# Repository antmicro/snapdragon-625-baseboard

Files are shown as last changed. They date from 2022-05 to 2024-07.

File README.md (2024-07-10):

# Antmicro's open source SC606T (Snapdragon 625) Baseboard

Copyright (c) 2022-2024 [Antmicro](https://www.antmicro.com)



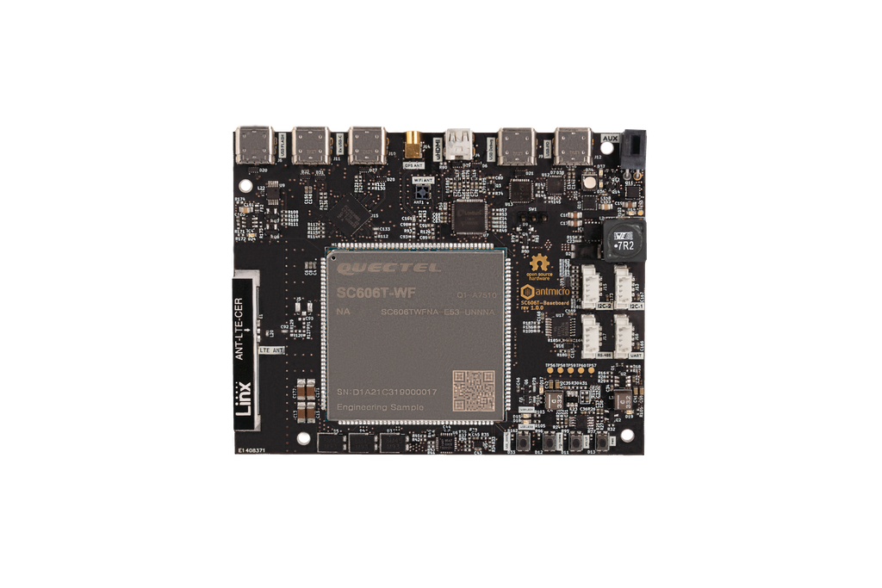
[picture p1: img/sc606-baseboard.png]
Baseboard visualization


## Overview

This repository contains open hardware design files for an experimental development board for Quectel [SC606T Smart Module](https://www.quectel.com/product/lte-sc606t-smart-module-series) featuring Qualcomm [Snapdragon 625 Mobile Platform](https://www.qualcomm.com/products/application/smartphones/snapdragon-6-series-mobile-platforms/snapdragon-625-mobile-platform).
This development board break-routes the relevant I/O interfaces from the smart module keeping a small mechanical outline. 
The design files were prepared in KiCad 7.

## Repository structure

The main repository directory contains KiCad PCB project files, a LICENSE and README.
The remaining files are stored in the following directories:

* `img` - contains graphics for this README
* `doc` - contains schematics in PDF format
* `assets` - contains visual assets for showcasing this design on [Open Hardware Portal](https://openhardware.antmicro.com).

## Key Features

* Quectel SC606T Smart Module with Qualcomm Snapdragon 625
* Built-in Dual-Band WiFi and Bluetooth
* Built-in Cat 6 LTE modem with multi-constellation GNSS receiver
* HDMI output implemented with on-board DSI-HDMI bridge
* DSI interface exposed on Flexible Flat Cable (FFC) connector
* USB 3.0 (Type-C) connector supporting host/otg mode
* 2x 4-lane MIPI CSI-2 camera interface

The board supports multiple power supply scenarios including:

* USB-C PD (Power Delivery)
* External PSU or battery

The on-board camera connector is electrically compatible with several video accessories created by Antmicro such as:
 
* [OV9281 Dual Camera Board](https://github.com/antmicro/ov9281-camera-board)
* [SDI-MIPI bridge](https://github.com/antmicro/sdi-mipi-bridge)
* [HDMI-MIPI bridge](https://github.com/antmicro/hdmi-mipi-bridge)

## License

[Apache-2.0](LICENSE)

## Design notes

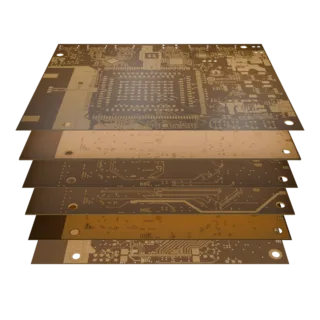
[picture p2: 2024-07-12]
assets/previews/layer1_thumbnail.webp

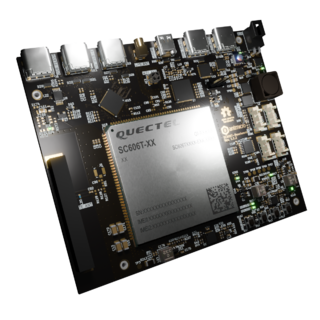
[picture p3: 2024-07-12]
assets/previews/leftT_thumbnail.png

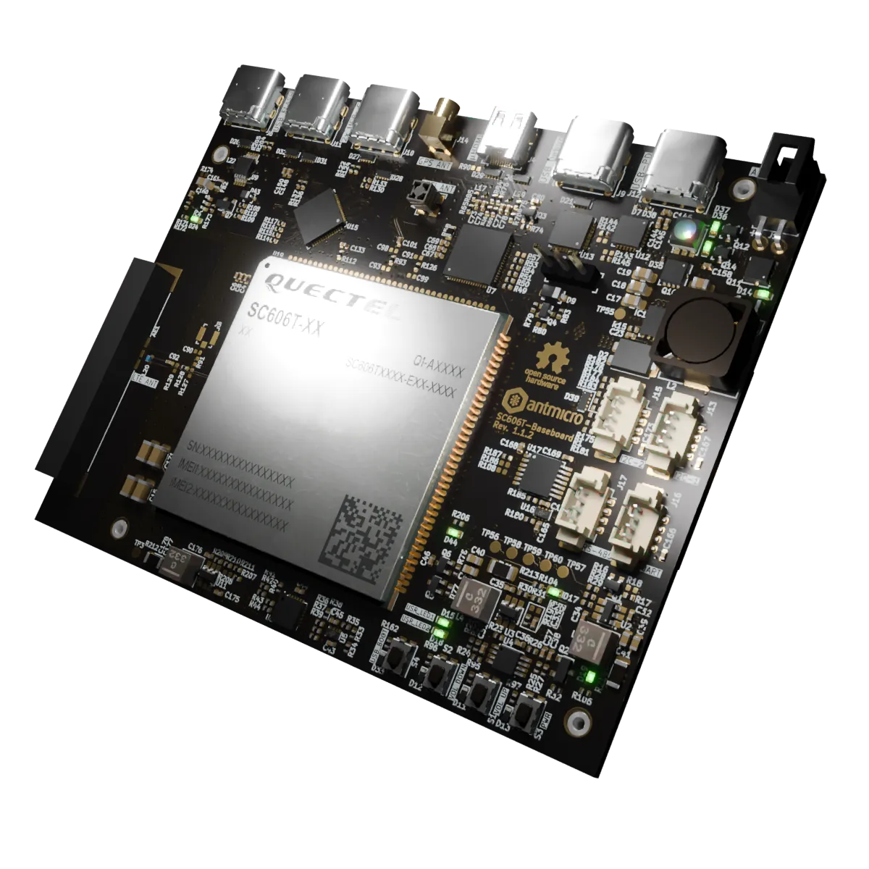
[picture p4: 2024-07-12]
assets/previews/rightT.webp

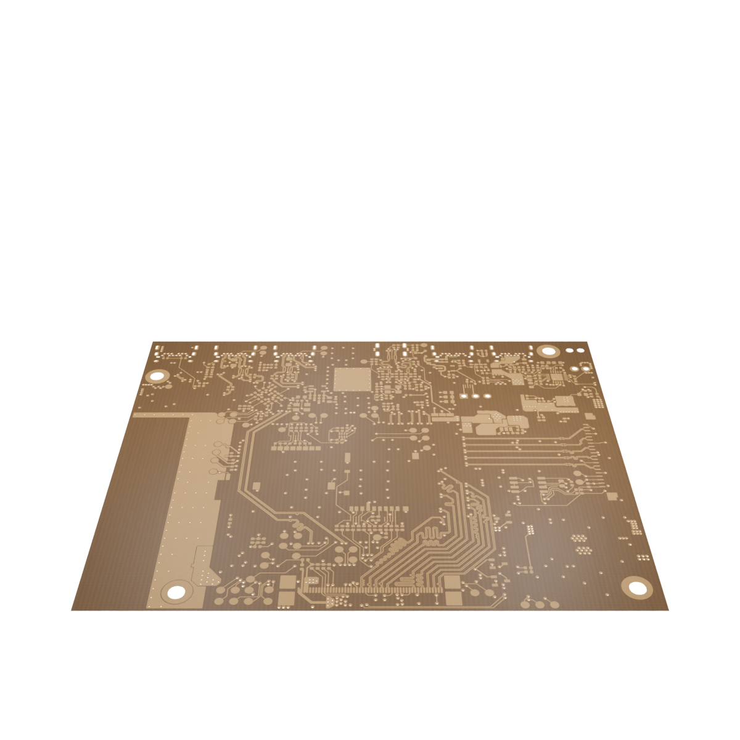
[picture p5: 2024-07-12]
assets/previews/layer6.png

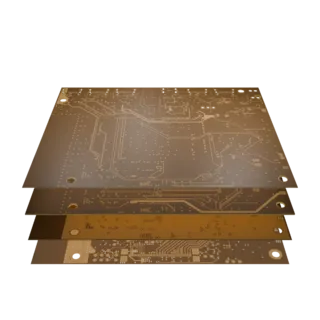
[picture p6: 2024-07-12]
assets/previews/layer3_thumbnail.webp

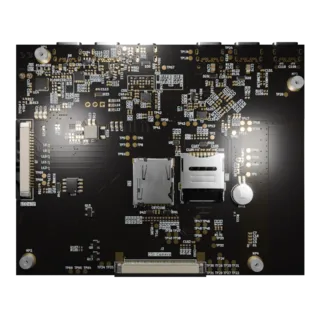
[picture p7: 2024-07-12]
assets/previews/orthoB_thumbnail.webp

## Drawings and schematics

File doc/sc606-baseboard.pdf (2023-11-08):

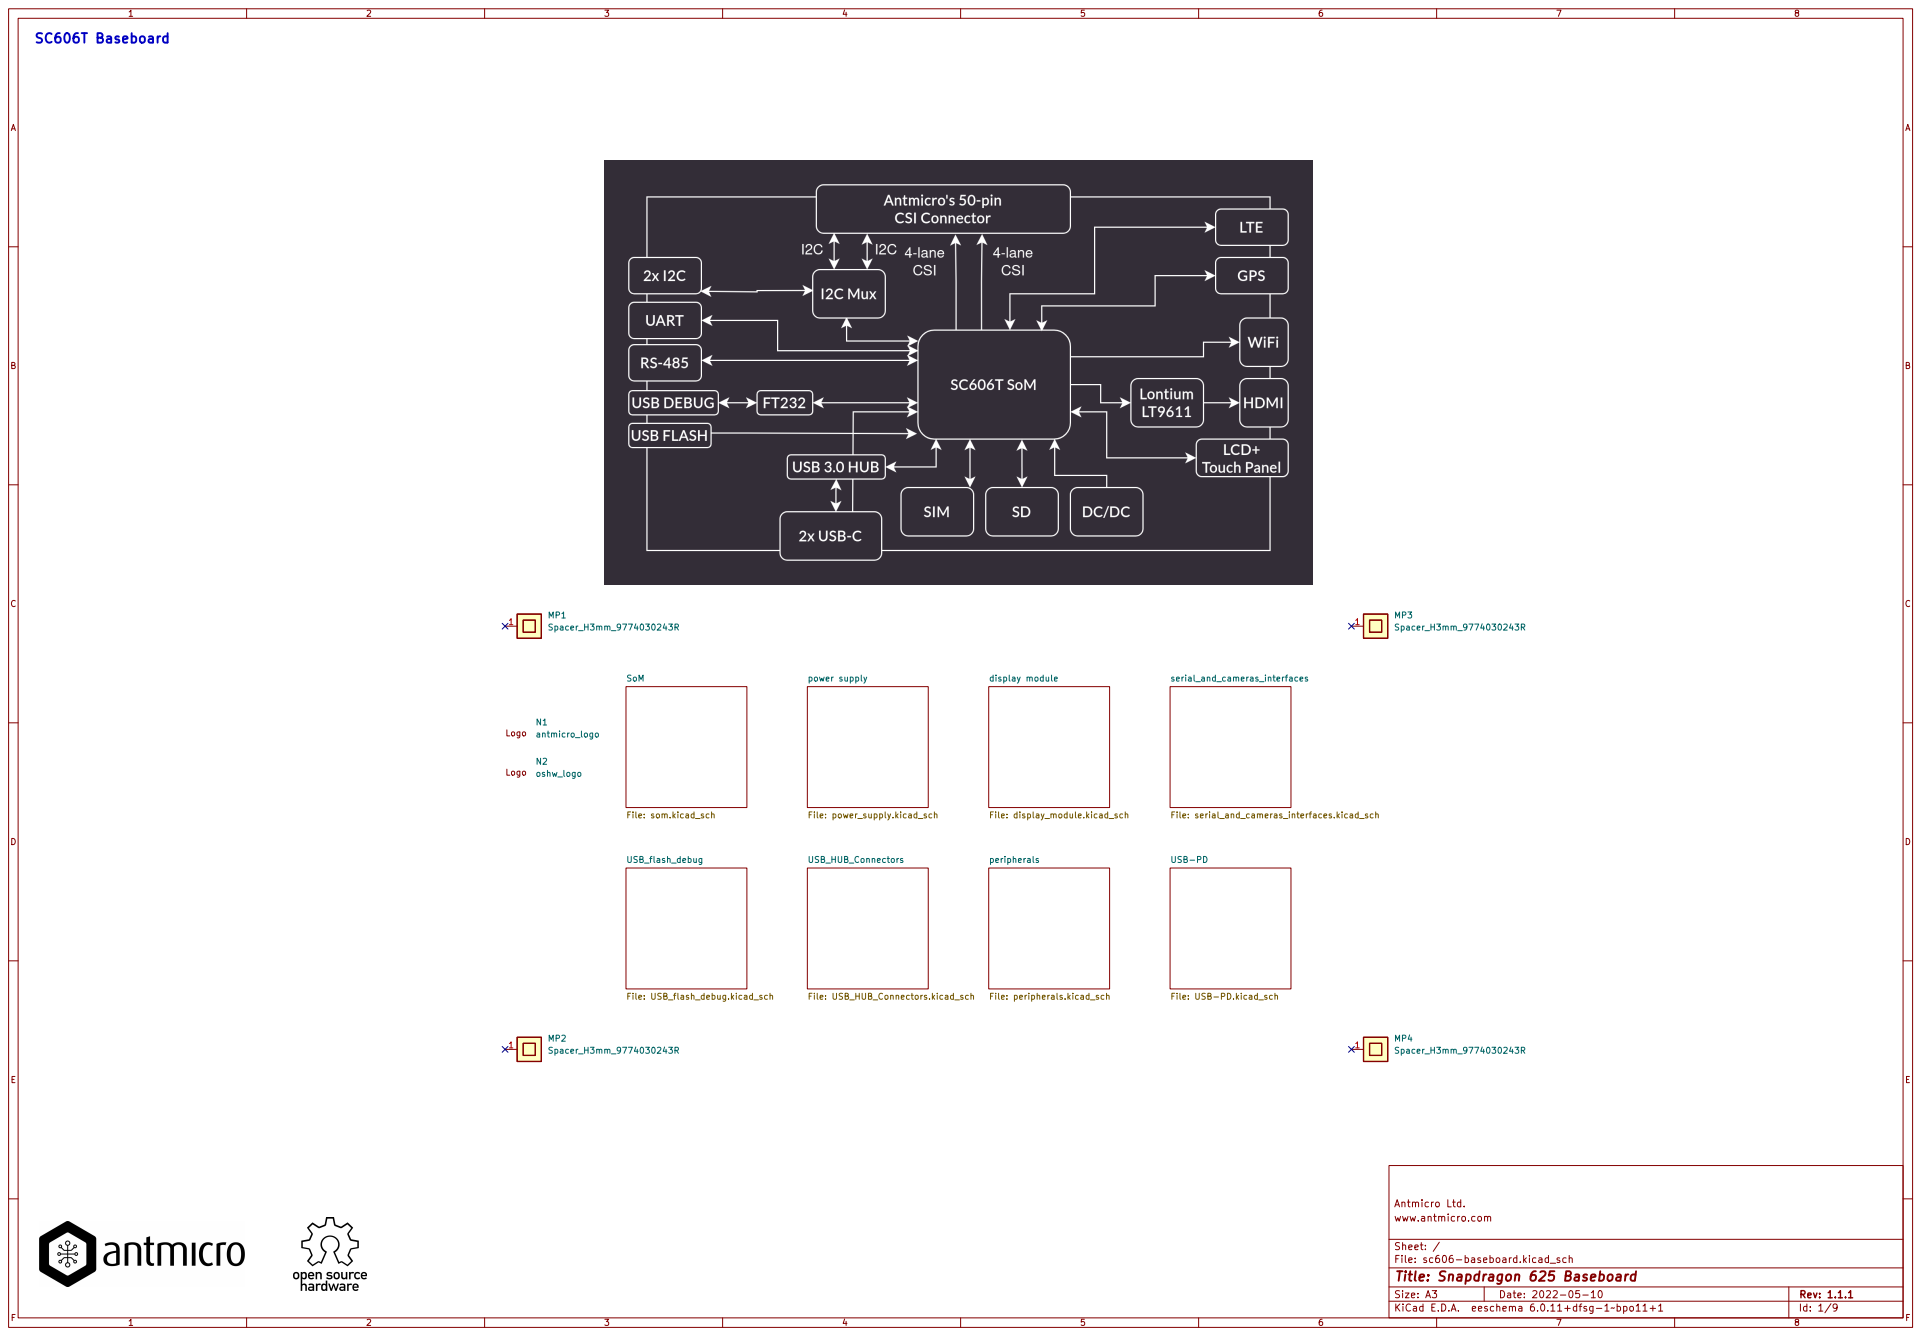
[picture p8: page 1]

display module File: display_module.kicad_sch SoM

File: USB-PD.kicad_sch USB_HUB_Connectors File: USB_HUB_Connectors.kicad_sch

File: sc606-baseboard.kicad_sch Sheet: / www.antmicro.com

Id: 1/9 Title: Snapdragon 625 Baseboard

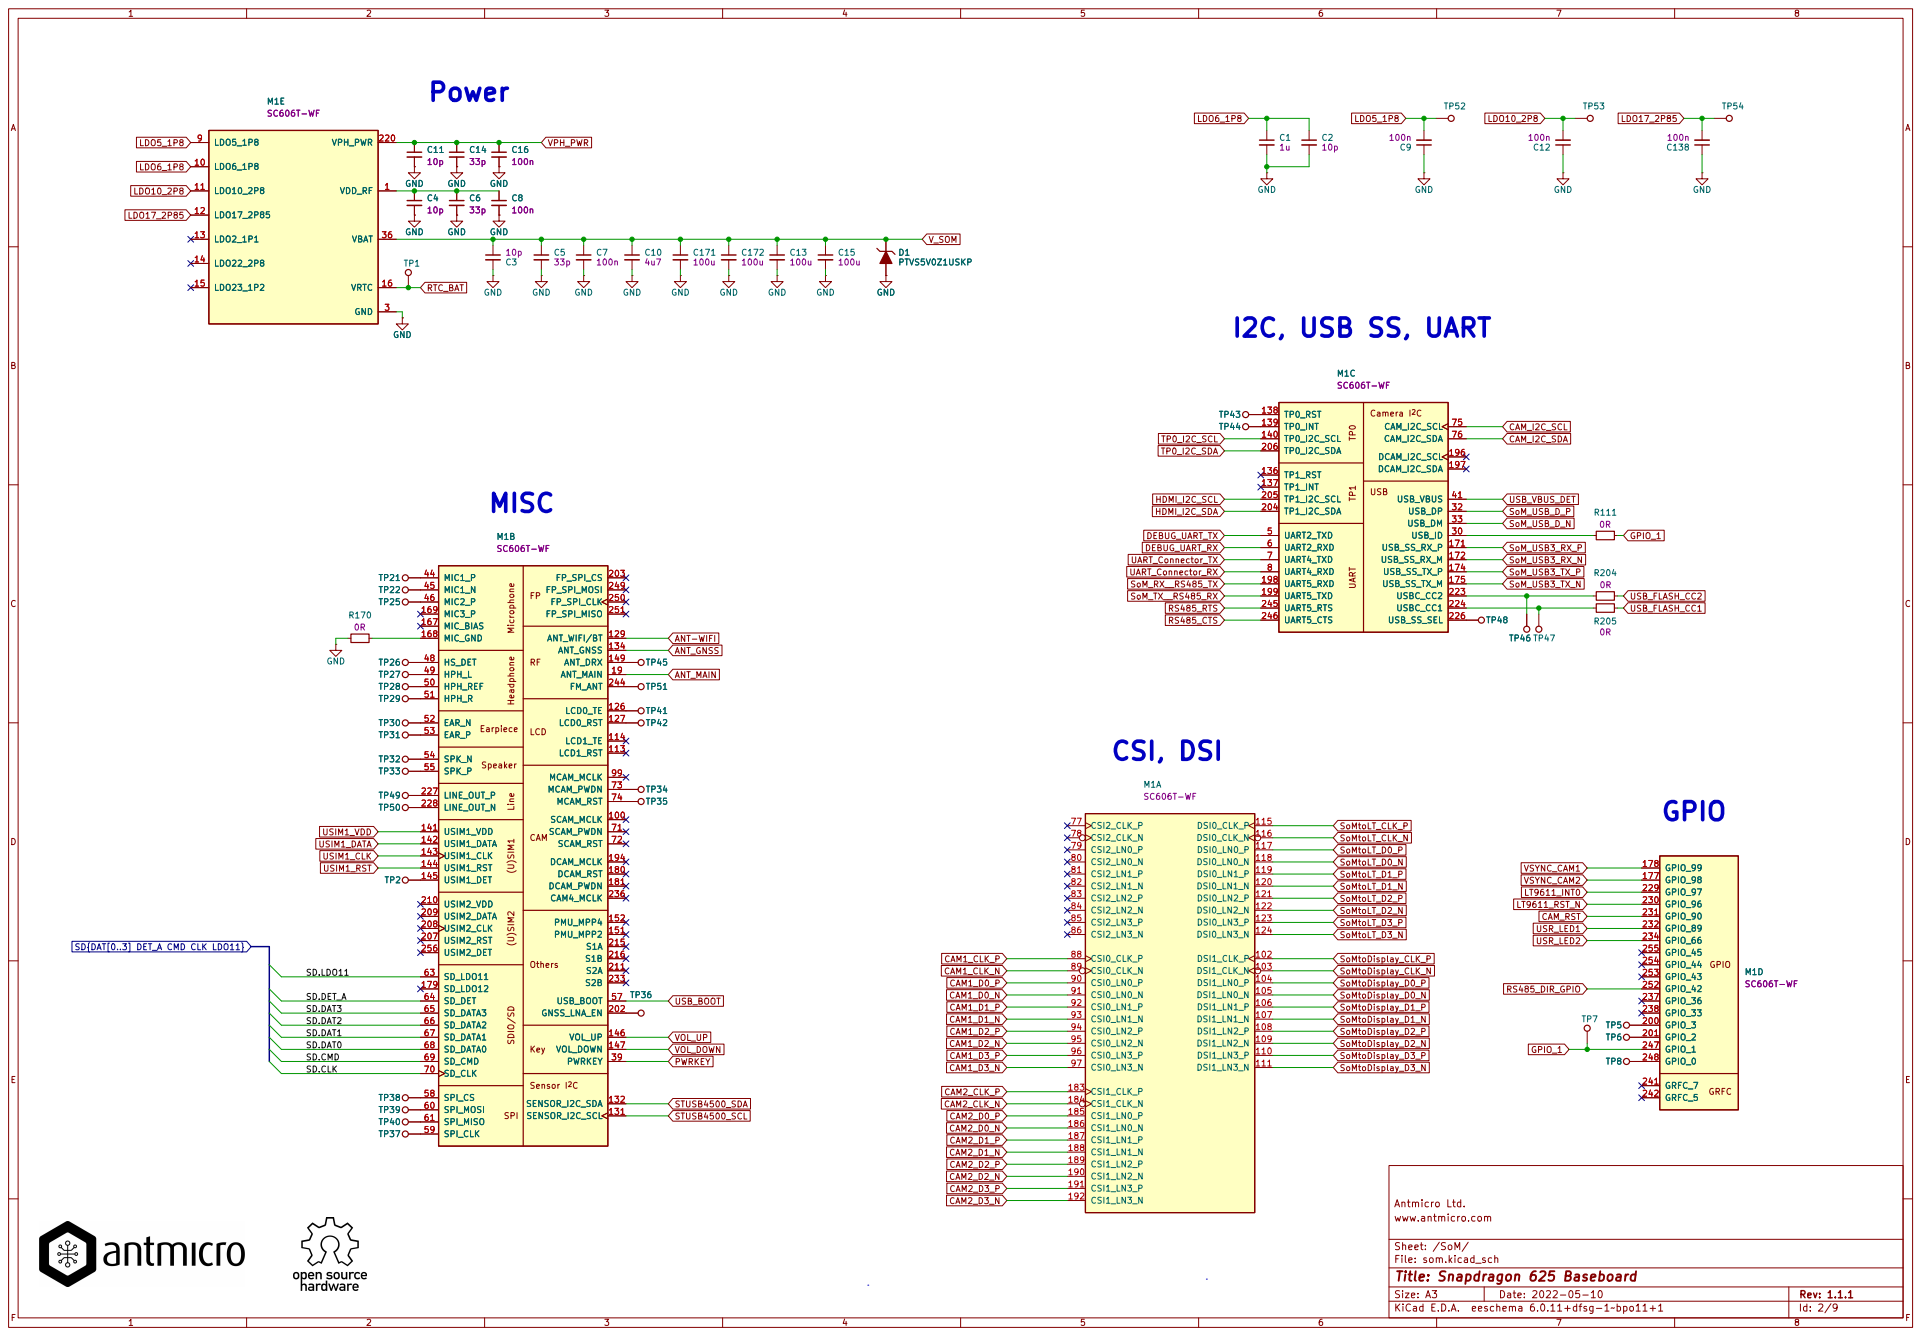
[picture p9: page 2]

SD.DAT2 SD.DAT1 SD.DAT0 SD.CMD

File: som.kicad_sch Sheet: /SoM/ www.antmicro.com

Id: 2/9 Title: Snapdragon 625 Baseboard

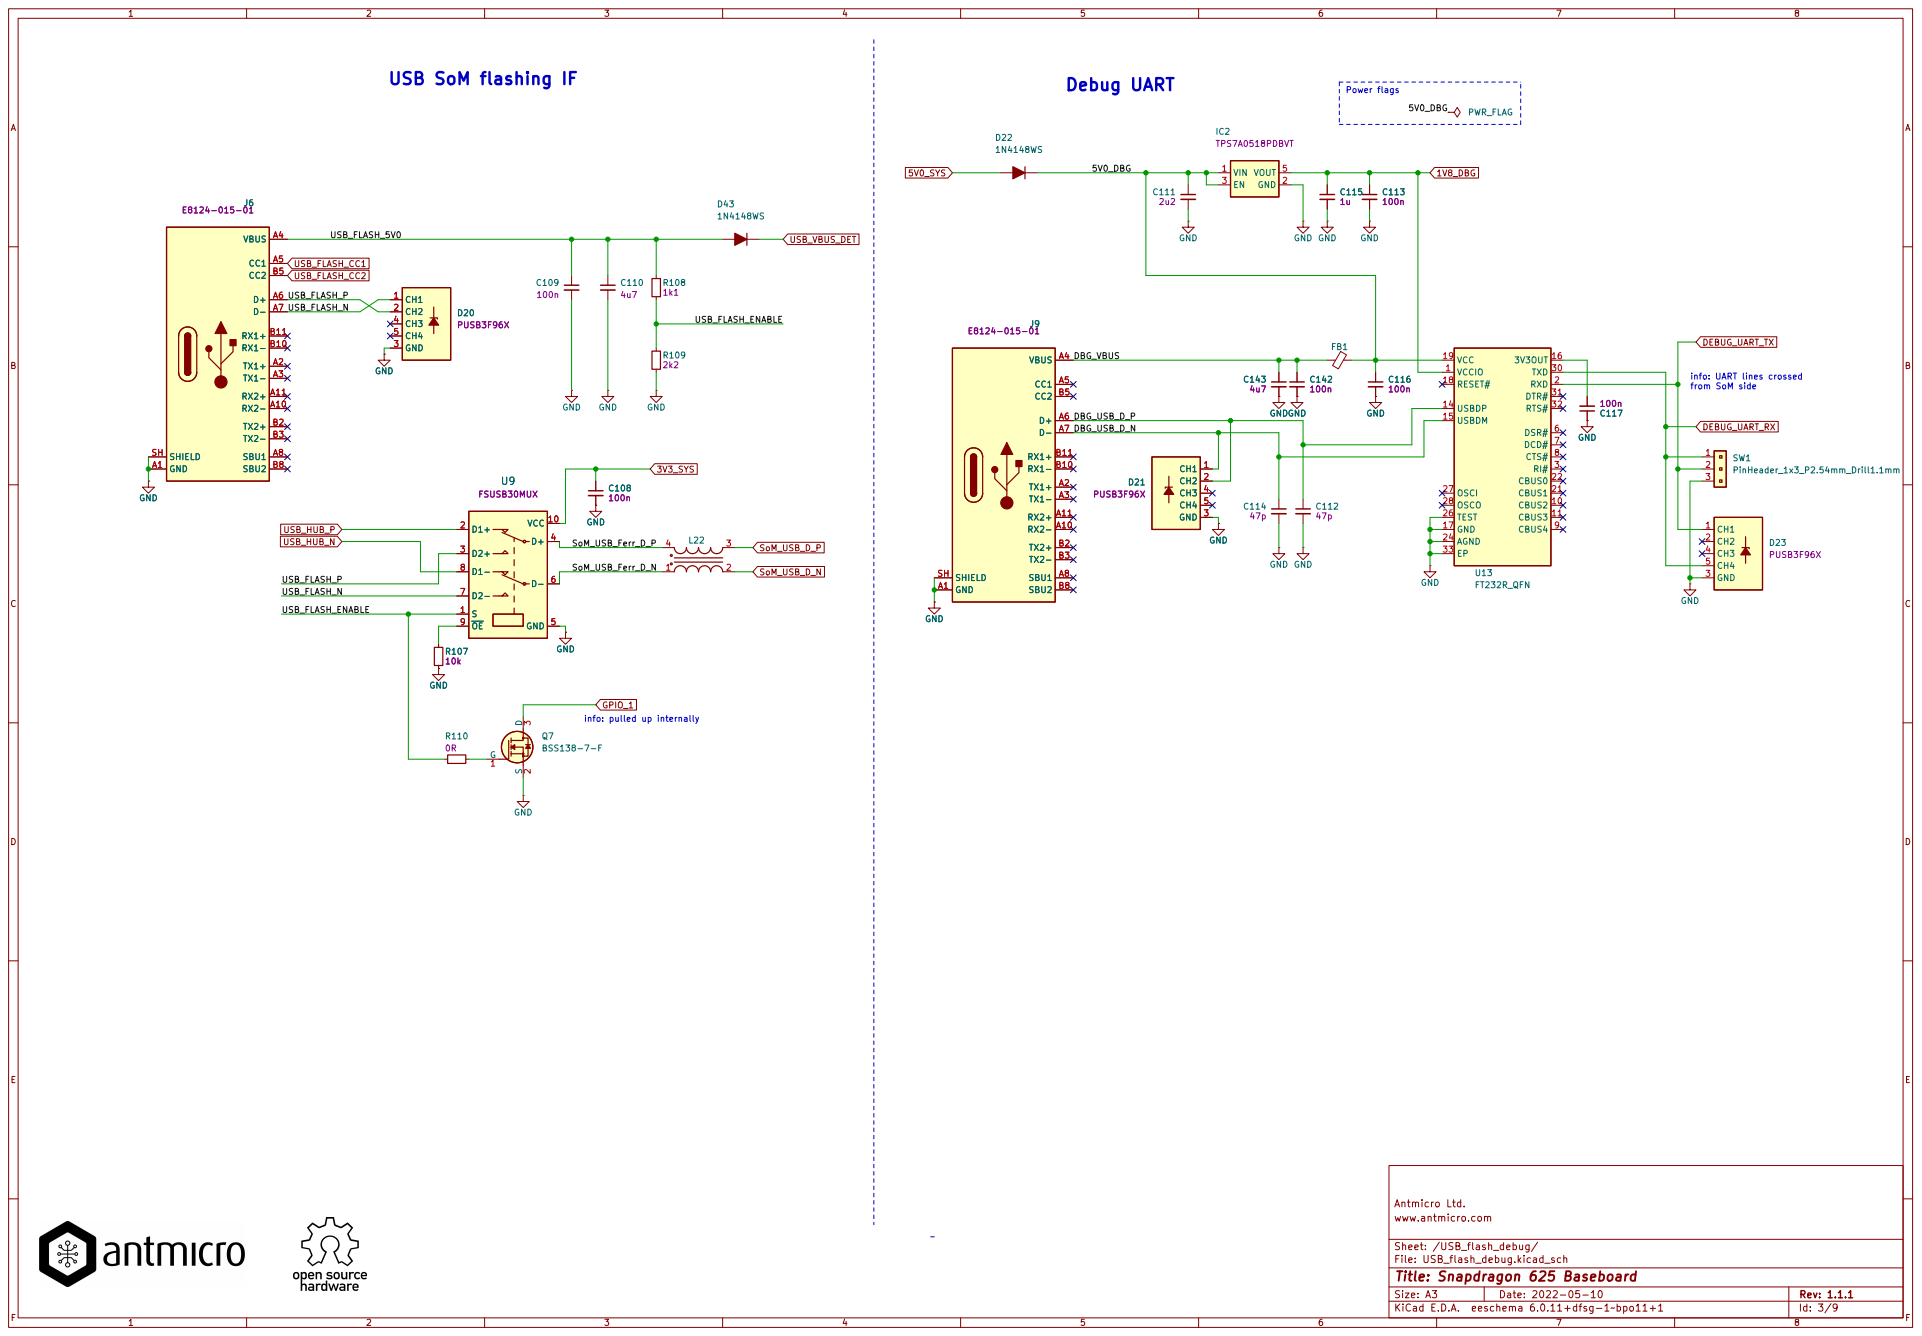
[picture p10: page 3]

3 Q7 BSS138-7-F GND GND GND GND A1 RX2- A10 RX2+ A11 TX1+ A2 TX1- A3 VBUS A4 CC1 A5 D+ A6 D- A7 SBU1 A8 RX1- B10 RX1+ B11 TX2+ B2 TX2- B3 CC2 B5 SBU2 B8 SHIELD SH

from SoM side GND U9

info: UART lines crossed

info: pulled up internally

File: USB_flash_debug.kicad_sch Sheet: /USB_flash_debug/ www.antmicro.com

Id: 3/9 Title: Snapdragon 625 Baseboard

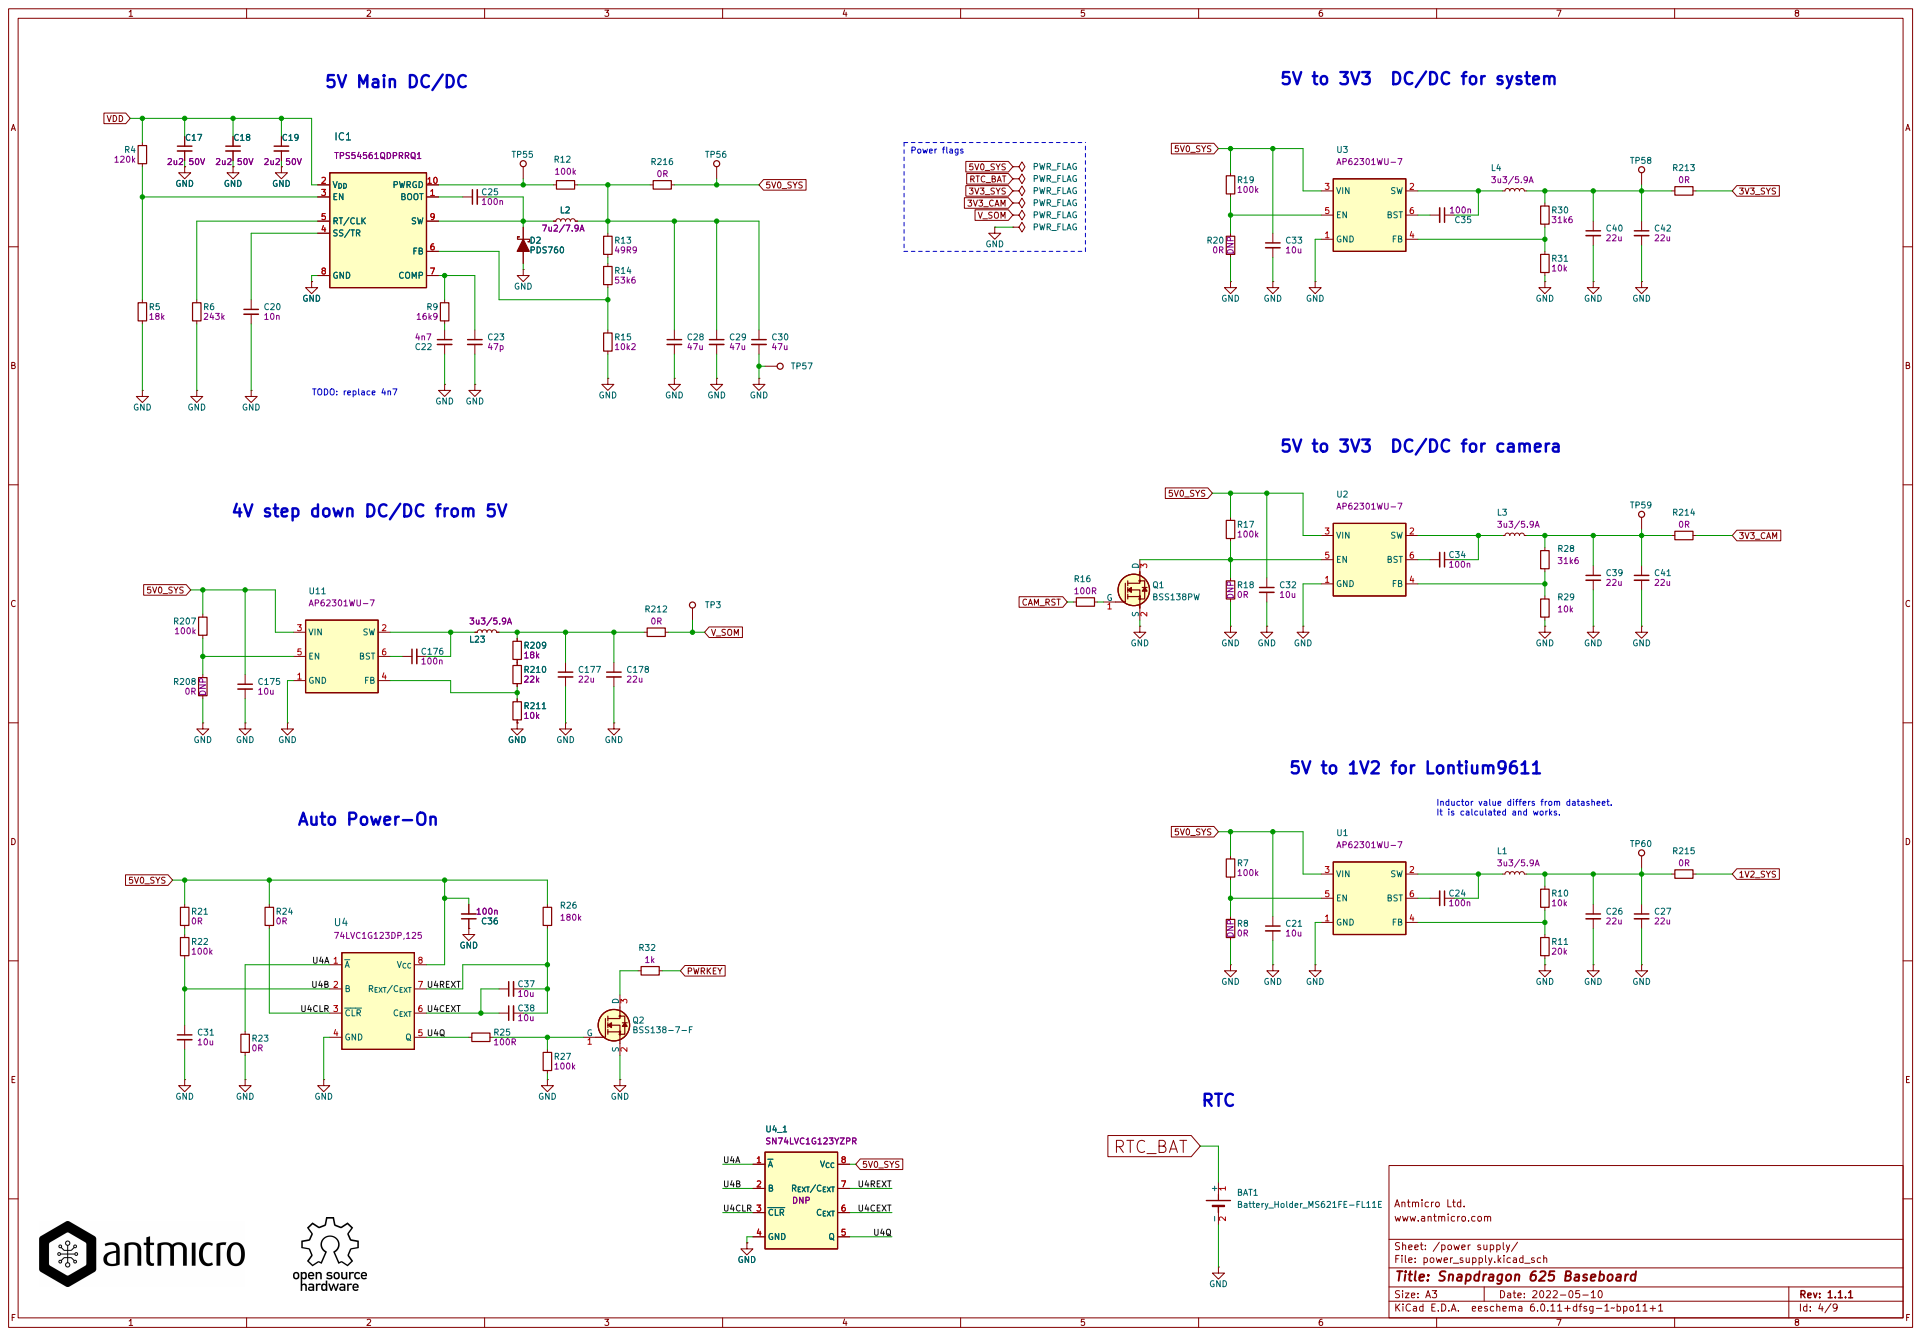
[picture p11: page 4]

4V step down DC/DC from 5V

5 C_{EXT} 6 R_{EXT}/C_{EXT} 7 V_{CC} 8 U4
74LVC1G123DP,125

5 C_{EXT} 6 R_{EXT}/C_{EXT} 7 V_{CC} 8 U4_1 SN74LVC1G123YZPR

5 C_{EXT} 6 R_{EXT}/C_{EXT} 7 V_{CC} 8 GND

Id: 4/9 Title: Snapdragon 625 Baseboard

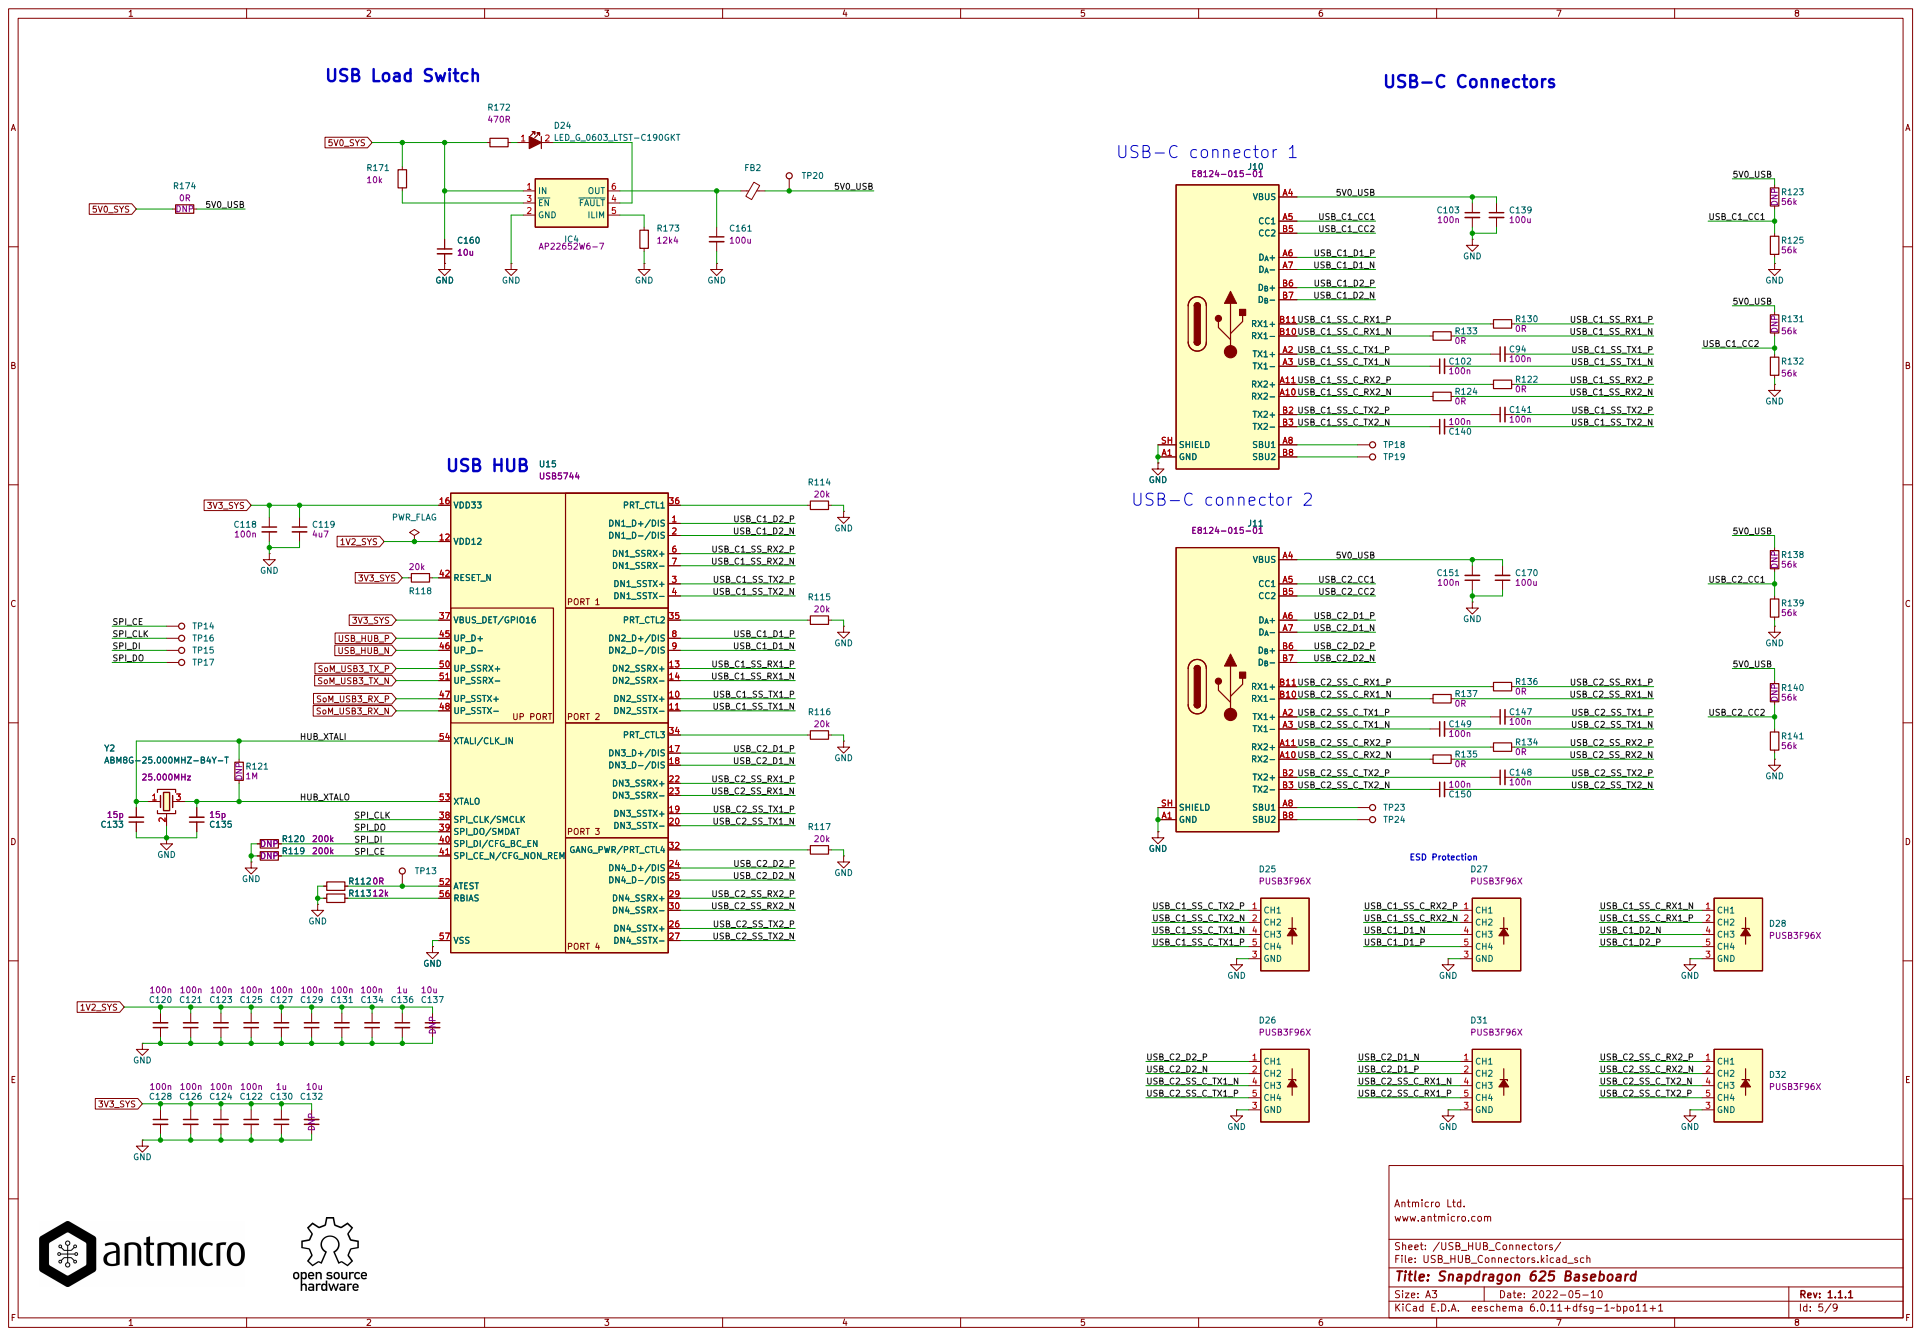
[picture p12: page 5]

File: USB_HUB_Connectors.kicad_sch Sheet: /USB_HUB_Connectors/ www.antmicro.com

Id: 5/9 Title: Snapdragon 625 Baseboard

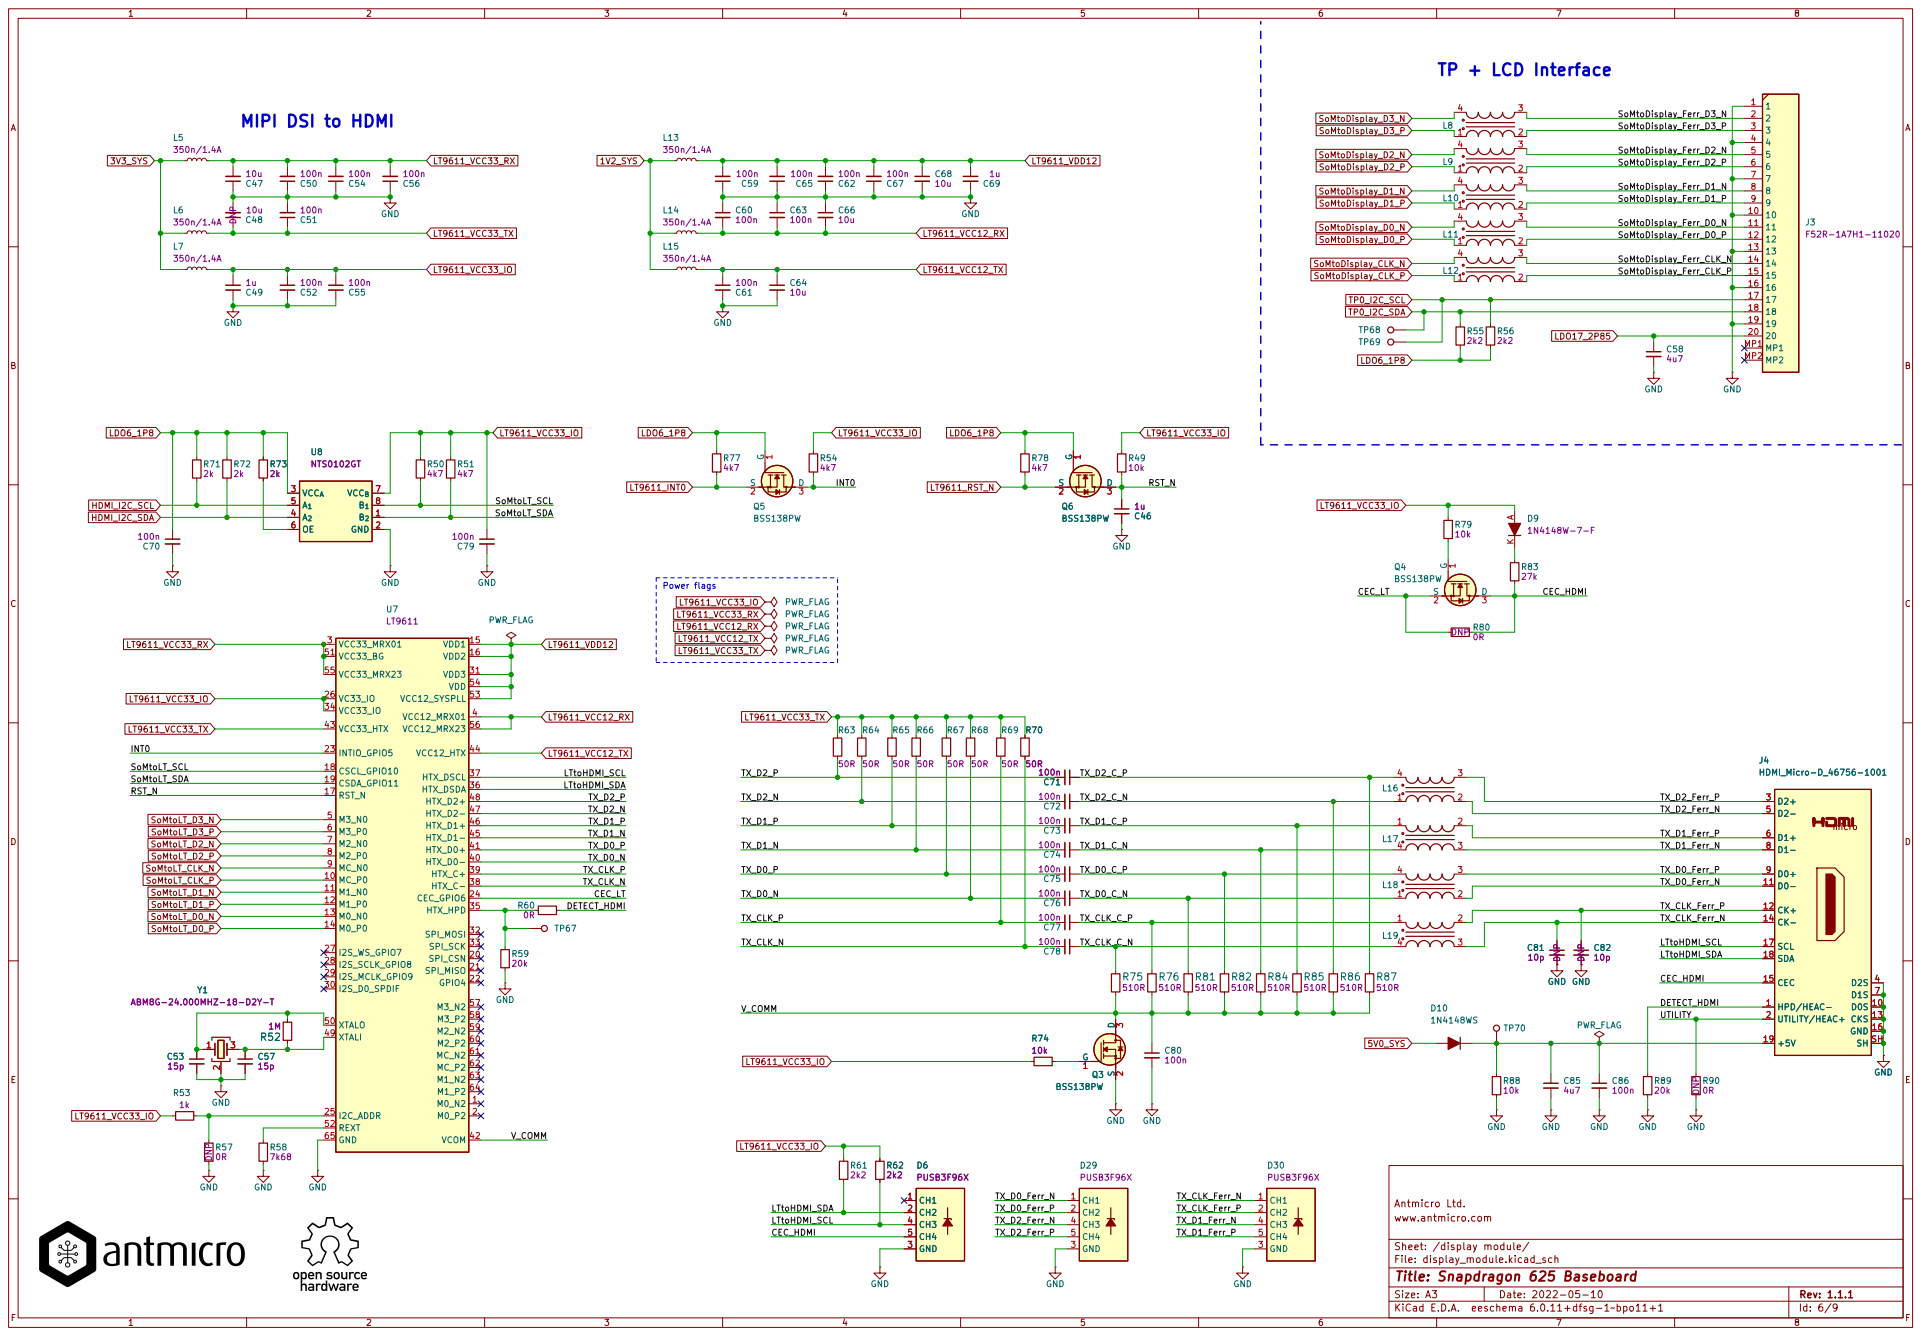
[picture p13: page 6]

MIPI DSI to HDMI

Id: 6/9 Title: Snapdragon 625 Baseboard

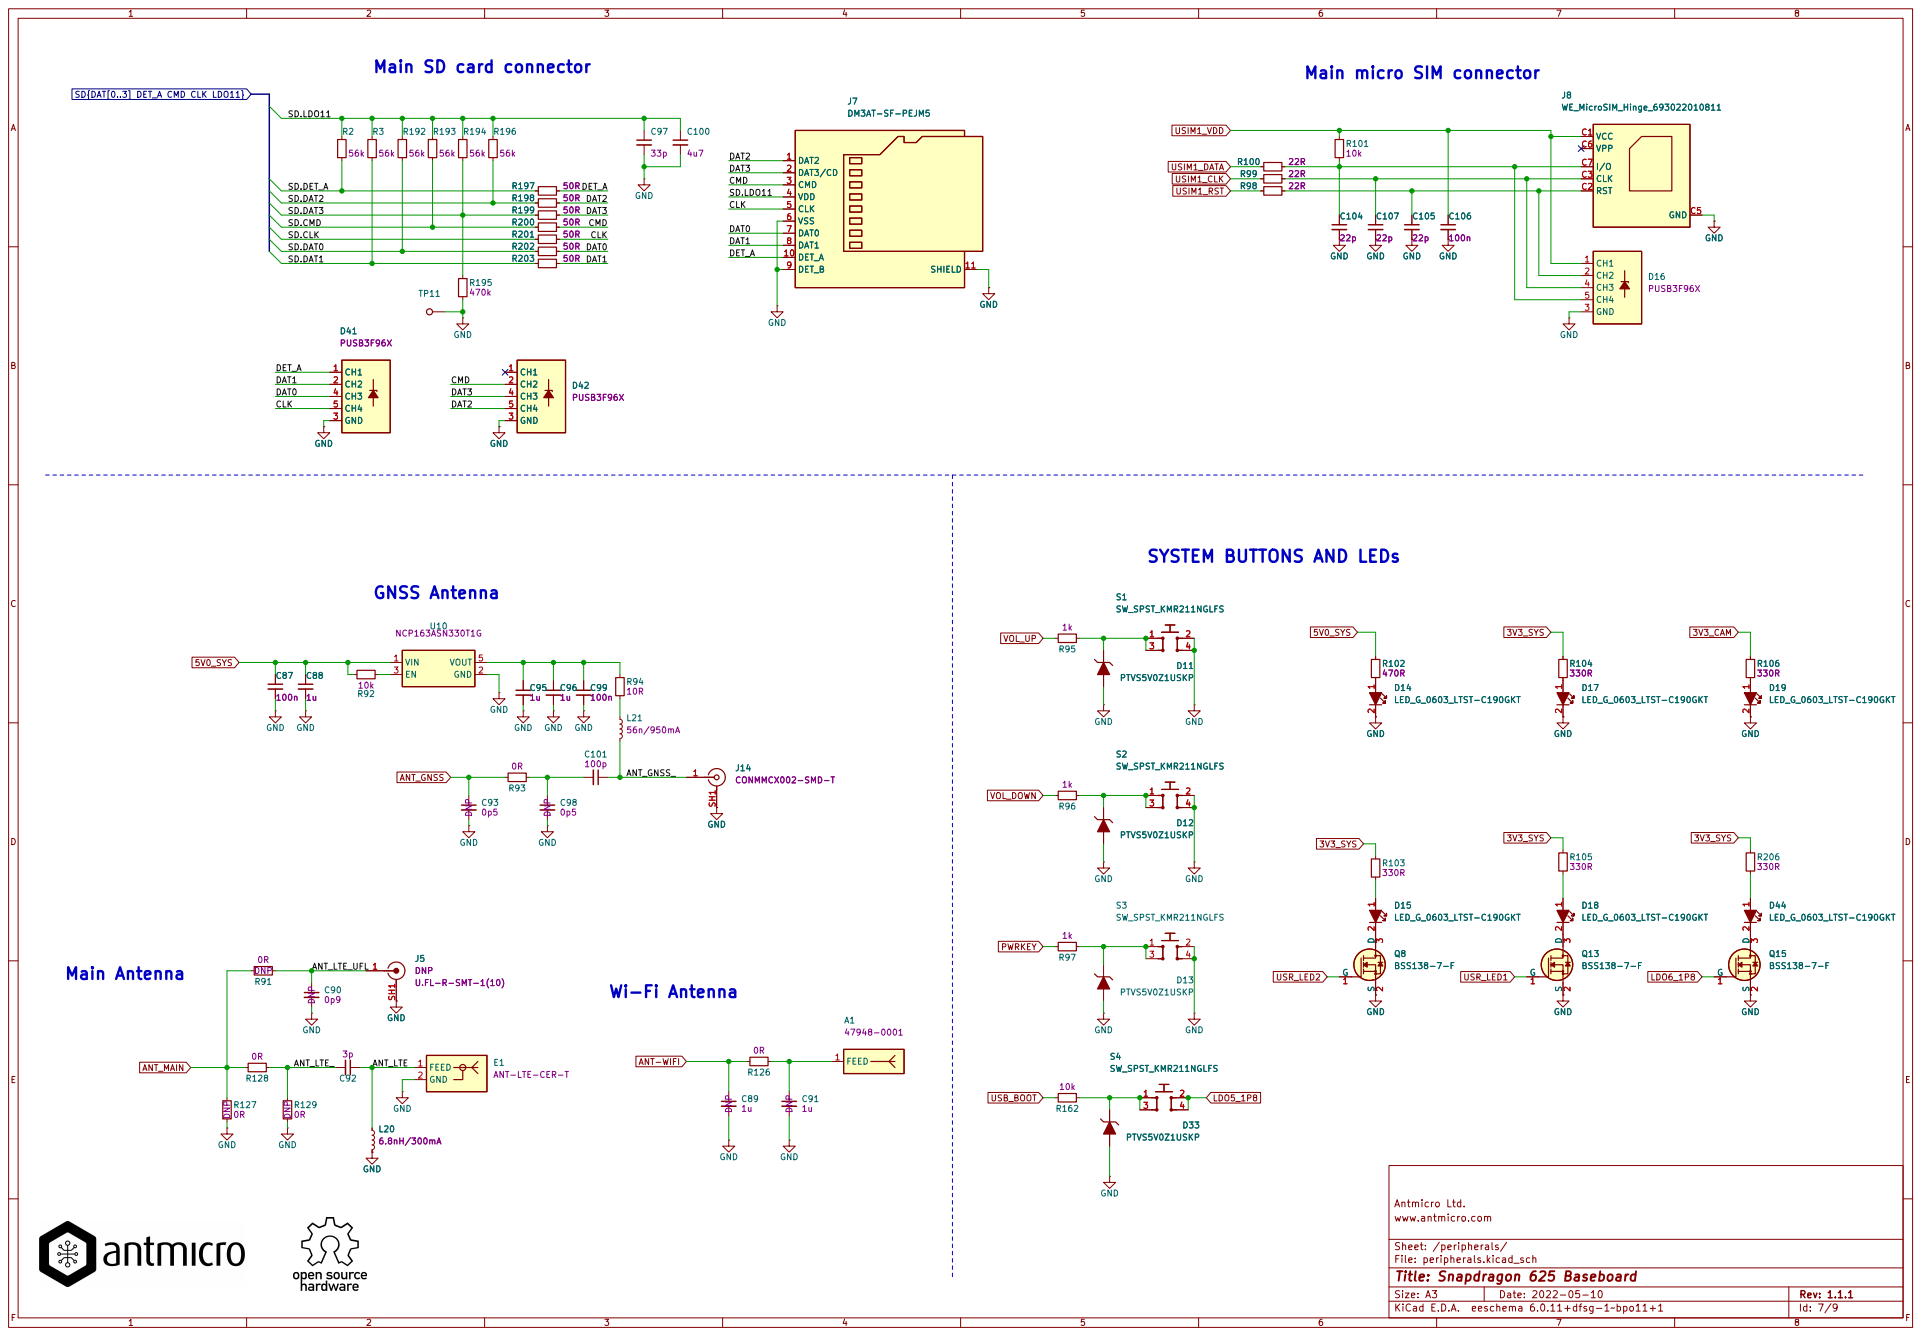
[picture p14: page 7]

J5U.FL-R-SMT-1(10) DNP GND

Id: 7/9 Title: Snapdragon 625 Baseboard

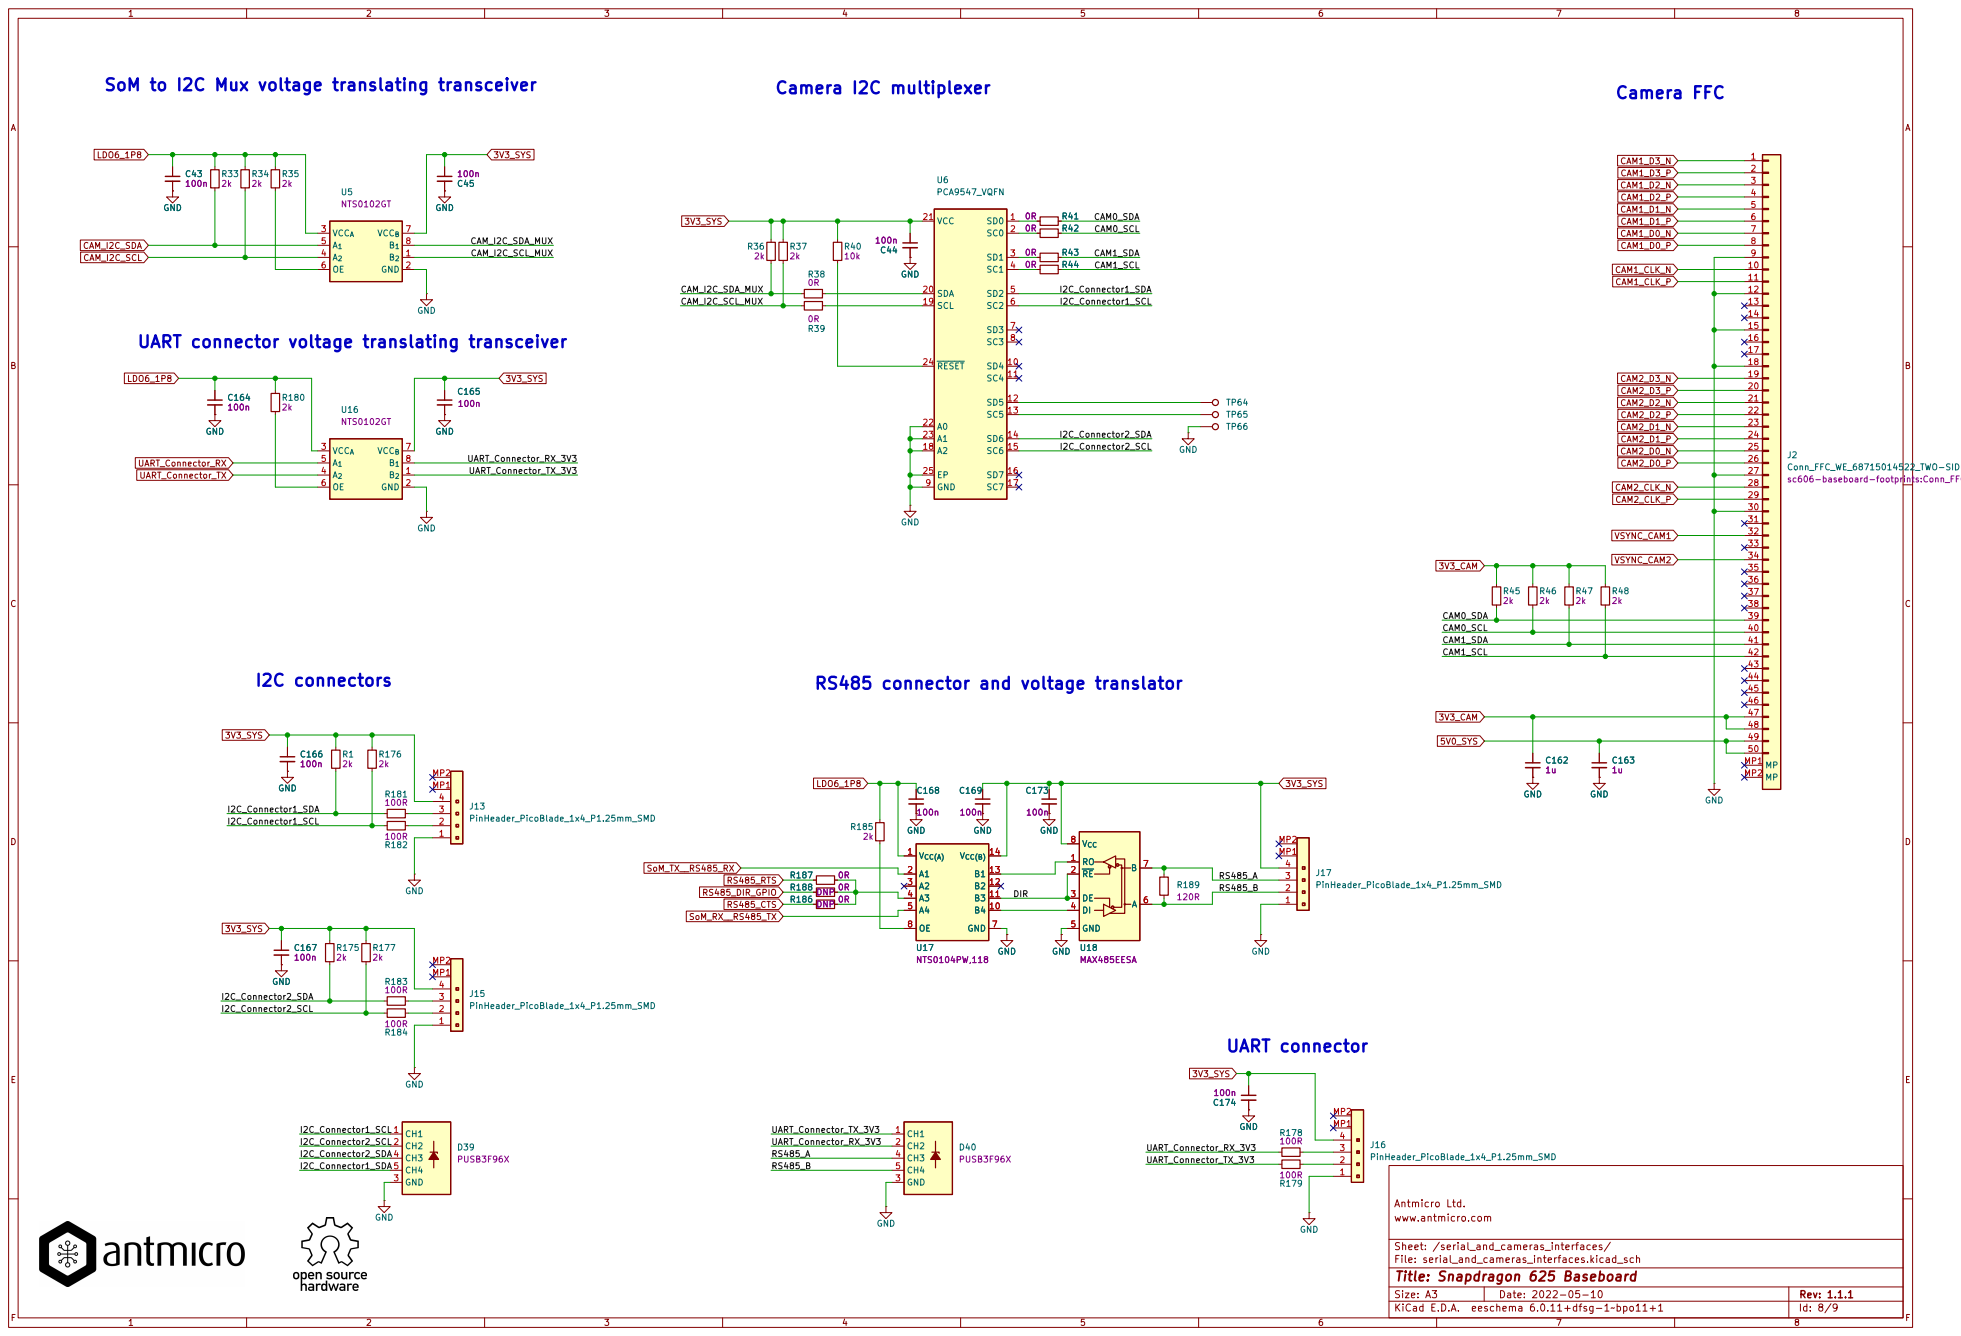
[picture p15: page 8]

40
41
42

File: serial_and_cameras_interfaces.kicad_sch Sheet: /serial_and_cameras_interfaces/ www.antmicro.com

Id: 8/9 Title: Snapdragon 625 Baseboard

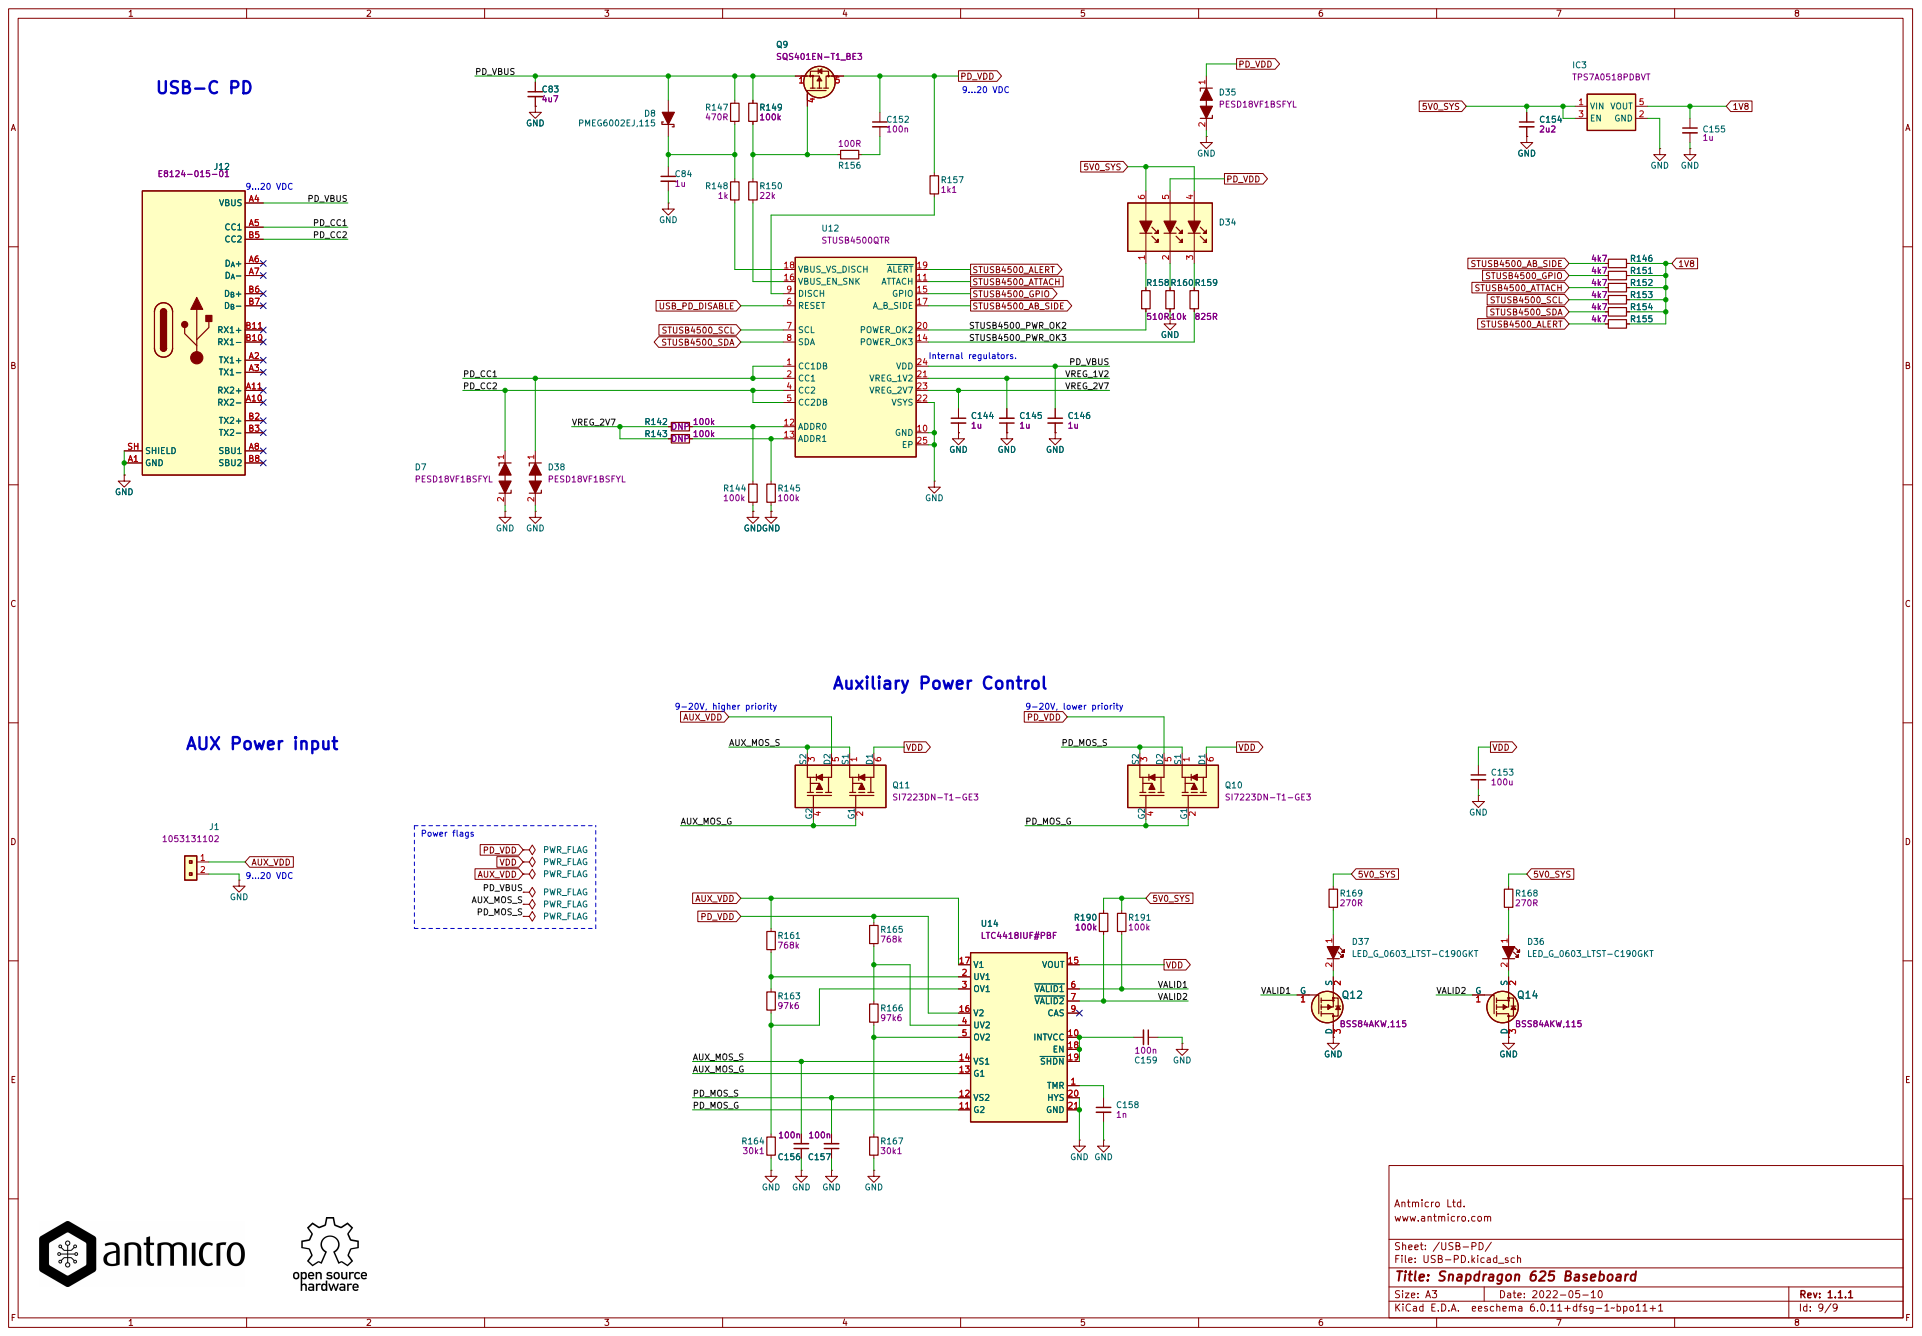
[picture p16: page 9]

5 Q9 SQS401EN-T1_BE3
9...20 VDC Auxiliary Power Control

File: USB-PD.kicad_sch Sheet: /USB-PD/ www.antmicro.com

Id: 9/9 Title: Snapdragon 625 Baseboard

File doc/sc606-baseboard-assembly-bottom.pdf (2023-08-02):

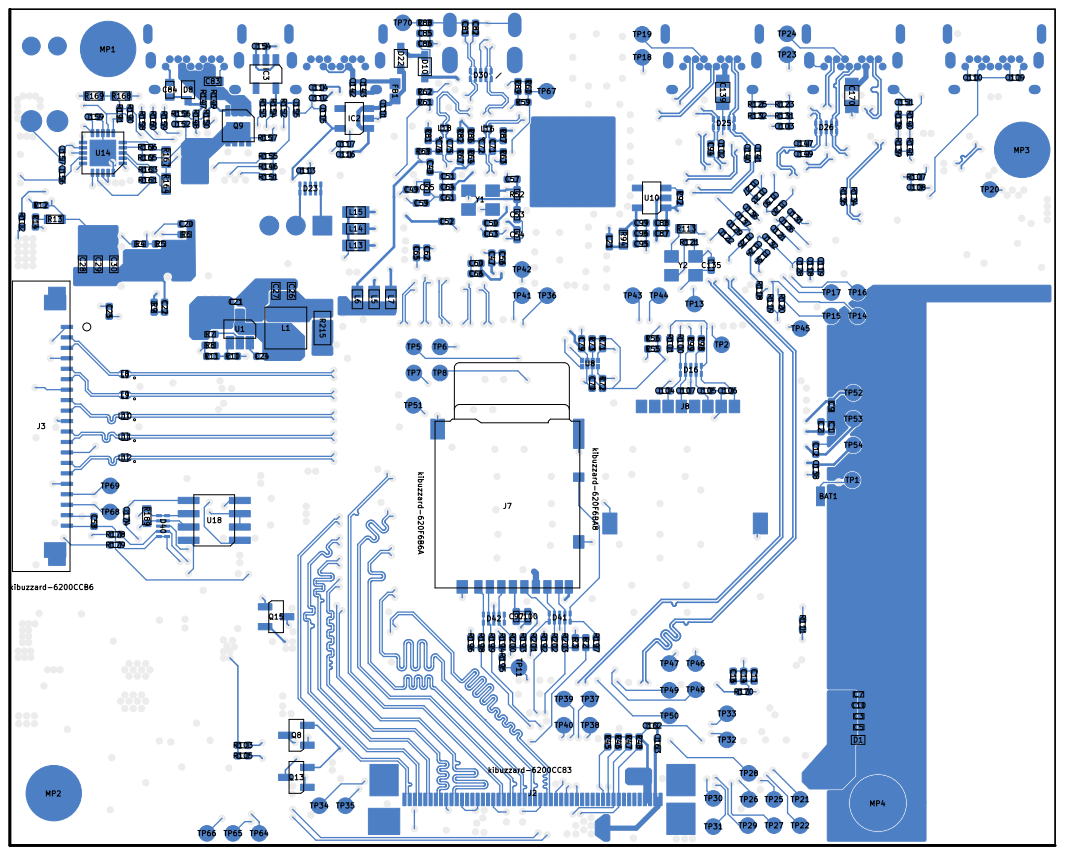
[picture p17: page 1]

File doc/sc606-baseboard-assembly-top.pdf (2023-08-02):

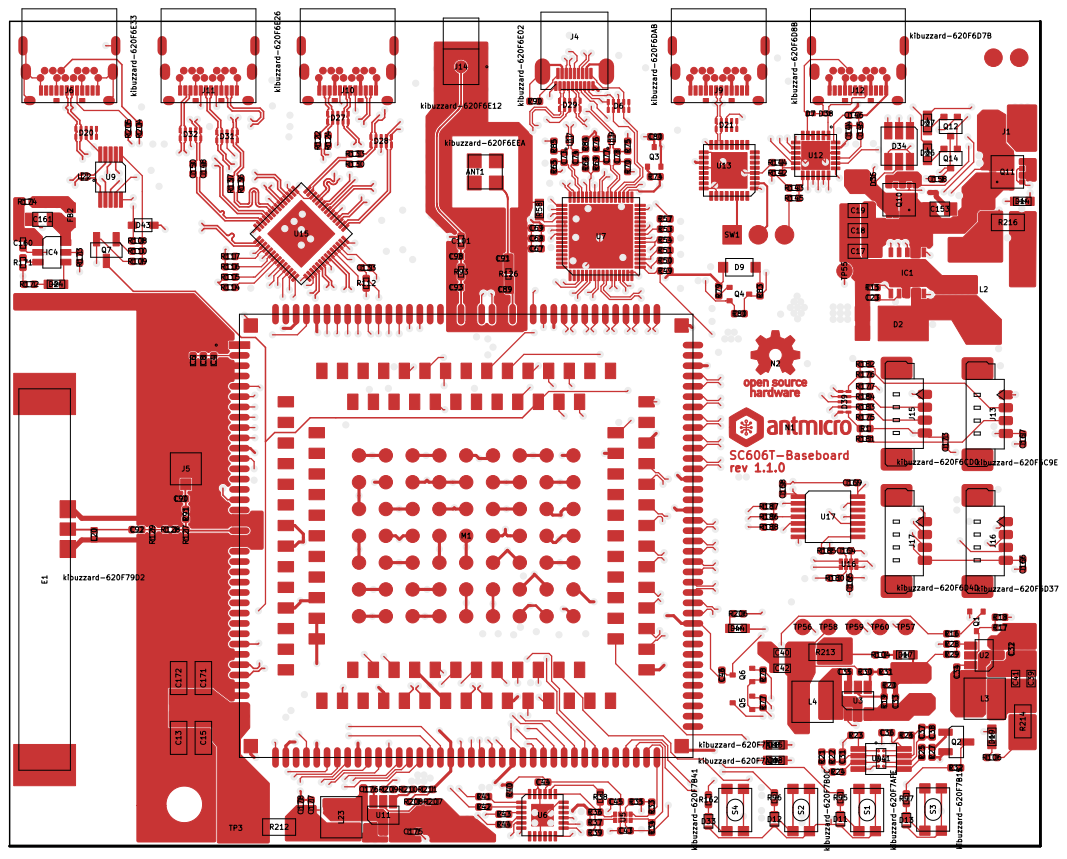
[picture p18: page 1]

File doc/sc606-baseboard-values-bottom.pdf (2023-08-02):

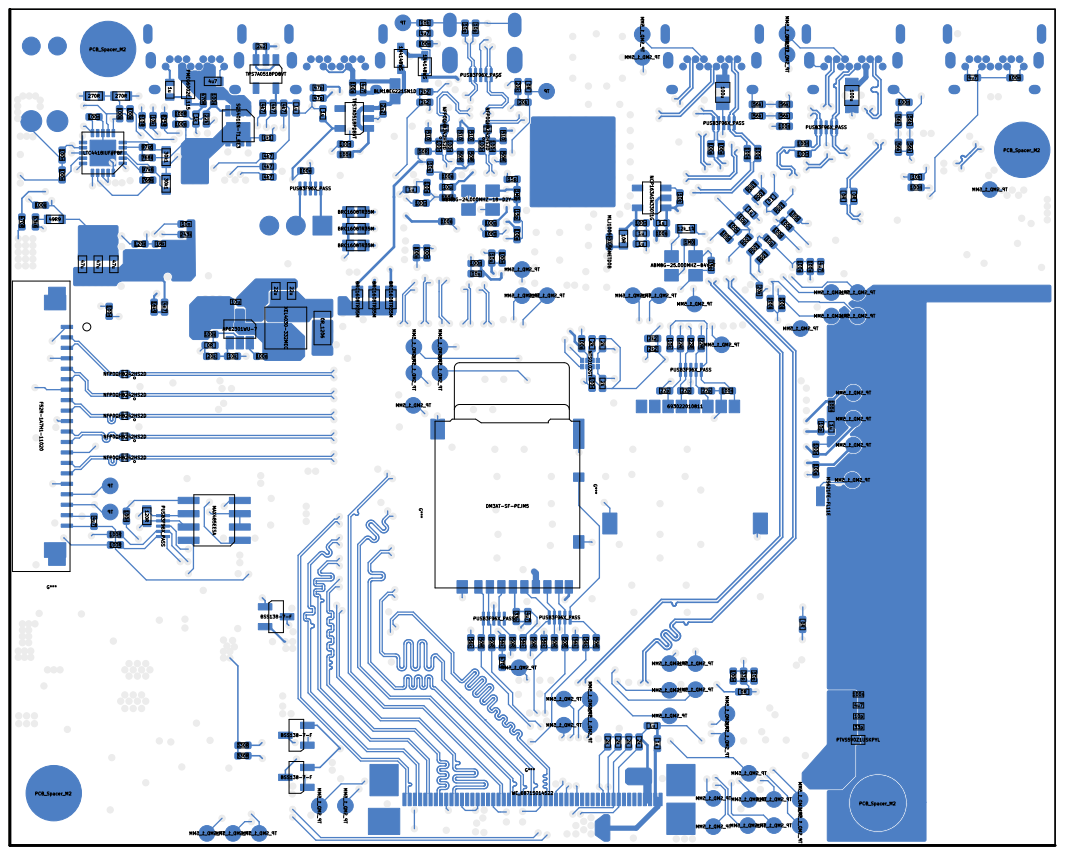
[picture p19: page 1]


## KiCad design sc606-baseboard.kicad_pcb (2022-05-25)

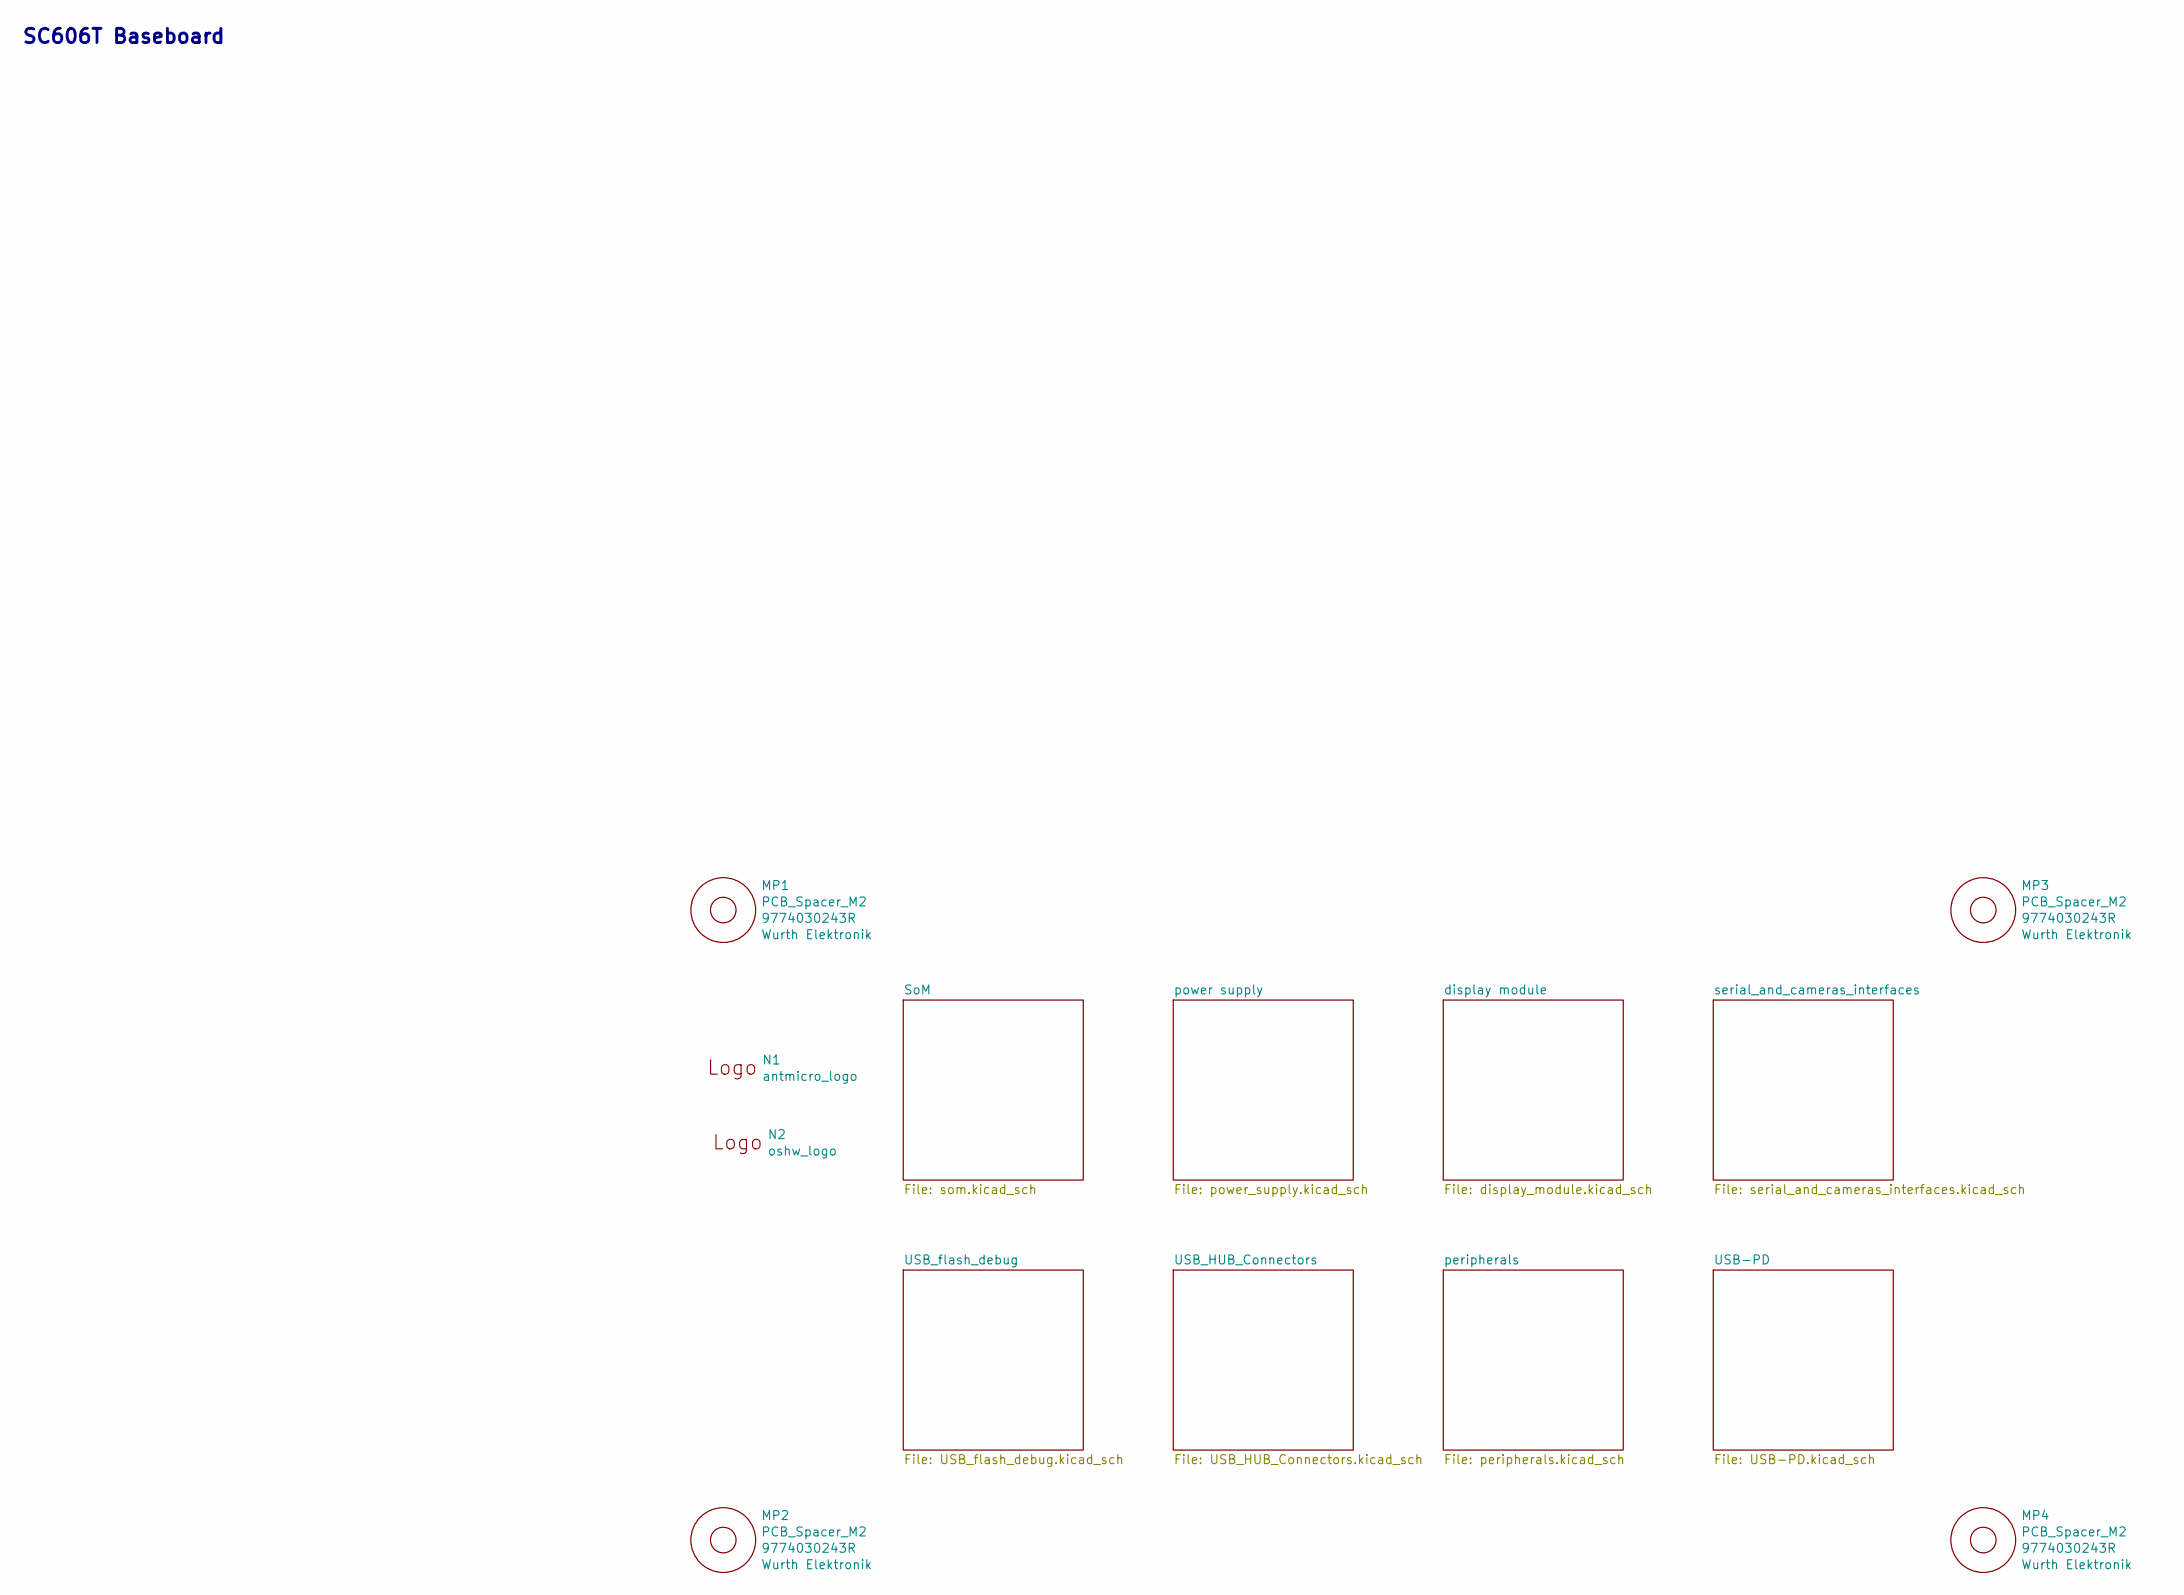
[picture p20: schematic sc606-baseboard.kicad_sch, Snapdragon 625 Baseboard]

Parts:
MP1, MP2, MP3, MP4: PCB_Spacer_M2; 9774030243R; MPN 9774030243R
N1: antmicro_logo; antmicro-logo_scaled_12mm
N2: oshw_logo; oshw-logo

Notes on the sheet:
SC606T Baseboard

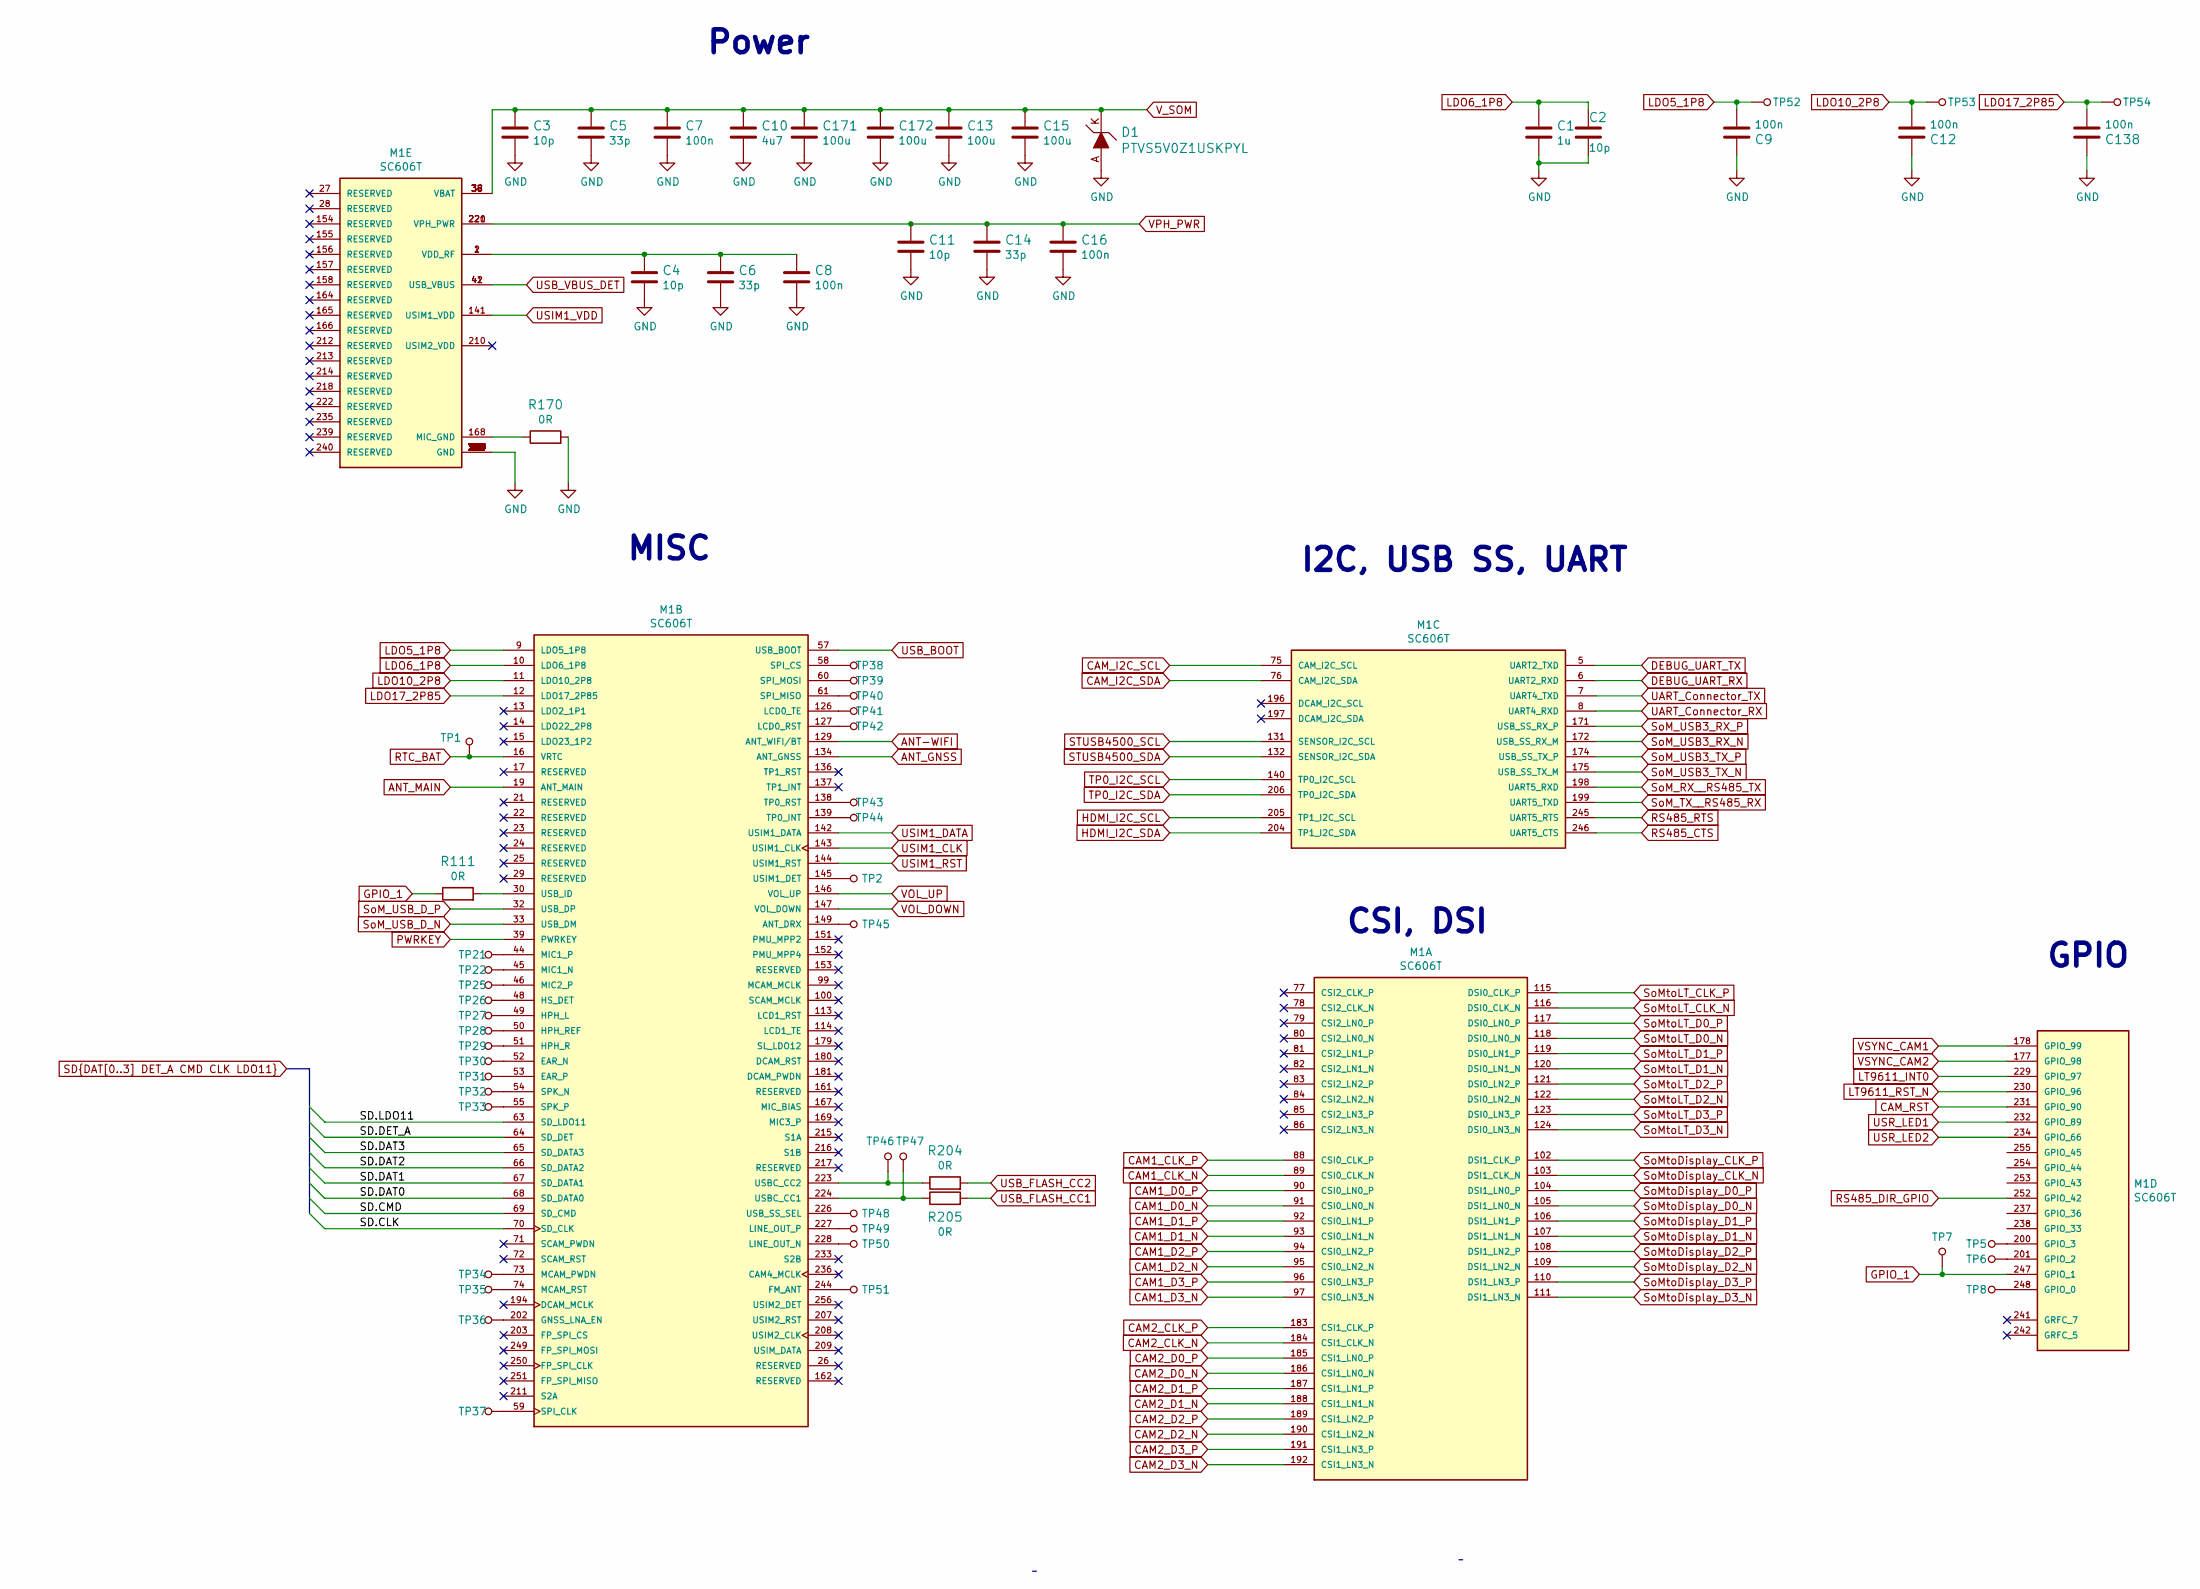
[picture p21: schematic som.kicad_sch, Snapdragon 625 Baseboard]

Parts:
C1: C_1u_0402; 0402-cap; MPN C1005X6S1A105K050BC
C2, C3, C4, C11: C_10p_0402; 0402-cap; MPN MC0402N100D500CT
C5, C6, C14: C_33p_0402; 0402-cap; MPN MC0402N330J500CT
C7, C8, C9, C12, C16, C138: C_100n_0402; 0402-cap; MPN 0402X104K6R3CT
C10: C_4u7_0402; 0402-cap; MPN GRM155R61A475MEAAD
C13, C15, C171, C172: C_100u_1206; 1206-cap; MPN TMCMA0J107MTRF
D1: PTVS5V0Z1USKPYL; SOD-964; MPN PTVS5V0Z1USKPYL
M1: SC606T; QUECTEL_SC606T; MPN SC606T-xx
R111, R170, R204, R205: R_0R_0402; 0402-res; MPN ERJ2GE0R00X
TP1, TP2, TP5, TP6, TP7, TP8, TP21, TP22, TP25, TP26, TP27, TP28, TP29, TP30, TP31, TP32, TP33, TP34, TP35, TP36, TP37, TP38, TP39, TP40, TP41, TP42, TP43, TP44, TP45, TP46, TP47, TP48, TP49, TP50, TP51, TP52, TP53, TP54: TP_SMD_1_5MM; TP-R-1.5

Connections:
ANT-WIFI: M1.129 (ANT_WIFI/BT); also elsewhere on the board
ANT_GNSS: M1.134 (ANT_GNSS); also elsewhere on the board
ANT_MAIN: M1.19 (ANT_MAIN); also elsewhere on the board
CAM1_CLK_N: M1.89 (CSI0_CLK_N); also elsewhere on the board
CAM1_CLK_P: M1.88 (CSI0_CLK_P); also elsewhere on the board
CAM1_D0_N: M1.91 (CSI0_LN0_N); also elsewhere on the board
CAM1_D0_P: M1.90 (CSI0_LN0_P); also elsewhere on the board
CAM1_D1_N: M1.93 (CSI0_LN1_N); also elsewhere on the board
CAM1_D1_P: M1.92 (CSI0_LN1_P); also elsewhere on the board
CAM1_D2_N: M1.95 (CSI0_LN2_N); also elsewhere on the board
CAM1_D2_P: M1.94 (CSI0_LN2_P); also elsewhere on the board
CAM1_D3_N: M1.97 (CSI0_LN3_N); also elsewhere on the board
CAM1_D3_P: M1.96 (CSI0_LN3_P); also elsewhere on the board
CAM2_CLK_N: M1.184 (CSI1_CLK_N); also elsewhere on the board
CAM2_CLK_P: M1.183 (CSI1_CLK_P); also elsewhere on the board
CAM2_D0_N: M1.186 (CSI1_LN0_N); also elsewhere on the board
CAM2_D0_P: M1.185 (CSI1_LN0_P); also elsewhere on the board
CAM2_D1_N: M1.188 (CSI1_LN1_N); also elsewhere on the board
CAM2_D1_P: M1.187 (CSI1_LN1_P); also elsewhere on the board
CAM2_D2_N: M1.190 (CSI1_LN2_N); also elsewhere on the board
CAM2_D2_P: M1.189 (CSI1_LN2_P); also elsewhere on the board
CAM2_D3_N: M1.192 (CSI1_LN3_N); also elsewhere on the board
CAM2_D3_P: M1.191 (CSI1_LN3_P); also elsewhere on the board
CAM_I2C_SCL: M1.75 (CAM_I2C_SCL); also elsewhere on the board
CAM_I2C_SDA: M1.76 (CAM_I2C_SDA); also elsewhere on the board
CAM_RST: M1.231 (GPIO_90); also elsewhere on the board
DEBUG_UART_RX: M1.6 (UART2_RXD); also elsewhere on the board
DEBUG_UART_TX: M1.5 (UART2_TXD); also elsewhere on the board
GND: C1.2, C2.2, C3.2, C4.2, C5.2, C6.2, C7.2, C8.2, C9.1, C10.2, C11.2, C12.1, C13.2, C14.2, C15.2, C16.2, C138.1, C171.2, C172.2, D1.A, M1.3 (GND), M1.4 (GND), M1.18 (GND), M1.20 (GND), M1.31 (GND), M1.34 (GND), M1.35 (GND), M1.40 (GND), M1.43 (GND), M1.47 (GND), M1.56 (GND), M1.62 (GND), M1.87 (GND), M1.98 (GND), M1.101 (GND), M1.112 (GND), M1.125 (GND), M1.128 (GND), M1.130 (GND), M1.133 (GND), M1.135 (GND), M1.148 (GND), M1.150 (GND), M1.159 (GND), M1.160 (GND), M1.163 (GND), M1.170 (GND), M1.173 (GND), M1.176 (GND), M1.182 (GND), M1.193 (GND), M1.195 (GND), M1.219 (GND), M1.225 (GND), M1.243 (GND), M1.257 (GND), M1.258 (GND), M1.259 (GND), M1.260 (GND), M1.261 (GND), M1.262 (GND), M1.263 (GND), M1.264 (GND), M1.265 (GND), M1.266 (GND), M1.267 (GND), M1.268 (GND), M1.269 (GND), M1.270 (GND), M1.271 (GND), M1.272 (GND), M1.273 (GND), M1.274 (GND), M1.275 (GND), M1.276 (GND), M1.277 (GND), M1.278 (GND), M1.279 (GND), M1.280 (GND), M1.281 (GND), M1.282 (GND), M1.283 (GND), M1.284 (GND), M1.285 (GND), M1.286 (GND), M1.287 (GND), M1.288 (GND), M1.289 (GND), M1.290 (GND), M1.291 (GND), M1.292 (GND), M1.293 (GND), M1.294 (GND), M1.295 (GND), M1.296 (GND), M1.297 (GND), M1.298 (GND), M1.299 (GND), M1.300 (GND), M1.301 (GND), M1.302 (GND), M1.303 (GND), M1.304 (GND), M1.305 (GND), M1.306 (GND), M1.307 (GND), M1.308 (GND), M1.309 (GND), M1.310 (GND), M1.311 (GND), M1.312 (GND), M1.313 (GND), M1.314 (GND), M1.315 (GND), M1.316 (GND), M1.317 (GND), M1.318 (GND), M1.319 (GND), M1.320 (GND), M1.321 (GND), M1.322 (GND), M1.323 (GND), R170.2; also elsewhere on the board
GPIO_1: M1.247 (GPIO_1), R111.1, TP7.1; also elsewhere on the board
HDMI_I2C_SCL: M1.205 (TP1_I2C_SCL); also elsewhere on the board
HDMI_I2C_SDA: M1.204 (TP1_I2C_SDA); also elsewhere on the board
LDO5_1P8: C9.2, M1.9 (LDO5_1P8), TP52.1; also elsewhere on the board
LDO6_1P8: C1.1, C2.1, M1.10 (LDO6_1P8); also elsewhere on the board
LDO10_2P8: C12.2, M1.11 (LDO10_2P8), TP53.1
LDO17_2P85: C138.2, M1.12 (LDO17_2P85), TP54.1; also elsewhere on the board
LT9611_INT0: M1.229 (GPIO_97); also elsewhere on the board
LT9611_RST_N: M1.230 (GPIO_96); also elsewhere on the board
unnamed: C4.1, C6.1, C8.1, M1.1 (VDD_RF), M1.2 (VDD_RF)
unnamed: M1.30 (USB_ID), R111.2
unnamed: M1.44 (MIC1_P), TP21.1
unnamed: M1.45 (MIC1_N), TP22.1
unnamed: M1.46 (MIC2_P), TP25.1
unnamed: M1.48 (HS_DET), TP26.1
unnamed: M1.49 (HPH_L), TP27.1
unnamed: M1.50 (HPH_REF), TP28.1
unnamed: M1.51 (HPH_R), TP29.1
unnamed: M1.52 (EAR_N), TP30.1
unnamed: M1.53 (EAR_P), TP31.1
unnamed: M1.54 (SPK_N), TP32.1
unnamed: M1.55 (SPK_P), TP33.1
unnamed: M1.58 (SPI_CS), TP38.1
unnamed: M1.59 (SPI_CLK), TP37.1
unnamed: M1.60 (SPI_MOSI), TP39.1
unnamed: M1.61 (SPI_MISO), TP40.1
unnamed: M1.73 (MCAM_PWDN), TP34.1
unnamed: M1.74 (MCAM_RST), TP35.1
unnamed: M1.126 (LCD0_TE), TP41.1
unnamed: M1.127 (LCD0_RST), TP42.1
unnamed: M1.138 (TP0_RST), TP43.1
unnamed: M1.139 (TP0_INT), TP44.1
unnamed: M1.145 (USIM1_DET), TP2.1
unnamed: M1.149 (ANT_DRX), TP45.1
unnamed: M1.168 (MIC_GND), R170.1
unnamed: M1.200 (GPIO_3), TP5.1
unnamed: M1.201 (GPIO_2), TP6.1
unnamed: M1.202 (GNSS_LNA_EN), TP36.1
unnamed: M1.223 (USBC_CC2), R204.1, TP46.1
unnamed: M1.224 (USBC_CC1), R205.1, TP47.1
unnamed: M1.226 (USB_SS_SEL), TP48.1
unnamed: M1.227 (LINE_OUT_P), TP49.1
unnamed: M1.228 (LINE_OUT_N), TP50.1
unnamed: M1.244 (FM_ANT), TP51.1
unnamed: M1.248 (GPIO_0), TP8.1
PWRKEY: M1.39 (PWRKEY); also elsewhere on the board
RS485_CTS: M1.246 (UART5_CTS); also elsewhere on the board
RS485_DIR_GPIO: M1.252 (GPIO_42); also elsewhere on the board
RS485_RTS: M1.245 (UART5_RTS); also elsewhere on the board
RTC_BAT: M1.16 (VRTC), TP1.1; also elsewhere on the board
SD_DATA_0: M1.68 (SD_DATA0); also elsewhere on the board
SD_DATA_1: M1.67 (SD_DATA1); also elsewhere on the board
SD_DATA_2: M1.66 (SD_DATA2); also elsewhere on the board
SD_DATA_3: M1.65 (SD_DATA3); also elsewhere on the board
SD_DATA_4: M1.70 (SD_CLK); also elsewhere on the board
SD_DATA_5: M1.69 (SD_CMD); also elsewhere on the board
SD_DATA_6: M1.64 (SD_DET); also elsewhere on the board
STUSB4500_SCL: M1.131 (SENSOR_I2C_SCL); also elsewhere on the board
STUSB4500_SDA: M1.132 (SENSOR_I2C_SDA); also elsewhere on the board
SoM_RX__RS485_TX: M1.198 (UART5_RXD); also elsewhere on the board
SoM_TX__RS485_RX: M1.199 (UART5_TXD); also elsewhere on the board
SoM_USB3_RX_N: M1.172 (USB_SS_RX_M); also elsewhere on the board
SoM_USB3_RX_P: M1.171 (USB_SS_RX_P); also elsewhere on the board
SoM_USB3_TX_N: M1.175 (USB_SS_TX_M); also elsewhere on the board
SoM_USB3_TX_P: M1.174 (USB_SS_TX_P); also elsewhere on the board
SoM_USB_D_N: M1.33 (USB_DM); also elsewhere on the board
SoM_USB_D_P: M1.32 (USB_DP); also elsewhere on the board
SoMtoDisplay_CLK_N: M1.103 (DSI1_CLK_N); also elsewhere on the board
SoMtoDisplay_CLK_P: M1.102 (DSI1_CLK_P); also elsewhere on the board
SoMtoDisplay_D0_N: M1.105 (DSI1_LN0_N); also elsewhere on the board
SoMtoDisplay_D0_P: M1.104 (DSI1_LN0_P); also elsewhere on the board
SoMtoDisplay_D1_N: M1.107 (DSI1_LN1_N); also elsewhere on the board
SoMtoDisplay_D1_P: M1.106 (DSI1_LN1_P); also elsewhere on the board
SoMtoDisplay_D2_N: M1.109 (DSI1_LN2_N); also elsewhere on the board
SoMtoDisplay_D2_P: M1.108 (DSI1_LN2_P); also elsewhere on the board
SoMtoDisplay_D3_N: M1.111 (DSI1_LN3_N); also elsewhere on the board
SoMtoDisplay_D3_P: M1.110 (DSI1_LN3_P); also elsewhere on the board
SoMtoLT_CLK_N: M1.116 (DSI0_CLK_N); also elsewhere on the board
SoMtoLT_CLK_P: M1.115 (DSI0_CLK_P); also elsewhere on the board
SoMtoLT_D0_N: M1.118 (DSI0_LN0_N); also elsewhere on the board
SoMtoLT_D0_P: M1.117 (DSI0_LN0_P); also elsewhere on the board
SoMtoLT_D1_N: M1.120 (DSI0_LN1_N); also elsewhere on the board
SoMtoLT_D1_P: M1.119 (DSI0_LN1_P); also elsewhere on the board
SoMtoLT_D2_N: M1.122 (DSI0_LN2_N); also elsewhere on the board
SoMtoLT_D2_P: M1.121 (DSI0_LN2_P); also elsewhere on the board
SoMtoLT_D3_N: M1.124 (DSI0_LN3_N); also elsewhere on the board
SoMtoLT_D3_P: M1.123 (DSI0_LN3_P); also elsewhere on the board
TP0_I2C_SCL: M1.140 (TP0_I2C_SCL); also elsewhere on the board
TP0_I2C_SDA: M1.206 (TP0_I2C_SDA); also elsewhere on the board
UART_Connector_RX: M1.8 (UART4_RXD); also elsewhere on the board
UART_Connector_TX: M1.7 (UART4_TXD); also elsewhere on the board
USB_BOOT: M1.57 (USB_BOOT); also elsewhere on the board
USB_FLASH_CC1: R205.2; also elsewhere on the board
USB_FLASH_CC2: R204.2; also elsewhere on the board
USB_VBUS_DET: M1.41 (USB_VBUS), M1.42 (USB_VBUS); also elsewhere on the board
USIM1_CLK: M1.143 (USIM1_CLK); also elsewhere on the board
USIM1_DATA: M1.142 (USIM1_DATA); also elsewhere on the board
USIM1_RST: M1.144 (USIM1_RST); also elsewhere on the board
USIM1_VDD: M1.141 (USIM1_VDD); also elsewhere on the board
USR_LED1: M1.232 (GPIO_89); also elsewhere on the board
USR_LED2: M1.234 (GPIO_66); also elsewhere on the board
VOL_DOWN: M1.147 (VOL_DOWN); also elsewhere on the board
VOL_UP: M1.146 (VOL_UP); also elsewhere on the board
VPH_PWR: C11.1, C14.1, C16.1, M1.220 (VPH_PWR), M1.221 (VPH_PWR)
VSYNC_CAM1: M1.178 (GPIO_99); also elsewhere on the board
VSYNC_CAM2: M1.177 (GPIO_98); also elsewhere on the board
V_SOM: C3.1, C5.1, C7.1, C10.1, C13.1, C15.1, C171.1, C172.1, D1.K, M1.36 (VBAT), M1.37 (VBAT), M1.38 (VBAT); also elsewhere on the board

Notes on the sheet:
Power
CSI, DSI
MISC
I2C, USB SS, UART
GPIO

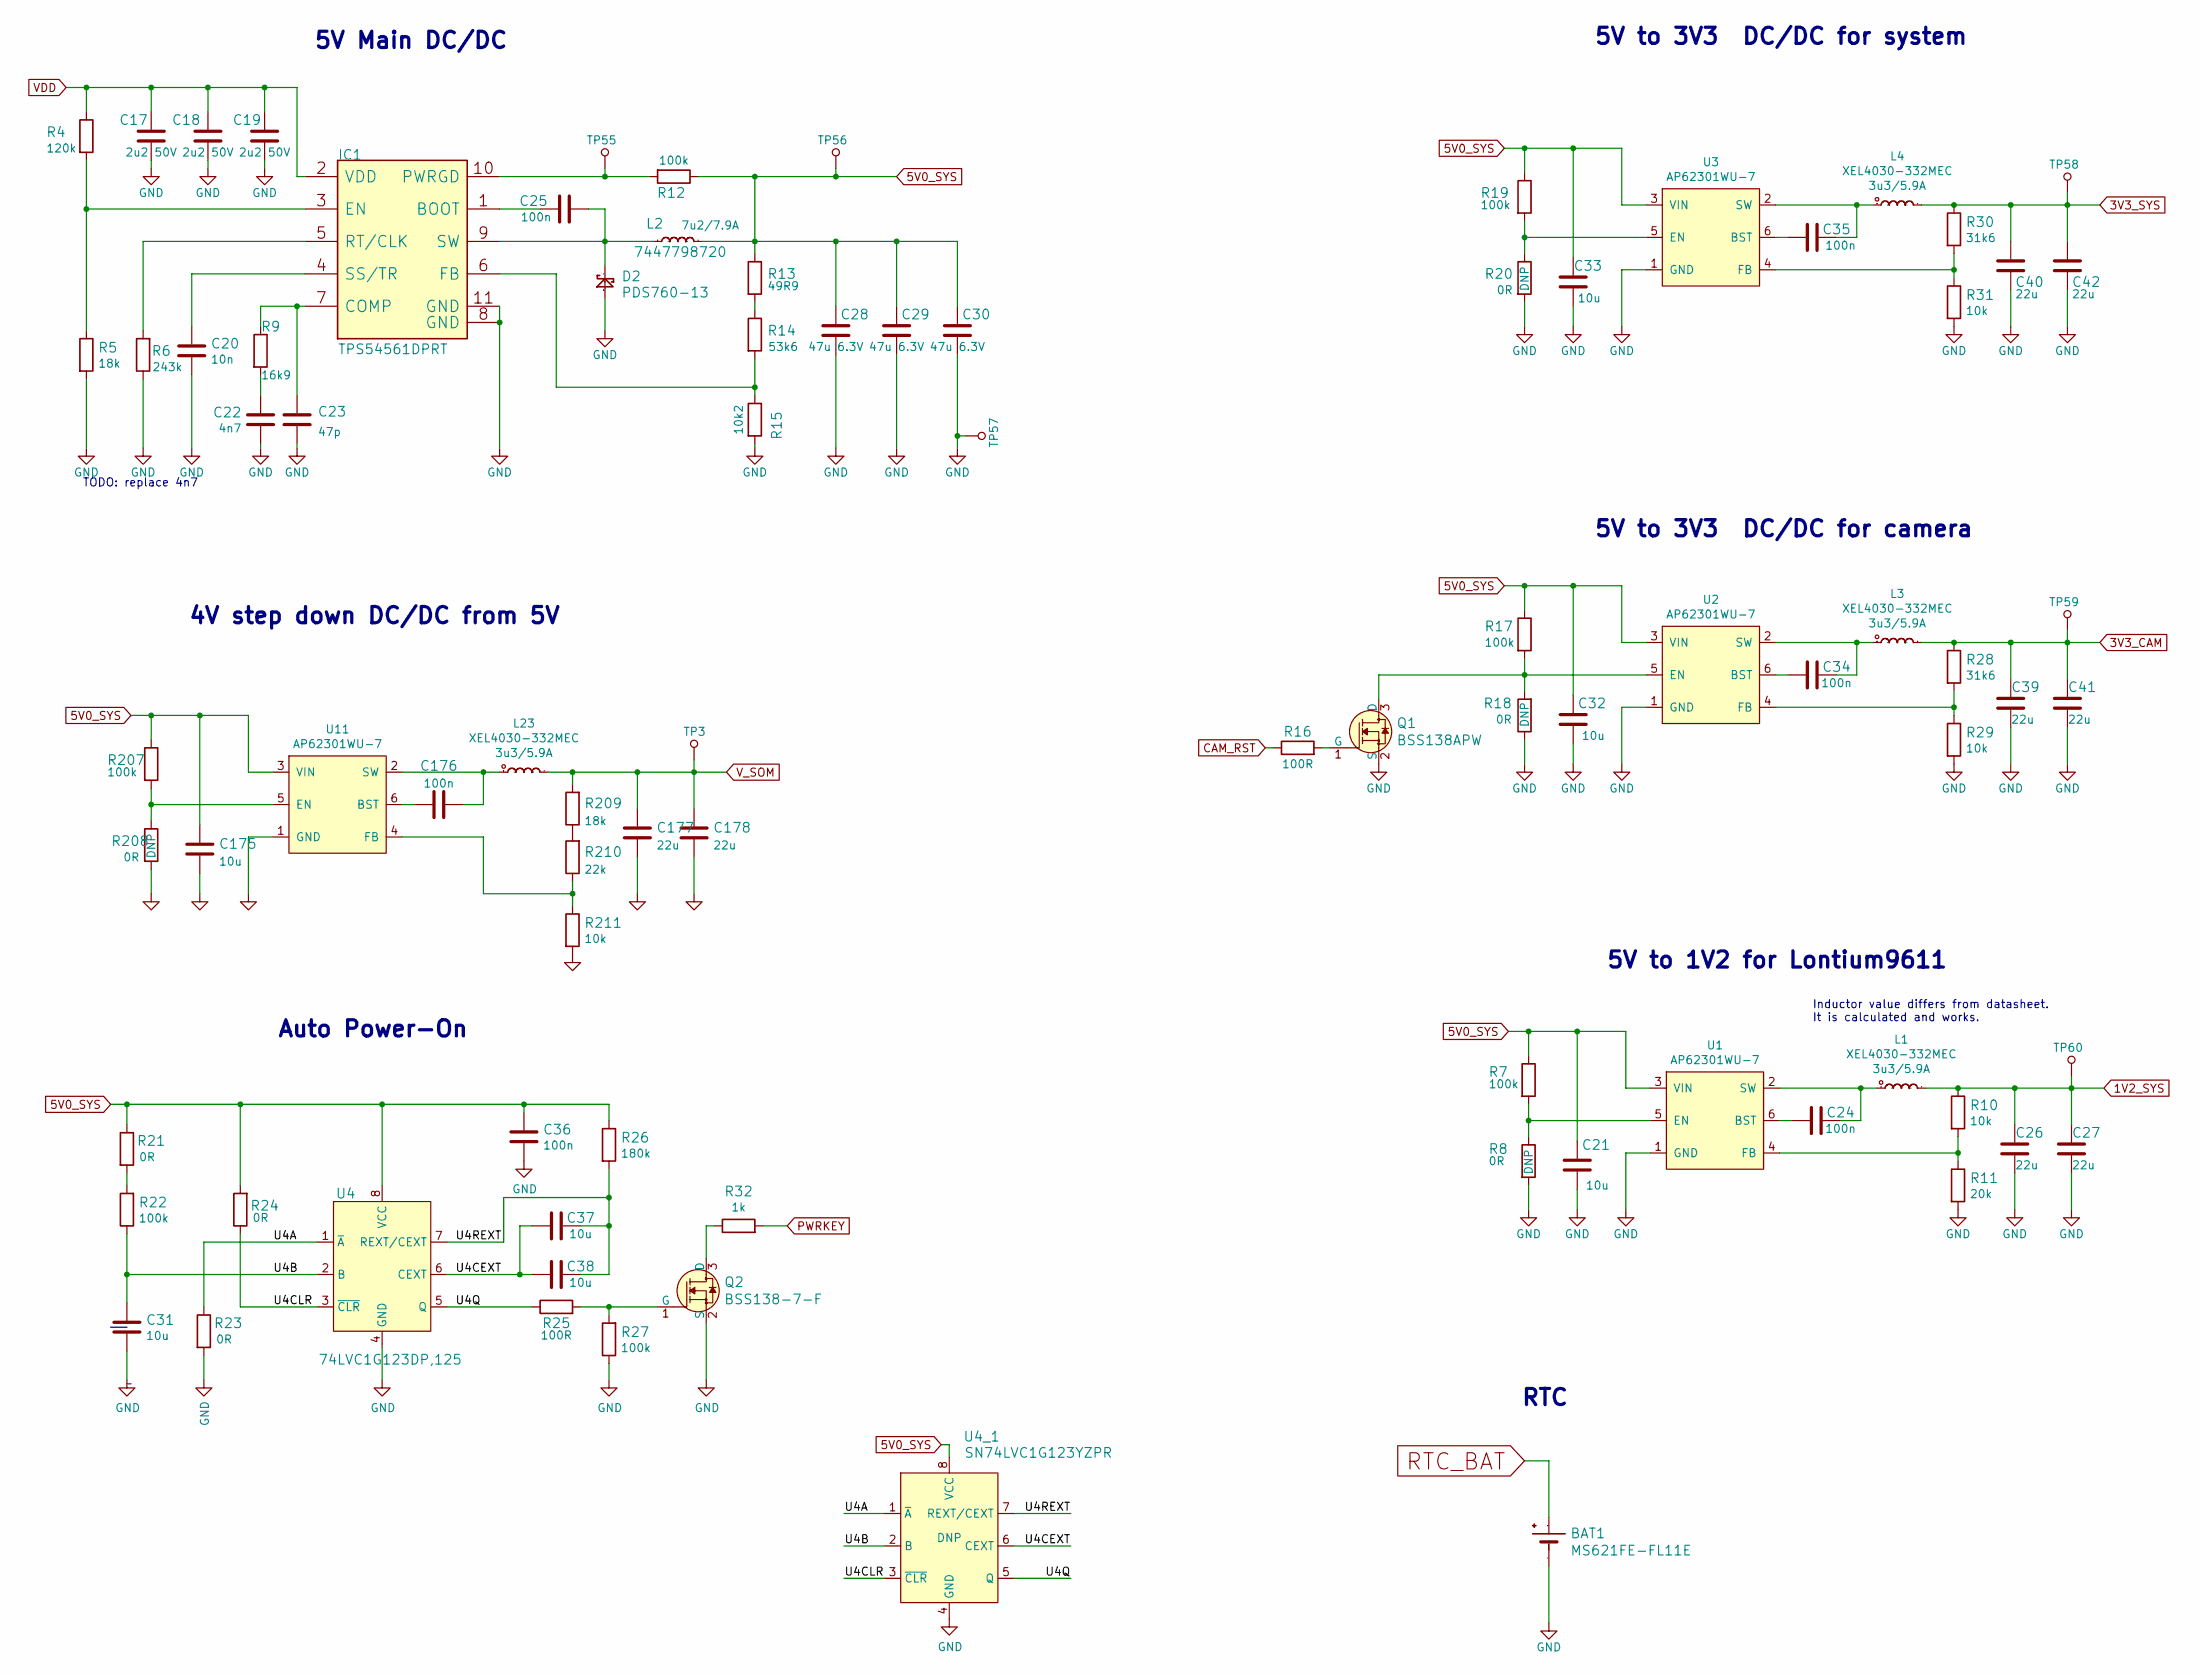
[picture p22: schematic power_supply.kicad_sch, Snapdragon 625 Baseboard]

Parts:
BAT1: MS621FE-FL11E; MPN MS621FE-FL11E
C17, C18, C19: C_2u2_0805_50V; 0805-cap; MPN C2012X5R1H225K125AB
C20: C_10n_0402; 0402-cap; MPN 04025G103ZAT2A
C21, C31, C32, C33, C37, C38, C175: C_10u_0402; 0402-cap; MPN CC0402MRX5R5BB106
C22: C_4n7_0402; 0402-cap; MPN CGA2B3X7S2A472K050BB
C23: C_47p_0402; 0402-cap; MPN C0402C470J5GACTU
C24, C34, C35, C36, C176: C_100n_0402; 0402-cap; MPN GRM155R61H104KE14D
C25: C_100n_0402; 0402-cap; MPN 0402X104K6R3CT
C26, C27, C39, C40, C41, C42: C_22u_0603; 0603-cap; MPN GRM188R60J226MEA0D
C28, C29, C30: C_47u_0603; 0603-cap; MPN GRM188R60J476ME15D
C177, C178: C_22u_0402; 0402-cap; MPN 04024W226MAT2A
D2: PDS760-13; MPN PDS760-13
IC1: TPS54561DPRT; WSON-10_4x4; MPN TPS54561DPRT
L1, L3, L4, L23: XEL4030-332MEC; Coilcraft-XEL4030; MPN XEL4030-332MEC
L2: 7447798720; WE_7447798720; MPN 7447798720
Q1: BSS138APW; SC70-3; MPN BSS138PW
Q2: BSS138-7-F; SOT-23-3; MPN BSS138-7-F
R4: R_120k_0402; 0402-res; MPN CRCW0402120KFKED
R5, R209: R_18k_0402; 0402-res; MPN MCWR04X1802FTL
R6: R_243k_0402; 0402-res; MPN MCMR04X2433FTL
R7, R12, R17, R19, R22, R27: R_100k_0402; 0402-res; MPN CRCW0402100KFKEDHP
R8, R18, R20, R21, R23, R24: R_0R_0402; 0402-res; MPN ERJ2GE0R00X
R9: R_16k9_0402; 0402-res; MPN ERA2AEB1692X
R10, R29, R31, R211: R_10k_0402; 0402-res; MPN CRCW040210K0FKEDHP
R11: R_20k_0402; 0402-res; MPN CRCW040220K0FKED
R13: R_49R9_0603; 0603-res; MPN CRCW060349R9FKEA
R14: R_53k6_0402; 0402-res; MPN CPF0402B53K6E1
R15: R_10k2_0402; 0402-res; MPN MCWR04X1022FTL
R16, R25: R_100R_0402; 0402-res; MPN CR0402-FX-1000GLF
R26: R_180k_0402; 0402-res; MPN CRCW0402180KJNED
R28, R30: R_31k6_0402; 0402-res; MPN CRCW040231K6FKEDC
R32: R_1k_0402; 0402-res; MPN CR0402-FX-1001GLF
R207: 0402-res; MPN CRCW0402100KFKEDHP
R208: 0402-res; MPN ERJ2GE0R00X
R210: R_22k_0402; 0402-res; MPN ERJ-2RKF2202X
TP3, TP55, TP56, TP57, TP58, TP59, TP60: TP_SMD_1_5MM; TP-R-1.5
U1, U2, U3, U11: AP62301WU-7; TSOT23-6; MPN AP62301WU-7
U4: 74LVC1G123DP,125; TSSOP-8_W3mm; MPN 74LVC1G123DP,125
U4_1: SN74LVC1G123YZPR; DSBGA-8_1.91x0.91mm; MPN SN74LVC1G123YZPR

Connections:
1V2_SYS: C26.1, C27.1, L1.2, R10.1, TP60.1; also elsewhere on the board
3V3_CAM: C39.1, C41.1, L3.2, R28.1, TP59.1; also elsewhere on the board
3V3_SYS: C40.1, C42.1, L4.2, R30.1, TP58.1; also elsewhere on the board
5V0_SYS: C21.1, C28.1, C29.1, C30.1, C32.1, C33.1, C36.2, C175.1, L2.2, R7.1, R12.1, R13.1, R17.1, R19.1, R21.1, R24.2, R26.1, R207.1, TP56.1, U1.3 (VIN), U2.3 (VIN), U3.3 (VIN), U4.8 (VCC), U4_1.8 (VCC), U11.3 (VIN); also elsewhere on the board
/power supply/U4A: R23.1, U4.1 (~A), U4_1.1 (~A)
/power supply/U4B: C31.1, R22.1, U4.2 (B), U4_1.2 (B)
/power supply/U4CEXT: C37.1, C38.1, U4.6 (CEXT), U4_1.6 (CEXT)
/power supply/U4CLR: R24.1, U4.3 (~CLR), U4_1.3 (~CLR)
/power supply/U4Q: R25.1, U4.5 (Q), U4_1.5 (Q)
/power supply/U4REXT: C37.2, C38.2, R26.2, U4.7 (REXT/CEXT), U4_1.7 (REXT/CEXT)
CAM_RST: R16.1; also elsewhere on the board
GND: BAT1.-, C17.2, C18.2, C19.2, C20.2, C21.2, C22.2, C23.2, C26.2, C27.2, C28.2, C29.2, C30.2, C31.2, C32.2, C33.2, C36.1, C39.2, C40.2, C41.2, C42.2, D2.A, IC1.8 (GND), IC1.11 (GND), Q1.2 (S), Q2.2 (S), R5.2, R6.1, R8.2, R11.2, R15.2, R18.1, R20.2, R23.2, R27.1, R29.2, R31.2, TP57.1, U1.1 (GND), U2.1 (GND), U3.1 (GND), U4.4 (GND), U4_1.4 (GND); also elsewhere on the board
unnamed: C20.1, IC1.4 (SS/TR)
unnamed: C22.1, R9.2
unnamed: C23.1, IC1.7 (COMP), R9.1
unnamed: C24.1, L1.1, U1.2 (SW)
unnamed: C24.2, U1.6 (BST)
unnamed: C25.1, IC1.1 (BOOT)
unnamed: C25.2, D2.C, IC1.9 (SW), L2.1
unnamed: C34.1, L3.1, U2.2 (SW)
unnamed: C34.2, U2.6 (BST)
unnamed: C35.1, L4.1, U3.2 (SW)
unnamed: C35.2, U3.6 (BST)
unnamed: C175.2, C177.2, C178.2, R208.2, R211.2, U11.1 (GND)
unnamed: C176.1, U11.6 (BST)
unnamed: C176.2, L23.1, U11.2 (SW)
unnamed: C177.1, C178.1, L23.2, R209.2, TP3.1
unnamed: IC1.3 (EN), R4.2, R5.1
unnamed: IC1.5 (RT/CLK), R6.2
unnamed: IC1.6 (FB), R14.2, R15.1
unnamed: IC1.10 (PWRGD), R12.2, TP55.1
unnamed: Q1.1 (G), R16.2
unnamed: Q1.3 (D), R17.2, R18.2, U2.5 (EN)
unnamed: Q2.1 (G), R25.2, R27.2
unnamed: Q2.3 (D), R32.1
unnamed: R7.2, R8.1, U1.5 (EN)
unnamed: R10.2, R11.1, U1.4 (FB)
unnamed: R13.2, R14.1
unnamed: R19.2, R20.1, U3.5 (EN)
unnamed: R21.2, R22.2
unnamed: R28.2, R29.1, U2.4 (FB)
unnamed: R30.2, R31.1, U3.4 (FB)
unnamed: R207.2, R208.1, U11.5 (EN)
unnamed: R209.1, R210.2
unnamed: R210.1, R211.1, U11.4 (FB)
PWRKEY: R32.2; also elsewhere on the board
RTC_BAT: BAT1.+; also elsewhere on the board
VDD: C17.1, C18.1, C19.1, IC1.2 (VDD), R4.1; also elsewhere on the board

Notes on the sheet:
5V to 3V3 DC/DC for camera
4V step down DC/DC from 5V
TODO: replace 4n7
5V Main DC/DC
Auto Power-On
RTC
5V to 1V2 for Lontium9611
Inductor value differs from datasheet. It is calculated and works.
5V to 3V3 DC/DC for system

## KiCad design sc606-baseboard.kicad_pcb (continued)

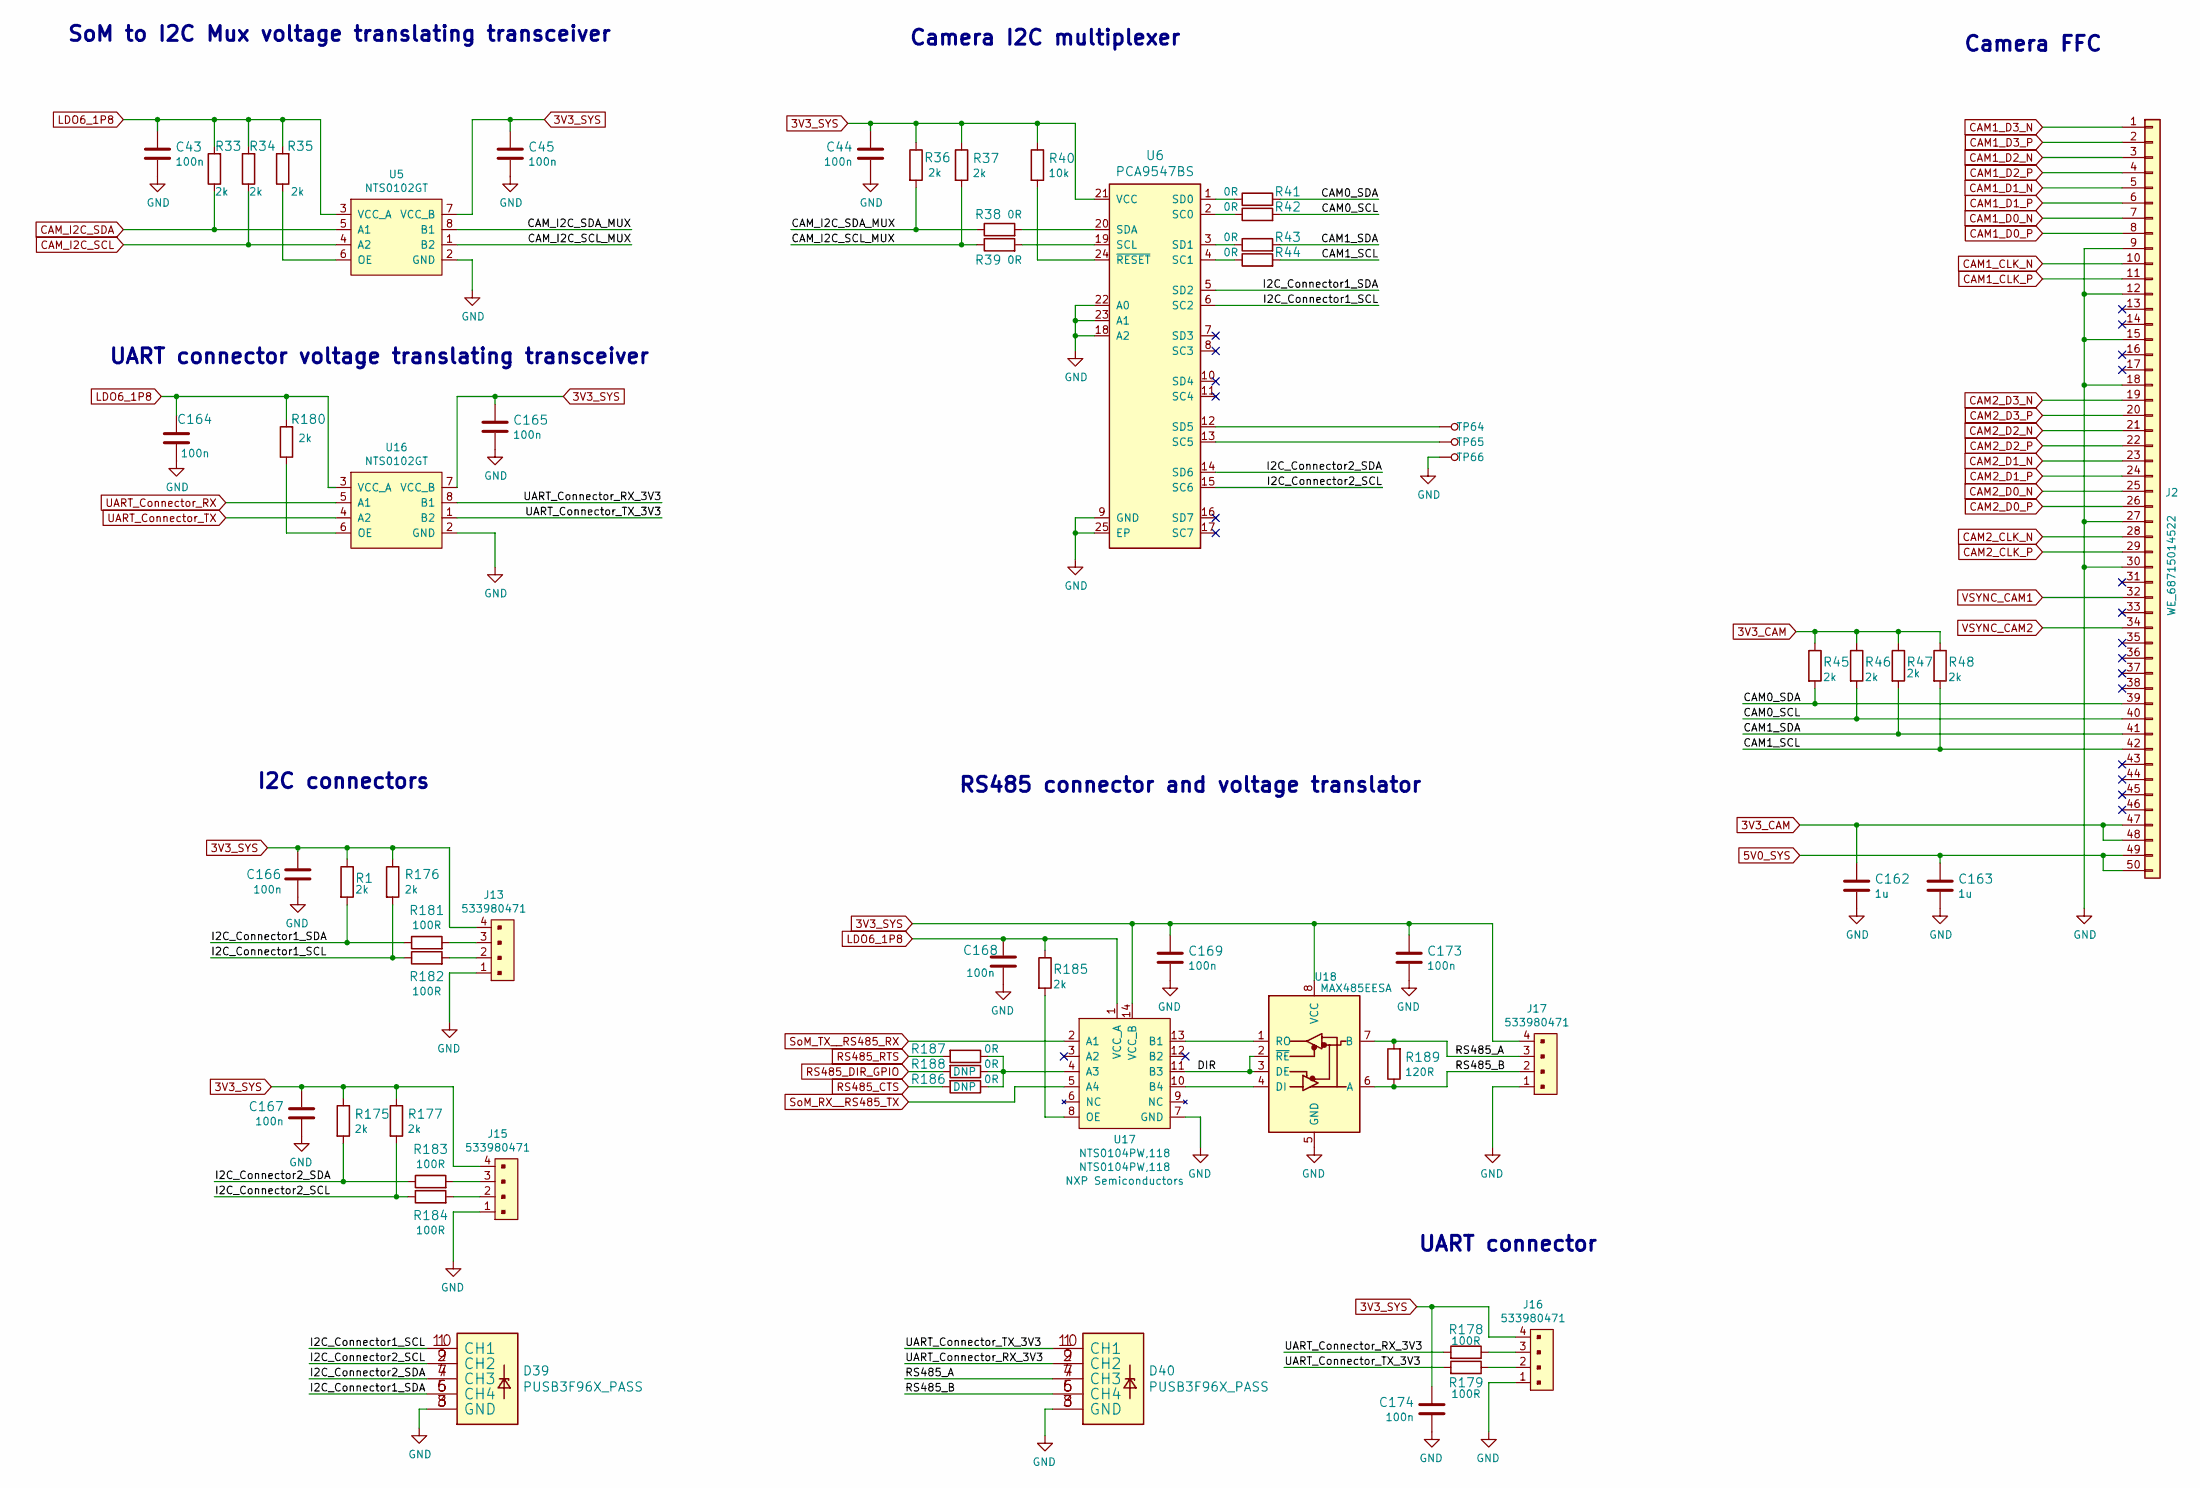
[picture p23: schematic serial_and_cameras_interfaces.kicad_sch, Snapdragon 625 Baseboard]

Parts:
C43, C45, C164, C165, C166, C167, C168, C169, C173, C174: C_100n_0402; 0402-cap; MPN GRM155R61H104KE14D
C44: C_100n_0402; 0402-cap; MPN 0402X104K6R3CT
C162, C163: C_1u_0402; 0402-cap; MPN C1005X6S1A105K050BC
D39, D40: PUSB3F96X_PASS; PUSB3F96X; MPN PUSB3F96X
J2: WE_68715014522; MPN 68715014522
J13, J15, J16, J17: 533980471; Molex_PicoBlade_53398-0471_1x04-1MP_P1.25mm_Vertical; MPN 0533980471
R1, R33, R34, R35, R36, R37, R45, R46, R47, R48, R175, R176, R177, R180, R185: R_2k_0402; 0402-res; MPN CRCW04022K00FKED
R38, R39, R41, R42, R43, R44, R186, R187, R188: R_0R_0402; 0402-res; MPN ERJ2GE0R00X
R40: R_10k_0402; 0402-res; MPN CRCW040210K0FKEDHP
R178, R179, R181, R182, R183, R184: R_100R_0402; 0402-res; MPN CR0402-FX-1000GLF
R189: R_120R_0603; 0603-res; MPN CRCW0603120RFKEA
TP64, TP65, TP66: TP_SMD_1_5MM; TP-R-1.5
U5, U16: NTS0102GT; PSON50P100X195X50-8N; MPN NTS0102GT
U6: PCA9547BS; HVQFN24; MPN PCA9547BS,118
U17: NTS0104PW,118; TSSOP-14_W4.4mm; MPN NTS0104PW,118
U18: MAX485EESA; SOIC-8_W3.9mm; MPN MAX485EESA

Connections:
3V3_CAM: C162.1, J2.47, J2.48, R45.1, R46.1, R47.1, R48.1; also elsewhere on the board
3V3_SYS: C44.1, C45.1, C165.1, C166.1, C167.1, C169.1, C173.1, C174.1, J13.4, J15.4, J16.4, J17.4, R1.1, R36.1, R37.1, R40.1, R175.1, R176.1, R177.1, U5.7 (VCC_B), U6.21 (VCC), U16.7 (VCC_B), U17.14 (VCC_B), U18.8 (VCC); also elsewhere on the board
5V0_SYS: C163.1, J2.49, J2.50; also elsewhere on the board
/serial_and_cameras_interfaces/CAM0_SCL: J2.40, R42.2, R46.2
/serial_and_cameras_interfaces/CAM0_SDA: J2.39, R41.2, R45.2
/serial_and_cameras_interfaces/CAM1_SCL: J2.42, R44.2, R48.2
/serial_and_cameras_interfaces/CAM1_SDA: J2.41, R43.2, R47.2
/serial_and_cameras_interfaces/CAM_I2C_SCL_MUX: R37.2, R39.1, U5.1 (B2)
/serial_and_cameras_interfaces/CAM_I2C_SDA_MUX: R36.2, R38.1, U5.8 (B1)
/serial_and_cameras_interfaces/DIR: U17.11 (B3), U18.2 (~RE), U18.3 (DE)
/serial_and_cameras_interfaces/I2C_Connector1_SCL: D39.1 (CH1), D39.10 (CH1), R176.2, R182.1, U6.6 (SC2)
/serial_and_cameras_interfaces/I2C_Connector1_SDA: D39.5 (CH4), D39.6 (CH4), R1.2, R181.1, U6.5 (SD2)
/serial_and_cameras_interfaces/I2C_Connector2_SCL: D39.2 (CH2), D39.9 (CH2), R177.2, R184.1, U6.15 (SC6)
/serial_and_cameras_interfaces/I2C_Connector2_SDA: D39.4 (CH3), D39.7 (CH3), R175.2, R183.1, U6.14 (SD6)
/serial_and_cameras_interfaces/RS485_A: D40.4 (CH3), D40.7 (CH3), J17.3, R189.2, U18.7 (B)
/serial_and_cameras_interfaces/RS485_B: D40.5 (CH4), D40.6 (CH4), J17.2, R189.1, U18.6 (A)
/serial_and_cameras_interfaces/UART_Connector_RX_3V3: D40.2 (CH2), D40.9 (CH2), R178.2, U16.8 (B1)
/serial_and_cameras_interfaces/UART_Connector_TX_3V3: D40.1 (CH1), D40.10 (CH1), R179.2, U16.1 (B2)
CAM1_CLK_N: J2.10; also elsewhere on the board
CAM1_CLK_P: J2.11; also elsewhere on the board
CAM1_D0_N: J2.7; also elsewhere on the board
CAM1_D0_P: J2.8; also elsewhere on the board
CAM1_D1_N: J2.5; also elsewhere on the board
CAM1_D1_P: J2.6; also elsewhere on the board
CAM1_D2_N: J2.3; also elsewhere on the board
CAM1_D2_P: J2.4; also elsewhere on the board
CAM1_D3_N: J2.1; also elsewhere on the board
CAM1_D3_P: J2.2; also elsewhere on the board
CAM2_CLK_N: J2.28; also elsewhere on the board
CAM2_CLK_P: J2.29; also elsewhere on the board
CAM2_D0_N: J2.25; also elsewhere on the board
CAM2_D0_P: J2.26; also elsewhere on the board
CAM2_D1_N: J2.23; also elsewhere on the board
CAM2_D1_P: J2.24; also elsewhere on the board
CAM2_D2_N: J2.21; also elsewhere on the board
CAM2_D2_P: J2.22; also elsewhere on the board
CAM2_D3_N: J2.19; also elsewhere on the board
CAM2_D3_P: J2.20; also elsewhere on the board
CAM_I2C_SCL: R34.1, U5.4 (A2); also elsewhere on the board
CAM_I2C_SDA: R33.1, U5.5 (A1); also elsewhere on the board
GND: C43.2, C44.2, C45.2, C162.2, C163.2, C164.2, C165.2, C166.2, C167.2, C168.2, C169.2, C173.2, C174.2, D39.3 (GND), D39.8 (GND), D40.3 (GND), D40.8 (GND), J2.9, J2.12, J2.15, J2.18, J2.27, J2.30, J13.1, J15.1, J16.1, J17.1, TP66.1, U5.2 (GND), U6.9 (GND), U6.18 (A2), U6.22 (A0), U6.23 (A1), U6.25 (EP), U16.2 (GND), U17.7 (GND), U18.5 (GND); also elsewhere on the board
LDO6_1P8: C43.1, C164.1, C168.1, R33.2, R34.2, R35.2, R180.2, R185.1, U5.3 (VCC_A), U16.3 (VCC_A), U17.1 (VCC_A); also elsewhere on the board
unnamed: J13.2, R182.2
unnamed: J13.3, R181.2
unnamed: J15.2, R184.2
unnamed: J15.3, R183.2
unnamed: J16.2, R179.1
unnamed: J16.3, R178.1
unnamed: R35.1, U5.6 (OE)
unnamed: R38.2, U6.20 (SDA)
unnamed: R39.2, U6.19 (SCL)
unnamed: R40.2, U6.24 (~RESET)
unnamed: R41.1, U6.1 (SD0)
unnamed: R42.1, U6.2 (SC0)
unnamed: R43.1, U6.3 (SD1)
unnamed: R44.1, U6.4 (SC1)
unnamed: R180.1, U16.6 (OE)
unnamed: R185.2, U17.8 (OE)
unnamed: R186.1, R187.1, R188.1, U17.4 (A3)
unnamed: TP64.1, U6.12 (SD5)
unnamed: TP65.1, U6.13 (SC5)
unnamed: U17.10 (B4), U18.4 (DI)
unnamed: U17.13 (B1), U18.1 (RO)
RS485_CTS: R186.2; also elsewhere on the board
RS485_DIR_GPIO: R188.2; also elsewhere on the board
RS485_RTS: R187.2; also elsewhere on the board
SoM_RX__RS485_TX: U17.5 (A4); also elsewhere on the board
SoM_TX__RS485_RX: U17.2 (A1); also elsewhere on the board
UART_Connector_RX: U16.5 (A1); also elsewhere on the board
UART_Connector_TX: U16.4 (A2); also elsewhere on the board
VSYNC_CAM1: J2.32; also elsewhere on the board
VSYNC_CAM2: J2.34; also elsewhere on the board

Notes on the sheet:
UART connector
UART connector voltage translating transceiver
RS485 connector and voltage translator
SoM to I2C Mux voltage translating transceiver
Camera I2C multiplexer
Camera FFC
I2C connectors

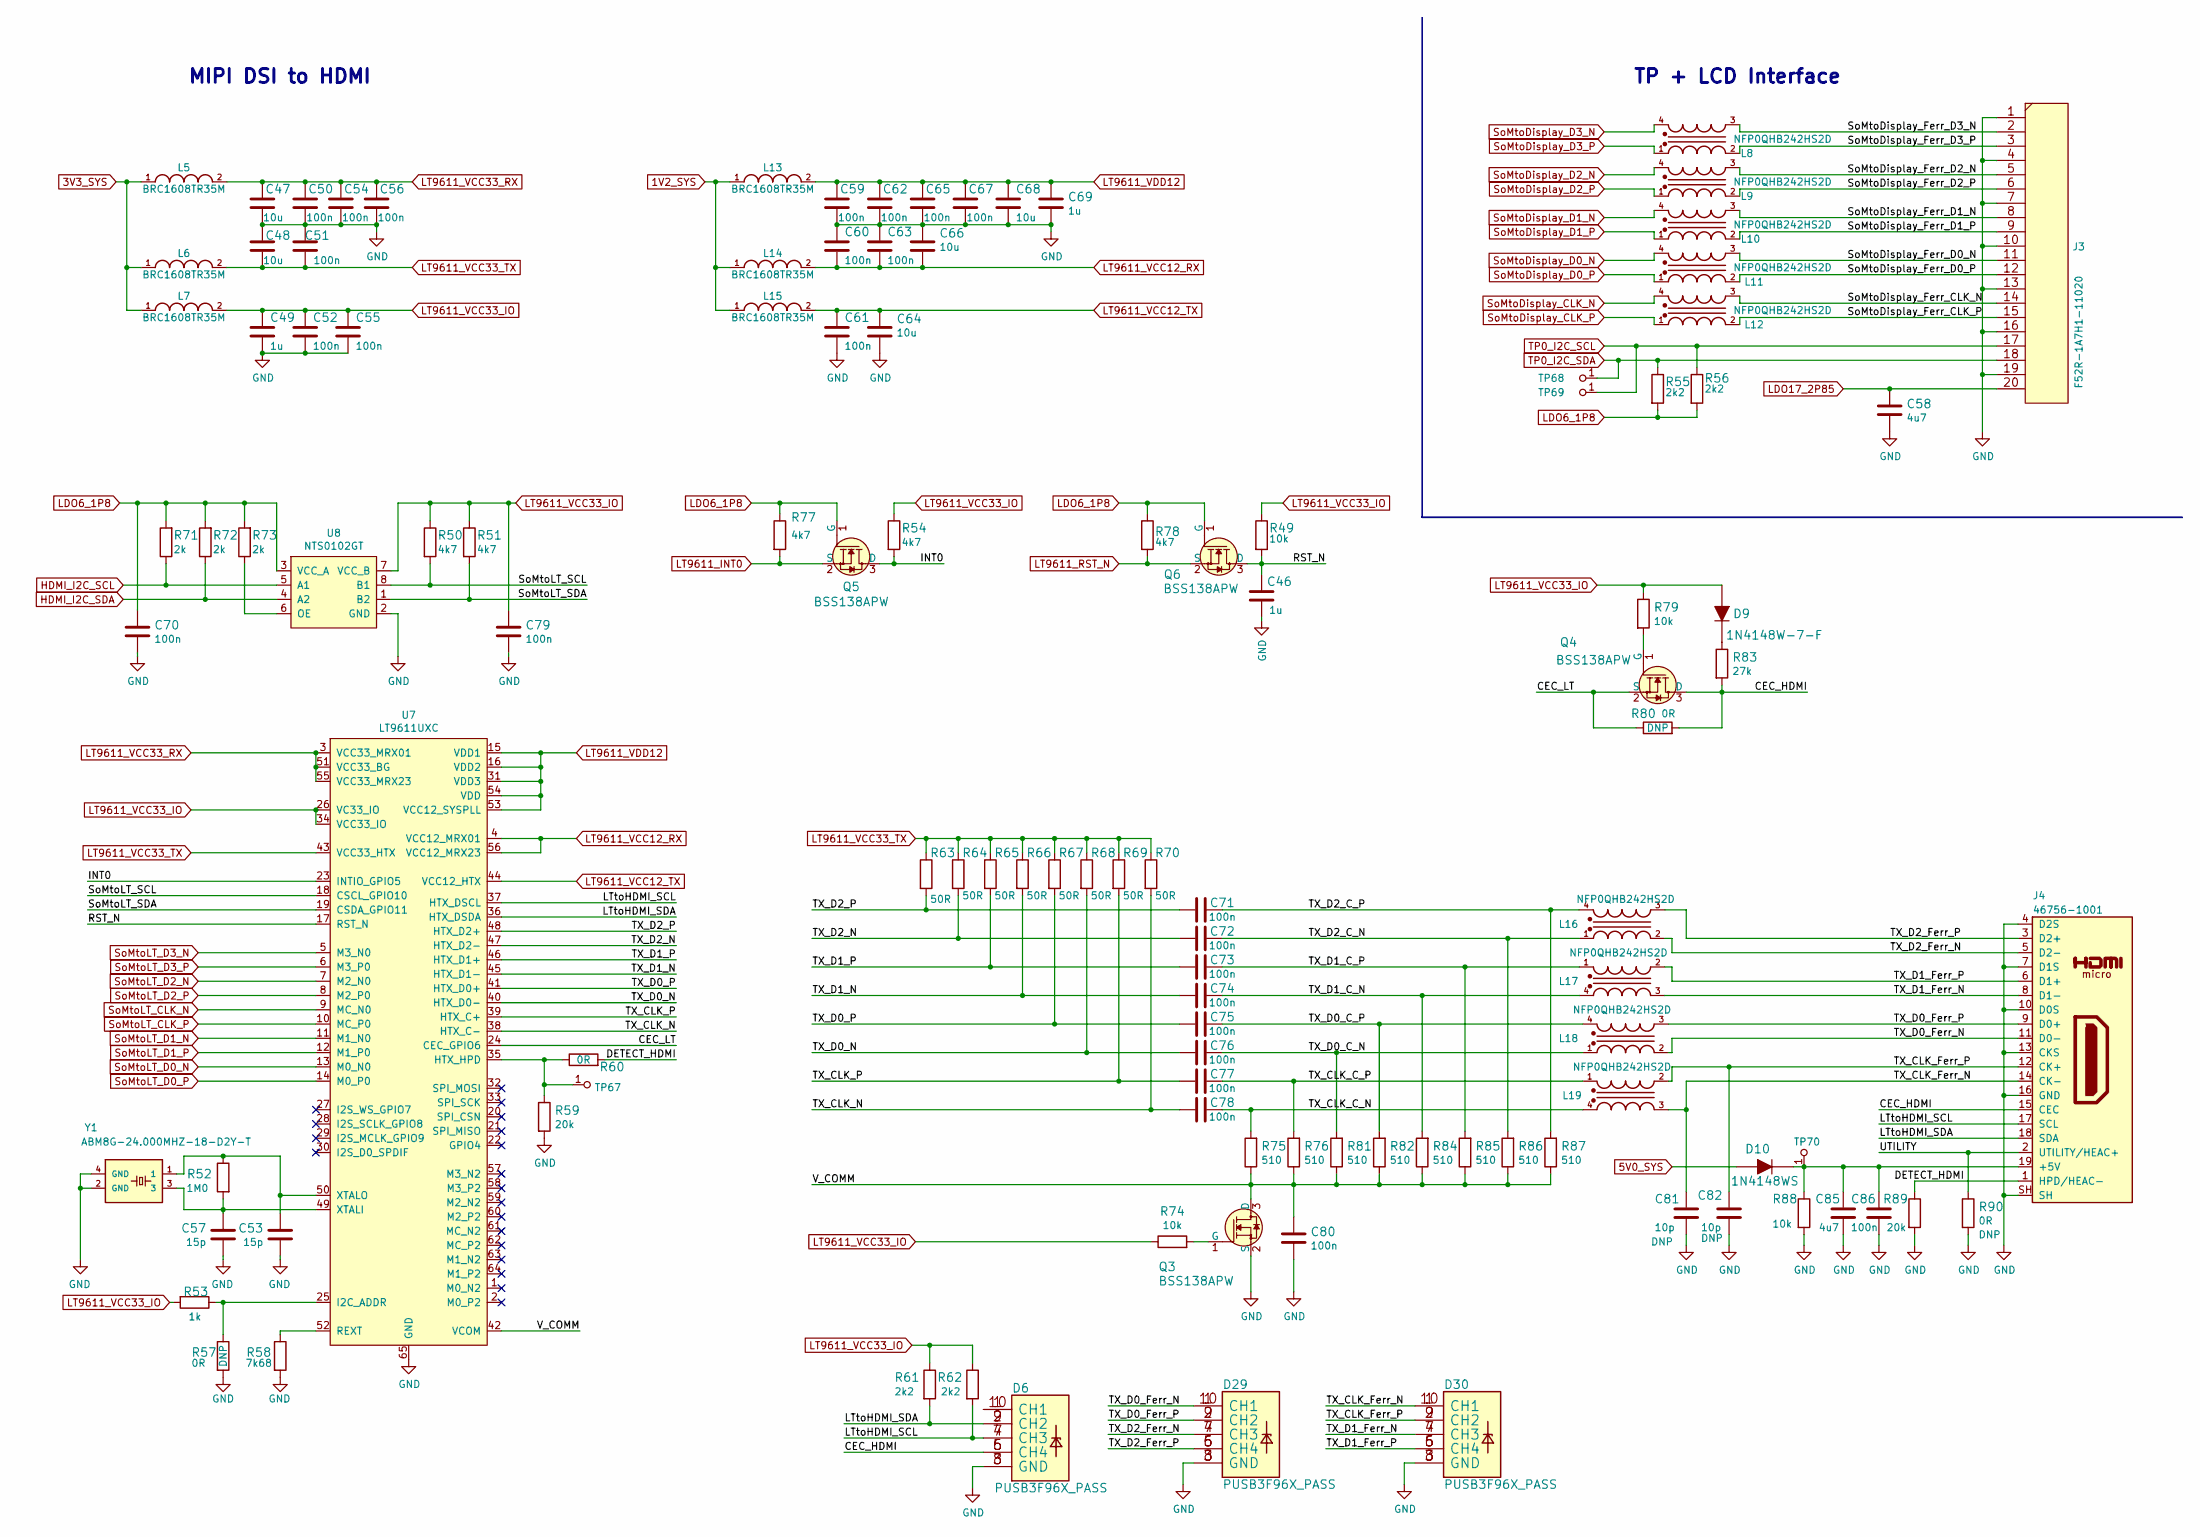
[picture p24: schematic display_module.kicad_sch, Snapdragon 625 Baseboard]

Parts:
C46, C49, C69: C_1u_0402; 0402-cap; MPN C1005X6S1A105K050BC
C47, C48, C64, C66, C68: C_10u_0402; 0402-cap; MPN CC0402MRX5R5BB106
C50, C51, C52, C54, C55, C56, C59, C60, C61, C62, C63, C65, C67, C70, C71, C72, C73, C74, C75, C76, C77, C78, C79, C80, C86: C_100n_0402; 0402-cap; MPN GRM155R61H104KE14D
C53, C57: C_15p_0402; 0402-cap; MPN MC0402N150J500CT
C58, C85: C_4u7_0402; 0402-cap; MPN GRM155R61A475MEAAD
C81, C82: C_10p_0402; 0402-cap; MPN MC0402N100D500CT
D6, D29, D30: PUSB3F96X_PASS; PUSB3F96X; MPN PUSB3F96X
D9: 1N4148W-7-F; SOD-123; MPN 1N4148W-7-F
D10: 1N4148WS; SOD-323F; MPN 1N4148WS
J3: F52R-1A7H1-11020; MPN F52R-1A7H1-11020
J4: 46756-1001; HDMI_Micro-D_Molex_46765-1x01; MPN 467651001
L5, L6, L7, L13, L14, L15: BRC1608TR35M; INDC1608X100N; MPN BRC1608TR35M
L8, L9, L10, L11, L12, L16, L17, L18, L19: NFP0QHB242HS2D; FIL_NFP0QHB242HS2D; MPN NFP0QHB242HS2D
Q3, Q4, Q5, Q6: BSS138APW; SC70-3; MPN BSS138PW
R49, R74, R79, R88: R_10k_0402; 0402-res; MPN CRCW040210K0FKEDHP
R50, R51, R54, R77, R78: R_4k7_0402; 0402-res; MPN MCS04020C4701FE000
R52: R_1M0_0402; 0402-res; MPN CRG0402F1M0
R53: R_1k_0402; 0402-res; MPN CR0402-FX-1001GLF
R55, R56, R61, R62: R_2k2_0402; 0402-res; MPN RC0402FR-072K2L
R57, R60, R80, R90: R_0R_0402; 0402-res; MPN ERJ2GE0R00X
R58: R_7k68_0603; 0603-res; MPN WR06X7681FTL
R59, R89: R_20k_0402; 0402-res; MPN CRCW040220K0FKED
R63, R64, R65, R66, R67, R68, R69, R70: R_50R_0402; 0402-res; MPN RN73R1ETTP50R0F50
R71, R72, R73: R_2k_0402; 0402-res; MPN CRCW04022K00FKED
R75, R76, R81, R82, R84, R85, R86, R87: R_510_0402; 0402-res; MPN CRCW0402510RFKEDC
R83: R_27k_0402; 0402-res; MPN ERJ2RKF2702X
TP67, TP68, TP69, TP70: TP; TP-R-1.5
U7: LT9611UXC; LT9611; MPN LT9611
U8: NTS0102GT; PSON50P100X195X50-8N; MPN NTS0102GT
Y1: ABM8G-24.000MHZ-18-D2Y-T; KX-7; MPN ABM8G-24.000MHZ-18-D2Y-T

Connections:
1V2_SYS: L13.1, L14.1, L15.1; also elsewhere on the board
3V3_SYS: L5.1, L6.1, L7.1; also elsewhere on the board
5V0_SYS: D10.A; also elsewhere on the board
/display module/CEC_HDMI: D6.5 (CH4), D6.6 (CH4), J4.15 (CEC), Q4.3 (D), R80.2, R83.2
/display module/CEC_LT: Q4.2 (S), R80.1, U7.24 (CEC_GPIO6)
/display module/DETECT_HDMI: J4.1 (HPD/HEAC-), R60.2, R89.1
/display module/INT0: Q5.3 (D), R54.2, U7.23 (INTIO_GPIO5)
/display module/LTtoHDMI_SCL: D6.4 (CH3), D6.7 (CH3), J4.17 (SCL), R62.2, U7.37 (HTX_DSCL)
/display module/LTtoHDMI_SDA: D6.2 (CH2), D6.9 (CH2), J4.18 (SDA), R61.2, U7.36 (HTX_DSDA)
/display module/RST_N: C46.1, Q6.3 (D), R49.2, U7.17 (RST_N)
/display module/SoMtoDisplay_Ferr_CLK_N: J3.14, L12.3
/display module/SoMtoDisplay_Ferr_CLK_P: J3.15, L12.2
/display module/SoMtoDisplay_Ferr_D0_N: J3.11, L11.3
/display module/SoMtoDisplay_Ferr_D0_P: J3.12, L11.2
/display module/SoMtoDisplay_Ferr_D1_N: J3.8, L10.3
/display module/SoMtoDisplay_Ferr_D1_P: J3.9, L10.2
/display module/SoMtoDisplay_Ferr_D2_N: J3.5, L9.3
/display module/SoMtoDisplay_Ferr_D2_P: J3.6, L9.2
/display module/SoMtoDisplay_Ferr_D3_N: J3.2, L8.3
/display module/SoMtoDisplay_Ferr_D3_P: J3.3, L8.2
/display module/SoMtoLT_SCL: R50.2, U7.18 (CSCL_GPIO10), U8.8 (B1)
/display module/SoMtoLT_SDA: R51.2, U7.19 (CSDA_GPIO11), U8.1 (B2)
/display module/TX_CLK_C_N: C78.1, L19.4, R75.2
/display module/TX_CLK_C_P: C77.1, L19.1, R76.2
/display module/TX_CLK_Ferr_N: C81.1, D30.1 (CH1), D30.10 (CH1), J4.14 (CK-), L19.3
/display module/TX_CLK_Ferr_P: C82.1, D30.2 (CH2), D30.9 (CH2), J4.12 (CK+), L19.2
/display module/TX_CLK_N: C78.2, R70.2, U7.38 (HTX_C-)
/display module/TX_CLK_P: C77.2, R69.2, U7.39 (HTX_C+)
/display module/TX_D0_C_N: C76.1, L18.1, R81.2
/display module/TX_D0_C_P: C75.1, L18.4, R82.2
/display module/TX_D0_Ferr_N: D29.1 (CH1), D29.10 (CH1), J4.11 (D0-), L18.2
/display module/TX_D0_Ferr_P: D29.2 (CH2), D29.9 (CH2), J4.9 (D0+), L18.3
/display module/TX_D0_N: C76.2, R68.2, U7.40 (HTX_D0-)
/display module/TX_D0_P: C75.2, R67.2, U7.41 (HTX_D0+)
/display module/TX_D1_C_N: C74.1, L17.4, R84.2
/display module/TX_D1_C_P: C73.1, L17.1, R85.2
/display module/TX_D1_Ferr_N: D30.4 (CH3), D30.7 (CH3), J4.8 (D1-), L17.3
/display module/TX_D1_Ferr_P: D30.5 (CH4), D30.6 (CH4), J4.6 (D1+), L17.2
/display module/TX_D1_N: C74.2, R66.2, U7.45 (HTX_D1-)
/display module/TX_D1_P: C73.2, R65.2, U7.46 (HTX_D1+)
/display module/TX_D2_C_N: C72.1, L16.1, R86.2
/display module/TX_D2_C_P: C71.1, L16.4, R87.2
/display module/TX_D2_Ferr_N: D29.4 (CH3), D29.7 (CH3), J4.5 (D2-), L16.2
/display module/TX_D2_Ferr_P: D29.5 (CH4), D29.6 (CH4), J4.3 (D2+), L16.3
/display module/TX_D2_N: C72.2, R64.2, U7.47 (HTX_D2-)
/display module/TX_D2_P: C71.2, R63.2, U7.48 (HTX_D2+)
/display module/UTILITY: J4.2 (UTILITY/HEAC+), R90.1
/display module/V_COMM: C80.1, Q3.3 (D), R75.1, R76.1, R81.1, R82.1, R84.1, R85.1, R86.1, R87.1, U7.42 (VCOM)
GND: C46.2, C47.1, C48.2, C49.2, C50.1, C51.2, C52.2, C53.2, C54.1, C55.2, C56.1, C57.2, C58.2, C59.1, C60.1, C61.2, C62.1, C63.1, C64.2, C65.1, C66.1, C67.1, C68.2, C69.2, C70.2, C79.2, C80.2, C81.2, C82.2, C85.2, C86.2, D6.3 (GND), D6.8 (GND), D29.3 (GND), D29.8 (GND), D30.3 (GND), D30.8 (GND), J3.1, J3.4, J3.7, J3.10, J3.13, J3.16, J3.19, J4.4 (D2S), J4.7 (D1S), J4.10 (D0S), J4.13 (CKS), J4.16 (GND), J4.SH, Q3.2 (S), R57.2, R58.2, R59.2, R88.2, R89.2, R90.2, U7.65 (GND), U8.2 (GND), Y1.2 (GND), Y1.4 (GND); also elsewhere on the board
HDMI_I2C_SCL: R71.1, U8.5 (A1); also elsewhere on the board
HDMI_I2C_SDA: R72.1, U8.4 (A2); also elsewhere on the board
LDO6_1P8: C70.1, Q5.1 (G), Q6.1 (G), R55.2, R56.2, R71.2, R72.2, R73.2, R77.1, R78.1, U8.3 (VCC_A); also elsewhere on the board
LDO17_2P85: C58.1, J3.20; also elsewhere on the board
LT9611_INT0: Q5.2 (S), R77.2; also elsewhere on the board
LT9611_RST_N: Q6.2 (S), R78.2; also elsewhere on the board
LT9611_VCC12_RX: C60.2, C63.2, C66.2, L14.2, U7.4 (VCC12_MRX01), U7.56 (VCC12_MRX23)
LT9611_VCC12_TX: C61.1, C64.1, L15.2, U7.44 (VCC12_HTX)
LT9611_VCC33_IO: C49.1, C52.1, C55.1, C79.1, D9.A, L7.2, R49.1, R50.1, R51.1, R53.2, R54.1, R61.1, R62.1, R74.1, R79.1, U7.26 (VC33_IO), U7.34 (VCC33_IO), U8.7 (VCC_B)
LT9611_VCC33_RX: C47.2, C50.2, C54.2, C56.2, L5.2, U7.3 (VCC33_MRX01), U7.51 (VCC33_BG), U7.55 (VCC33_MRX23)
LT9611_VCC33_TX: C48.1, C51.1, L6.2, R63.1, R64.1, R65.1, R66.1, R67.1, R68.1, R69.1, R70.1, U7.43 (VCC33_HTX)
LT9611_VDD12: C59.2, C62.2, C65.2, C67.2, C68.1, C69.1, L13.2, U7.15 (VDD1), U7.16 (VDD2), U7.31 (VDD3), U7.53 (VCC12_SYSPLL), U7.54 (VDD)
unnamed: C53.1, R52.1, U7.50 (XTALO), Y1.1
unnamed: C57.1, R52.2, U7.49 (XTALI), Y1.3
unnamed: C85.1, C86.1, D10.K, J4.19 (+5V), R88.1, TP70.1
unnamed: D6.1 (CH1), D6.10 (CH1)
unnamed: D9.K, R83.1
unnamed: Q3.1 (G), R74.2
unnamed: Q4.1 (G), R79.2
unnamed: R53.1, R57.1, U7.25 (I2C_ADDR)
unnamed: R58.1, U7.52 (REXT)
unnamed: R59.1, R60.1, TP67.1, U7.35 (HTX_HPD)
unnamed: R73.1, U8.6 (OE)
SoMtoDisplay_CLK_N: L12.4; also elsewhere on the board
SoMtoDisplay_CLK_P: L12.1; also elsewhere on the board
SoMtoDisplay_D0_N: L11.4; also elsewhere on the board
SoMtoDisplay_D0_P: L11.1; also elsewhere on the board
SoMtoDisplay_D1_N: L10.4; also elsewhere on the board
SoMtoDisplay_D1_P: L10.1; also elsewhere on the board
SoMtoDisplay_D2_N: L9.4; also elsewhere on the board
SoMtoDisplay_D2_P: L9.1; also elsewhere on the board
SoMtoDisplay_D3_N: L8.4; also elsewhere on the board
SoMtoDisplay_D3_P: L8.1; also elsewhere on the board
SoMtoLT_CLK_N: U7.9 (MC_N0); also elsewhere on the board
SoMtoLT_CLK_P: U7.10 (MC_P0); also elsewhere on the board
SoMtoLT_D0_N: U7.13 (M0_N0); also elsewhere on the board
SoMtoLT_D0_P: U7.14 (M0_P0); also elsewhere on the board
SoMtoLT_D1_N: U7.11 (M1_N0); also elsewhere on the board
SoMtoLT_D1_P: U7.12 (M1_P0); also elsewhere on the board
SoMtoLT_D2_N: U7.7 (M2_N0); also elsewhere on the board
SoMtoLT_D2_P: U7.8 (M2_P0); also elsewhere on the board
SoMtoLT_D3_N: U7.5 (M3_N0); also elsewhere on the board
SoMtoLT_D3_P: U7.6 (M3_P0); also elsewhere on the board
TP0_I2C_SCL: J3.17, R56.1, TP69.1; also elsewhere on the board
TP0_I2C_SDA: J3.18, R55.1, TP68.1; also elsewhere on the board

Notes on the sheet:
MIPI DSI to HDMI
TP + LCD Interface

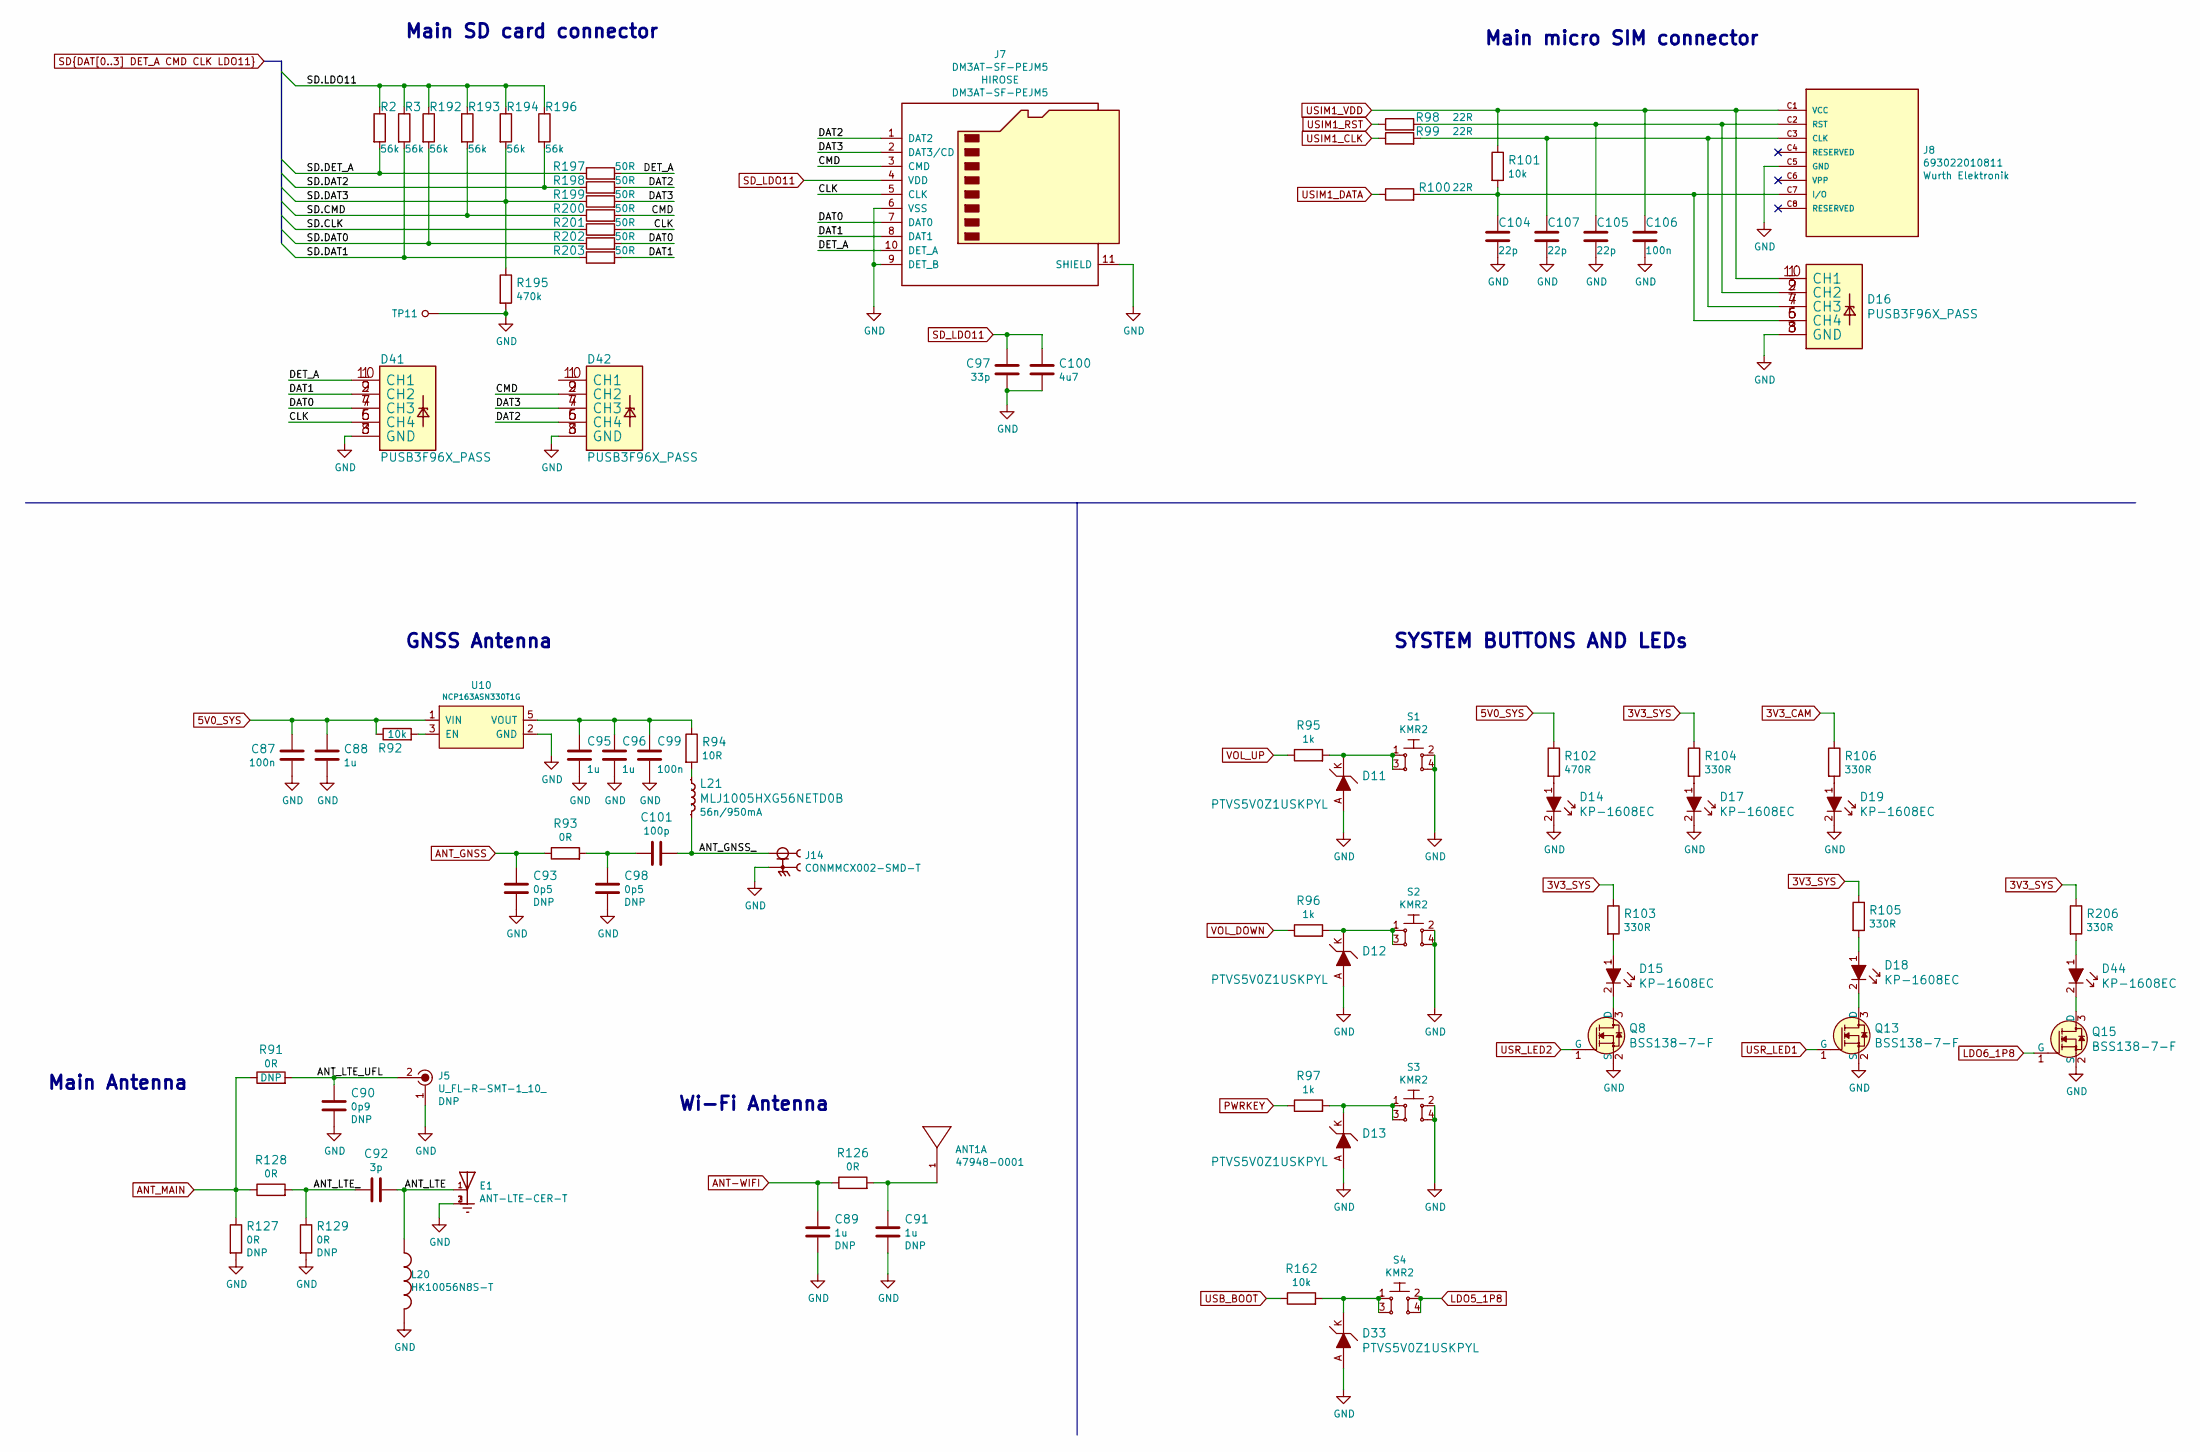
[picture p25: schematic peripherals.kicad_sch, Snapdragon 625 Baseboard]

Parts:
ANT1: 47948-0001; MPN 47948-0001
C87, C99: C_100n_0402; 0402-cap; MPN GRM155R61H104KE14D
C88, C89, C91, C95, C96: C_1u_0402; 0402-cap; MPN C1005X6S1A105K050BC
C90: C_0p9_0402; 0402-cap; MPN GJM1555C1HR90DB01D
C92: C_3p_0402; 0402-cap; MPN MC0402N3R0C500CT
C93, C98: C_0p5_0402; 0402-cap; MPN GJM1555C1HR50WB01D
C97: C_33p_0402; 0402-cap; MPN MC0402N330J500CT
C100: C_4u7_0402; 0402-cap; MPN GRM155R61A475MEAAD
C101: C_100p_0402; 0402-cap; MPN 0402N101J500CT
C104, C105, C107: C_22p_0402; 0402-cap; MPN CC0402JRNPO9BN220
C106: C_100n_0402; 0402-cap; MPN 0402X104K6R3CT
D11, D12, D13, D33: PTVS5V0Z1USKPYL; SOD-964; MPN PTVS5V0Z1USKPYL
D14, D15, D17, D18, D19, D44: KP-1608EC; LED_0603; MPN KP-1608EC
D16, D41, D42: PUSB3F96X_PASS; PUSB3F96X; MPN PUSB3F96X
E1: ANT-LTE-CER-T; XDCR_ANT-LTE-CER-T; MPN ANT-LTE-CER-T
J5: U_FL-R-SMT-1_10_; Coax_Conn_U.FL; MPN U.FL-R-SMT-1(10)
J7: DM3AT-SF-PEJM5; MicroSD_DM3AT-SF-PEJM5; MPN DM3AT-SF-PEJM5
J8: 693022010811; MPN 693022010811
J14: CONMMCX002-SMD-T; LINX_CONMMCX002-SMD-T; MPN CONMMCX002-SMD-T
L20: HK10056N8S-T; INDC1005X55N; MPN HK10056N8S-T
L21: MLJ1005HXG56NETD0B; 0402-res; MPN MLJ1005HXG56NETD0B
Q8, Q13, Q15: BSS138-7-F; SOT-23-3; MPN BSS138-7-F
R2, R3, R192, R193, R194, R196: R_56k_0402; 0402-res; MPN CRCW040256K0FKED
R91, R93, R126, R127, R128, R129: R_0R_0402; 0402-res; MPN ERJ2GE0R00X
R92, R101, R162: R_10k_0402; 0402-res; MPN CRCW040210K0FKEDHP
R94: R_10R_0603; 0603-res; MPN MCWR06X10R0FTL
R95, R96, R97: R_1k_0402; 0402-res; MPN CR0402-FX-1001GLF
R98, R99, R100: R_22R_0402; 0402-res; MPN CRCW040222R0FKED
R102: R_470R_0402; 0402-res; MPN CRCW0402470RFKED
R103, R104, R105, R106, R206: R_330R_0402; 0402-res; MPN MCMR04X3300FTL
R195: R_470k_0402; 0402-res; MPN RC0402FR-07470KL
R197, R198, R199, R200, R201, R202, R203: R_50R_0402; 0402-res; MPN RN73R1ETTP50R0F50
S1, S2, S3, S4: KMR2; SW_SPST_4.2x2.8; MPN KMR211NGLFS
TP11: TP_SMD_1_5MM; TP-R-1.5
U10: NCP163ASN330T1G; SOT-23-5; MPN NCP163ASN330T1G

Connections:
3V3_CAM: R106.1; also elsewhere on the board
3V3_SYS: R103.1, R104.1, R105.1, R206.1; also elsewhere on the board
5V0_SYS: C87.1, C88.1, R92.1, R102.1, U10.1 (VIN); also elsewhere on the board
/peripherals/ANT_GNSS_: C101.1, J14.1, L21.2
/peripherals/ANT_LTE: C92.1, E1.1, L20.1
/peripherals/ANT_LTE_: C92.2, R128.2, R129.1
/peripherals/ANT_LTE_UFL: C90.1, J5.2, R91.2
/peripherals/CLK: D41.5 (CH4), D41.6 (CH4), J7.5 (CLK), R201.2
/peripherals/CMD: D42.2 (CH2), D42.9 (CH2), J7.3 (CMD), R200.2
/peripherals/DAT0: D41.4 (CH3), D41.7 (CH3), J7.7 (DAT0), R202.2
/peripherals/DAT1: D41.2 (CH2), D41.9 (CH2), J7.8 (DAT1), R203.2
/peripherals/DAT2: D42.5 (CH4), D42.6 (CH4), J7.1 (DAT2), R198.2
/peripherals/DAT3: D42.4 (CH3), D42.7 (CH3), J7.2 (DAT3/CD), R199.2
/peripherals/DET_A: D41.1 (CH1), D41.10 (CH1), J7.10 (DET_A), R197.2
ANT-WIFI: C89.1, R126.1; also elsewhere on the board
ANT_GNSS: C93.1, R93.1; also elsewhere on the board
ANT_MAIN: R91.1, R127.1, R128.1; also elsewhere on the board
GND: C87.2, C88.2, C89.2, C90.2, C91.2, C93.2, C95.2, C96.2, C97.2, C98.2, C99.2, C100.2, C104.2, C105.2, C106.2, C107.2, D11.A, D12.A, D13.A, D14.2, D16.3 (GND), D16.8 (GND), D17.2, D19.2, D33.A, D41.3 (GND), D41.8 (GND), D42.3 (GND), D42.8 (GND), E1.2, E1.3, J5.1, J7.6 (VSS), J7.9 (DET_B), J7.11 (SHIELD), J8.C5 (GND), J8.Z1 (GND), J8.Z2 (GND), J14.S1, J14.S2, J14.S3, J14.S4, L20.2, Q8.2 (S), Q13.2 (S), Q15.2 (S), R127.2, R129.2, R195.2, S1.2, S1.4, S2.2, S2.4, S3.2, S3.4, TP11.1, U10.2 (GND); also elsewhere on the board
LDO5_1P8: S4.2, S4.4; also elsewhere on the board
LDO6_1P8: Q15.1 (G); also elsewhere on the board
unnamed: ANT1.1 (FEEDING_PAD), C91.1, R126.2
unnamed: C95.1, C96.1, C99.1, R94.1, U10.5 (VOUT)
unnamed: C98.1, C101.2, R93.2
unnamed: C104.1, D16.5 (CH4), D16.6 (CH4), J8.C7 (I/O), R100.2, R101.2
unnamed: C105.1, D16.2 (CH2), D16.9 (CH2), J8.C2 (RST), R98.2
unnamed: C107.1, D16.4 (CH3), D16.7 (CH3), J8.C3 (CLK), R99.2
unnamed: D11.K, R95.2, S1.1, S1.3
unnamed: D12.K, R96.2, S2.1, S2.3
unnamed: D13.K, R97.2, S3.1, S3.3
unnamed: D14.1, R102.2
unnamed: D15.1, R103.2
unnamed: D15.2, Q8.3 (D)
unnamed: D17.1, R104.2
unnamed: D18.1, R105.2
unnamed: D18.2, Q13.3 (D)
unnamed: D19.1, R106.2
unnamed: D33.K, R162.2, S4.1, S4.3
unnamed: D42.1 (CH1), D42.10 (CH1)
unnamed: D44.1, R206.2
unnamed: D44.2, Q15.3 (D)
unnamed: L21.1, R94.2
unnamed: R92.2, U10.3 (EN)
PWRKEY: R97.1; also elsewhere on the board
SD_DATA_0: R192.2, R202.1; also elsewhere on the board
SD_DATA_1: R3.2, R203.1; also elsewhere on the board
SD_DATA_2: R196.2, R198.1; also elsewhere on the board
SD_DATA_3: R194.2, R195.1, R199.1; also elsewhere on the board
SD_DATA_4: R201.1; also elsewhere on the board
SD_DATA_5: R193.2, R200.1; also elsewhere on the board
SD_DATA_6: R2.2, R197.1; also elsewhere on the board
USB_BOOT: R162.1; also elsewhere on the board
USIM1_CLK: R99.1; also elsewhere on the board
USIM1_DATA: R100.1; also elsewhere on the board
USIM1_RST: R98.1; also elsewhere on the board
USIM1_VDD: C106.1, D16.1 (CH1), D16.10 (CH1), J8.C1 (VCC), R101.1; also elsewhere on the board
USR_LED1: Q13.1 (G); also elsewhere on the board
USR_LED2: Q8.1 (G); also elsewhere on the board
VOL_DOWN: R96.1; also elsewhere on the board
VOL_UP: R95.1; also elsewhere on the board

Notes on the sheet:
Main micro SIM connector
GNSS Antenna
Main Antenna
Main SD card connector
Wi-Fi Antenna
SYSTEM BUTTONS AND LEDs

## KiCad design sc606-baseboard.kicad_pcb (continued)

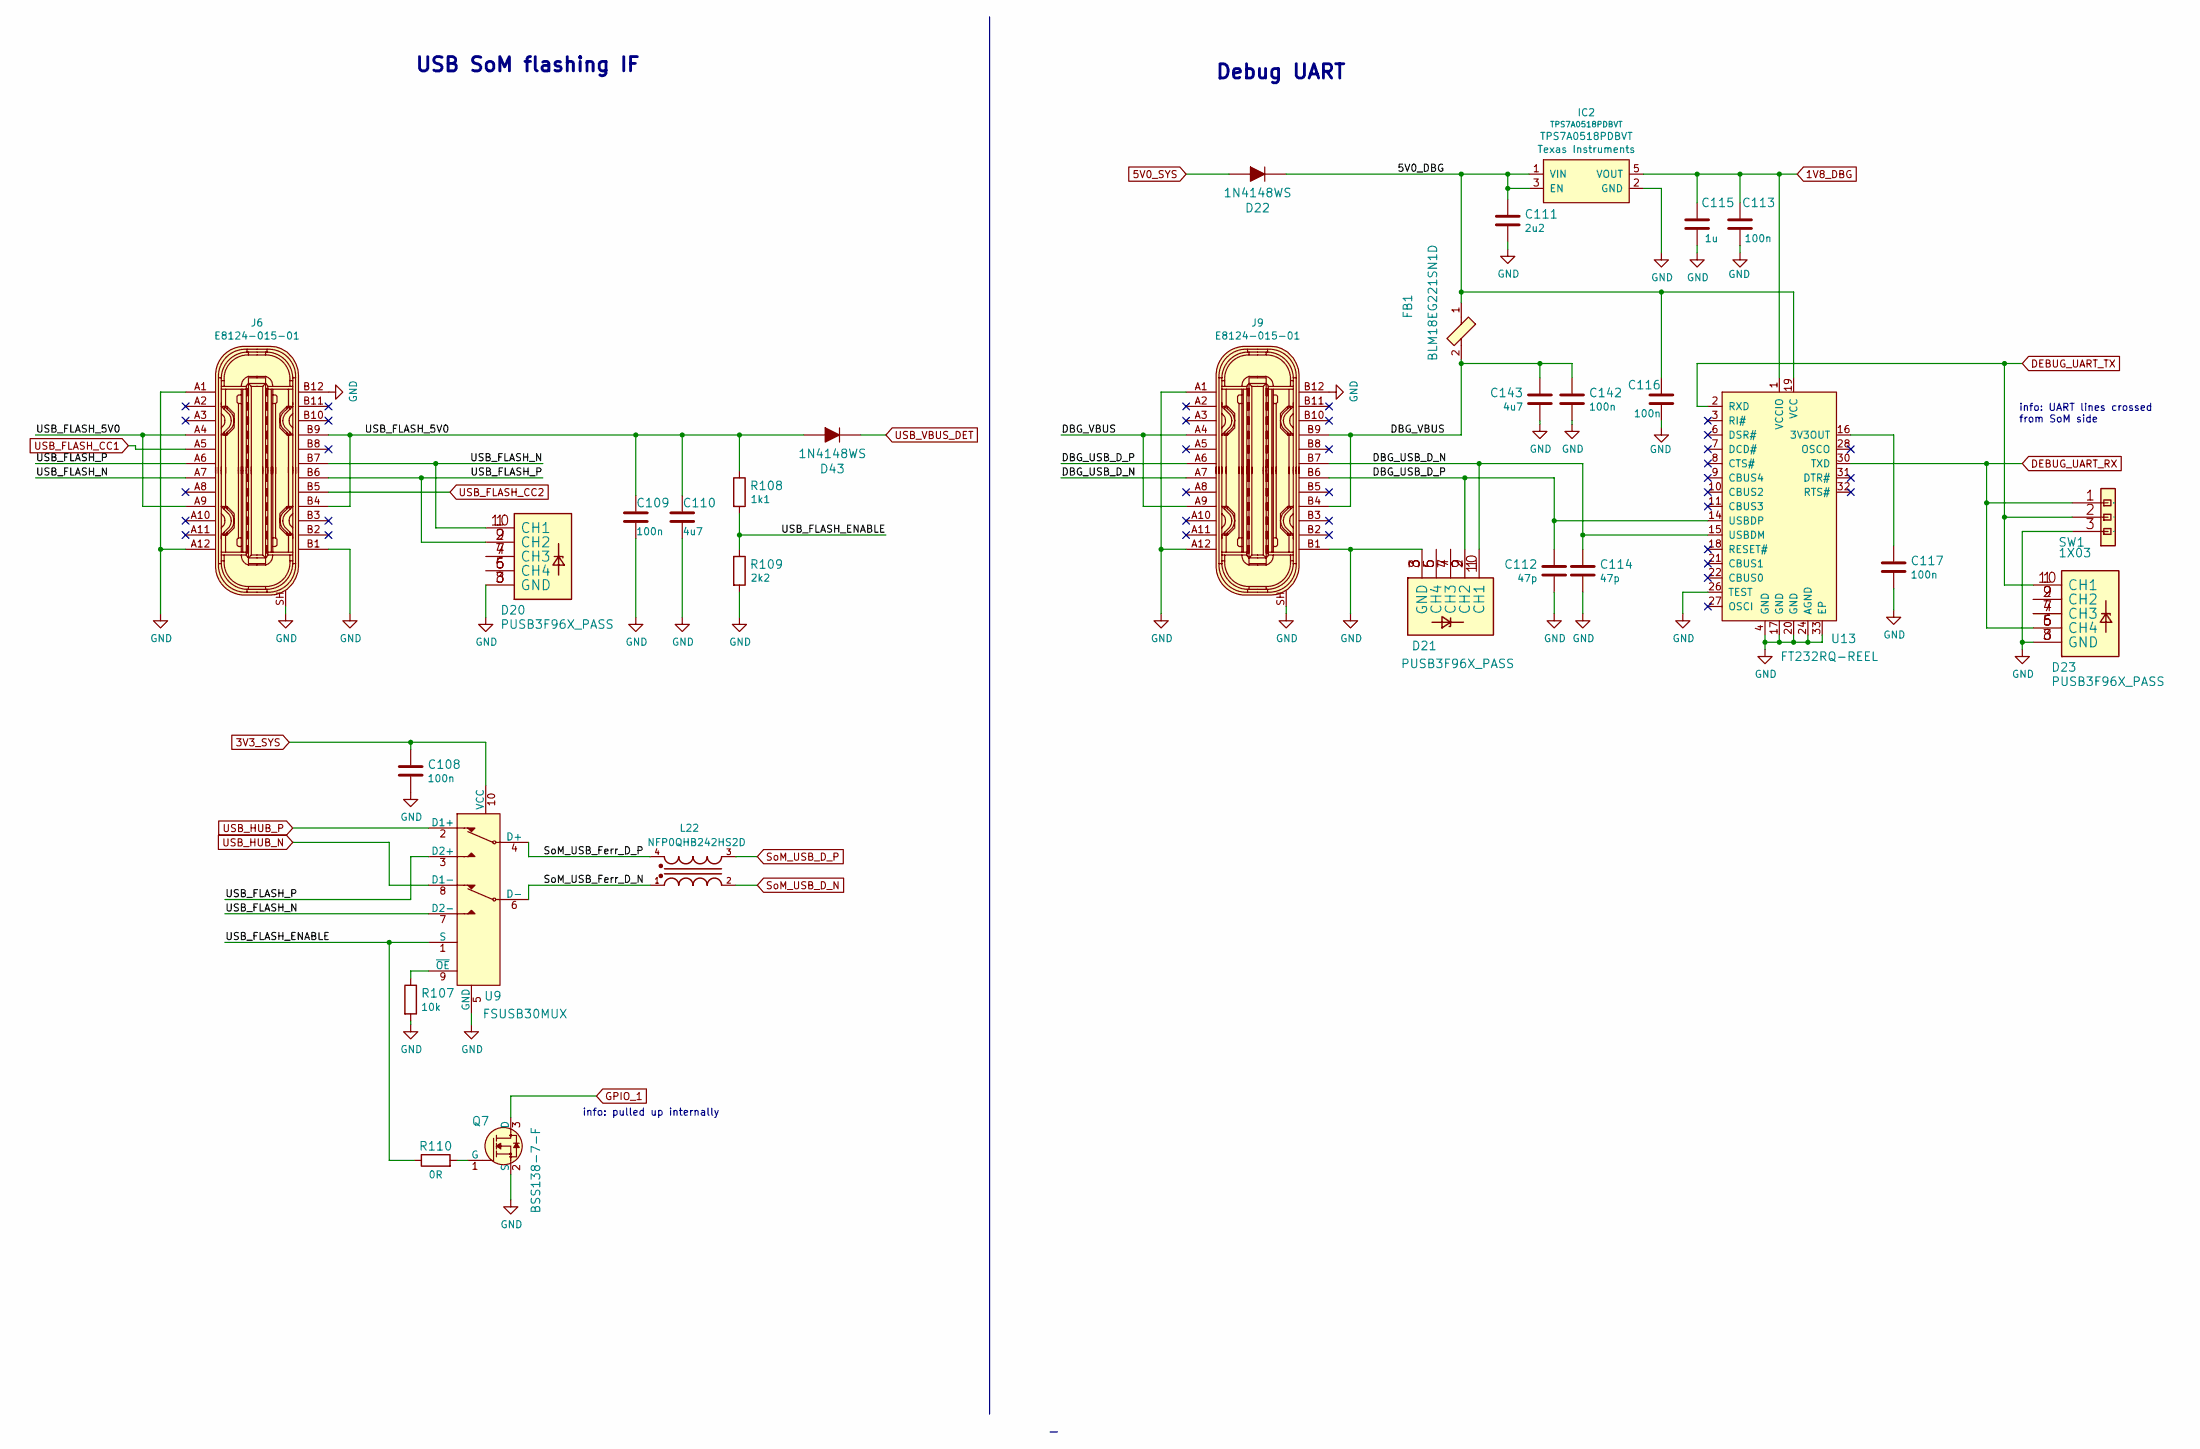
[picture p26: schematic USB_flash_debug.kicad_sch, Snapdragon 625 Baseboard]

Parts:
C108, C109, C113, C116, C117, C142: C_100n_0402; 0402-cap; MPN GRM155R61H104KE14D
C110, C143: C_4u7_0402; 0402-cap; MPN GRM155R61A475MEAAD
C111: C_2u2_0402; 0402-cap; MPN C1005X5R1A225K050BC
C112, C114: C_47p_0402; 0402-cap; MPN C0402C470J5GACTU
C115: C_1u_0402; 0402-cap; MPN C1005X6S1A105K050BC
D20, D21, D23: PUSB3F96X_PASS; PUSB3F96X; MPN PUSB3F96X
D22, D43: 1N4148WS; SOD-323F; MPN 1N4148WS
FB1: BLM18EG221SN1D; 0603; MPN BLM18EG221SN1D
IC2: TPS7A0518PDBVT; SOT-23-5; MPN TPS7A0518PDBVT
J6, J9: E8124-015-01; USB-C_Female_E8124-015-01; MPN E8124-015-01
L22: NFP0QHB242HS2D; FIL_NFP0QHB242HS2D; MPN NFP0QHB242HS2D
Q7: BSS138-7-F; SOT-23-3; MPN BSS138-7-F
R107: R_10k_0402; 0402-res; MPN CRCW040210K0FKEDHP
R108: R_1k1_0402; 0402-res; MPN ERJ2RKF1101X
R109: R_2k2_0402; 0402-res; MPN RC0402FR-072K2L
R110: R_0R_0402; 0402-res; MPN ERJ2GE0R00X
SW1: 1X03; MH_1X03_2.54; MPN 61300311121
U9: FSUSB30MUX; MSOP-10_W3mm; MPN FSUSB30MUX
U13: FT232RQ-REEL; QFN-32-1EP_5x5mm; MPN FT232RQ-REEL

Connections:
1V8_DBG: C113.1, C115.1, IC2.5 (VOUT), U13.1 (VCCIO)
3V3_SYS: C108.1, U9.10 (VCC); also elsewhere on the board
5V0_SYS: D22.A; also elsewhere on the board
/USB_flash_debug/5V0_DBG: C111.1, C116.1, D22.K, FB1.1, IC2.1 (VIN), IC2.3 (EN), U13.19 (VCC)
/USB_flash_debug/DBG_USB_D_N: C114.1, D21.1 (CH1), D21.10 (CH1), J9.A7, J9.B7, U13.15 (USBDM)
/USB_flash_debug/DBG_USB_D_P: C112.1, D21.2 (CH2), D21.9 (CH2), J9.A6, J9.B6, U13.14 (USBDP)
/USB_flash_debug/DBG_VBUS: C142.1, C143.1, FB1.2, J9.A4, J9.A9, J9.B4, J9.B9
/USB_flash_debug/SoM_USB_Ferr_D_N: L22.1, U9.6 (D-)
/USB_flash_debug/SoM_USB_Ferr_D_P: L22.4, U9.4 (D+)
/USB_flash_debug/USB_FLASH_5V0: C109.1, C110.1, D43.A, J6.A4, J6.A9, J6.B4, J6.B9, R108.1
/USB_flash_debug/USB_FLASH_ENABLE: R108.2, R109.1, R110.1, U9.1 (S)
/USB_flash_debug/USB_FLASH_N: D20.1 (CH1), D20.10 (CH1), J6.A7, J6.B7, U9.7 (D2-)
/USB_flash_debug/USB_FLASH_P: D20.2 (CH2), D20.9 (CH2), J6.A6, J6.B6, U9.3 (D2+)
DEBUG_UART_RX: D23.5 (CH4), D23.6 (CH4), SW1.1, U13.30 (TXD); also elsewhere on the board
DEBUG_UART_TX: D23.1 (CH1), D23.10 (CH1), SW1.2, U13.2 (RXD); also elsewhere on the board
GND: C108.2, C109.2, C110.2, C111.2, C112.2, C113.2, C114.2, C115.2, C116.2, C117.1, C142.2, C143.2, D20.3 (GND), D20.8 (GND), D21.3 (GND), D21.8 (GND), D23.3 (GND), D23.8 (GND), IC2.2 (GND), J6.A1, J6.A12, J6.B1, J6.B12, J6.SH, J9.A1, J9.A12, J9.B1, J9.B12, J9.SH, Q7.2 (S), R107.2, R109.2, SW1.3, U9.5 (GND), U13.4 (GND), U13.17 (GND), U13.20 (GND), U13.24 (AGND), U13.26 (TEST), U13.33 (EP); also elsewhere on the board
GPIO_1: Q7.3 (D); also elsewhere on the board
unnamed: C117.2, U13.16 (3V3OUT)
unnamed: D20.4 (CH3), D20.7 (CH3)
unnamed: D20.5 (CH4), D20.6 (CH4)
unnamed: D21.4 (CH3), D21.7 (CH3)
unnamed: D21.5 (CH4), D21.6 (CH4)
unnamed: D23.2 (CH2), D23.9 (CH2)
unnamed: D23.4 (CH3), D23.7 (CH3)
unnamed: Q7.1 (G), R110.2
unnamed: R107.1, U9.9 (~OE)
SoM_USB_D_N: L22.2; also elsewhere on the board
SoM_USB_D_P: L22.3; also elsewhere on the board
USB_FLASH_CC1: J6.A5; also elsewhere on the board
USB_FLASH_CC2: J6.B5; also elsewhere on the board
USB_HUB_N: U9.8 (D1-); also elsewhere on the board
USB_HUB_P: U9.2 (D1+); also elsewhere on the board
USB_VBUS_DET: D43.K; also elsewhere on the board

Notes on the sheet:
info: UART lines crossed from SoM side
info: pulled up internally
Debug UART
USB SoM flashing IF

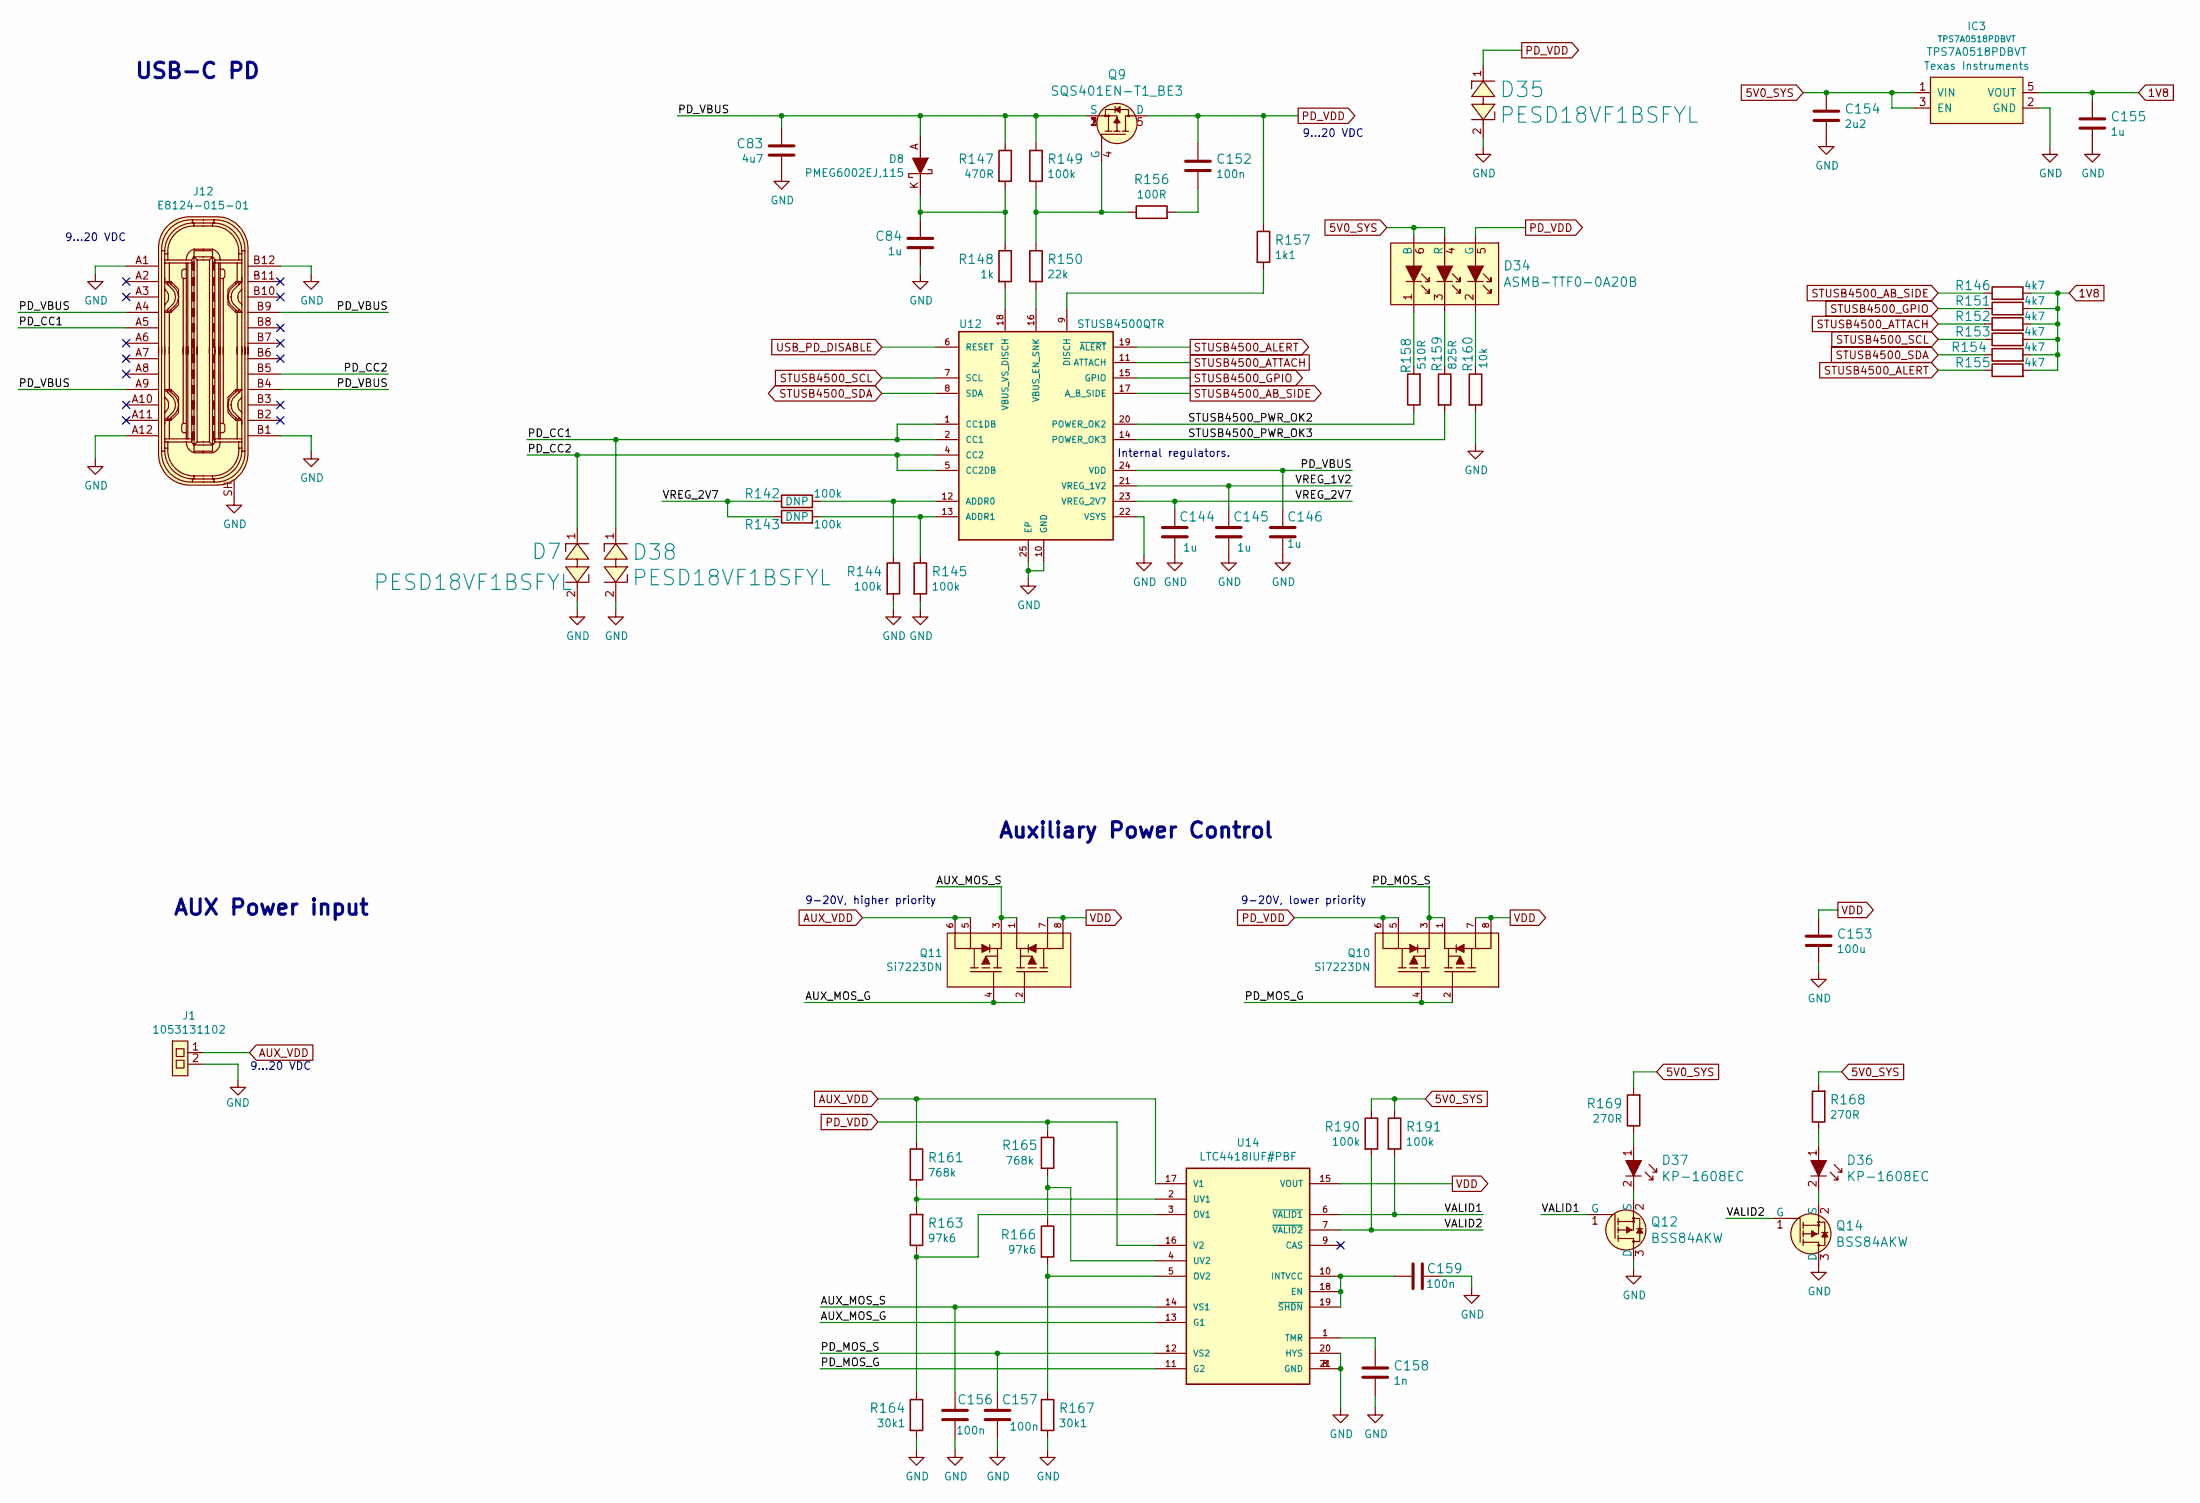
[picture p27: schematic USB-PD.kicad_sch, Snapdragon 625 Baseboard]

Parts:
C83: C_4u7_0603; 0603-cap; MPN C1608X5R1V475M080AC
C84: C_1u_0603; 0603-cap; MPN 0603YD105KAT2A
C144, C145, C146, C155: C_1u_0402; 0402-cap; MPN C1005X6S1A105K050BC
C152, C156, C157, C159: C_100n_0402; 0402-cap; MPN GRM155R61H104KE14D
C153: C_100u_0805; 0805-cap; MPN GRM21BR60J107ME15L
C154: C_2u2_0402; 0402-cap; MPN C1005X5R1A225K050BC
C158: C_1n_0402; 0402-res; MPN CC0402KRX7R9BB102
D7, D35, D38: PESD18VF1BSFYL; RESC0603X26N; MPN PESD18VF1BSFYL
D8: PMEG6002EJ,115; SOD-323F; MPN PMEG6002EJ,115
D34: ASMB-TTF0-0A20B; PLCC6_3.5x3.7mm; MPN ASMB-TTF0-0A20B
D36, D37: KP-1608EC; LED_0603; MPN KP-1608EC
IC3: TPS7A0518PDBVT; SOT-23-5; MPN TPS7A0518PDBVT
J1: 1053131102; MPN 1053131102
J12: E8124-015-01; USB-C_Female_E8124-015-01; MPN E8124-015-01
Q9: SQS401EN-T1_BE3; Vishay_PowerPAK_1212-8_Single; MPN SQS401EN-T1_BE3
Q10, Q11: Si7223DN; PowerPak-1212; MPN SI7223DN-T1-GE3
Q12, Q14: BSS84AKW; SOT-323; MPN BSS84AKW,115
R142, R143, R144, R145, R149, R190, R191: R_100k_0402; 0402-res; MPN CRCW0402100KFKEDHP
R146, R151, R152, R153, R154, R155: R_4k7_0402; 0402-res; MPN MCS04020C4701FE000
R147: R_470R_0402; 0402-res; MPN CRCW0402470RFKED
R148: R_1k_0402; 0402-res; MPN CR0402-FX-1001GLF
R150: R_22k_0402; 0402-res; MPN ERJ-2RKF2202X
R156: R_100R_0402; 0402-res; MPN CR0402-FX-1000GLF
R157: R_1k1_0402; 0402-res; MPN ERJ2RKF1101X
R158: R_510R_0402; 0402-res; MPN RC0402JR-07510RL
R159: R_825R_0402; 0402-res; MPN ERJ2RKF8250X
R160: R_10k_0402; 0402-res; MPN CRCW040210K0FKEDHP
R161, R165: R_768k_0402; 0402-res; MPN CRCW0402768KFKED
R163, R166: R_97k6_0402; 0402-res; MPN MCMR04X9762FTL
R164, R167: R_30k1_0603; 0603-res; MPN CRCW060330K1FKEA
R168, R169: R_270R_0603; 0603-res; MPN ERJ3EKF2700V
U12: STUSB4500QTR; QFN50P400X400X90-25N; MPN STUSB4500QTR
U14: LTC4418IUF#PBF; QFN-20_1EP_4x4_P0.5mm; MPN LTC4418IUF#PBF

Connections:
1V8: C155.1, IC3.5 (VOUT), R146.2, R151.2, R152.2, R153.2, R154.2, R155.2
5V0_SYS: C154.1, D34.4 (R), D34.6 (B), IC3.1 (VIN), IC3.3 (EN), R168.2, R169.2, R190.1, R191.1; also elsewhere on the board
/USB-PD/AUX_MOS_G: Q11.2, Q11.4, U14.13 (G1)
/USB-PD/AUX_MOS_S: C156.2, Q11.1, Q11.3, U14.14 (VS1)
/USB-PD/PD_CC1: D38.1, J12.A5, U12.1 (CC1DB), U12.2 (CC1)
/USB-PD/PD_CC2: D7.1, J12.B5, U12.4 (CC2), U12.5 (CC2DB)
/USB-PD/PD_MOS_G: Q10.2, Q10.4, U14.11 (G2)
/USB-PD/PD_MOS_S: C157.2, Q10.1, Q10.3, U14.12 (VS2)
/USB-PD/PD_VBUS: C83.1, C146.1, D8.A, J12.A4, J12.A9, J12.B4, J12.B9, Q9.1 (S), Q9.2 (S), Q9.3 (S), R147.1, R149.1, U12.24 (VDD)
/USB-PD/STUSB4500_PWR_OK2: R158.1, U12.20 (POWER_OK2)
/USB-PD/STUSB4500_PWR_OK3: R159.2, U12.14 (POWER_OK3)
/USB-PD/VALID1: Q12.1 (G), R191.2, U14.6 (~VALID1)
/USB-PD/VALID2: Q14.1 (G), R190.2, U14.7 (~VALID2)
/USB-PD/VREG_1V2: C145.2, U12.21 (VREG_1V2)
/USB-PD/VREG_2V7: C144.1, R142.1, R143.1, U12.23 (VREG_2V7)
AUX_VDD: J1.1, Q11.5, Q11.6, R161.1, U14.17 (V1)
GND: C83.2, C84.2, C144.2, C145.1, C146.2, C153.2, C154.2, C155.2, C156.1, C157.1, C158.2, C159.1, D7.2, D35.2, D38.2, IC3.2 (GND), J1.2, J12.A1, J12.A12, J12.B1, J12.B12, J12.SH, Q12.3 (D), Q14.3 (D), R144.2, R145.2, R160.2, R164.2, R167.2, U12.10 (GND), U12.22 (VSYS), U12.25 (EP), U14.8 (GND), U14.20 (HYS), U14.21 (GND); also elsewhere on the board
unnamed: C84.1, D8.K, R147.2, R148.1
unnamed: C152.2, R156.2
unnamed: C158.1, U14.1 (TMR)
unnamed: C159.2, U14.10 (INTVCC), U14.18 (EN), U14.19 (~SHDN)
unnamed: D34.1, R158.2
unnamed: D34.2, R160.1
unnamed: D34.3, R159.1
unnamed: D36.1, R168.1
unnamed: D36.2, Q14.2 (S)
unnamed: D37.1, R169.1
unnamed: D37.2, Q12.2 (S)
unnamed: Q9.4 (G), R149.2, R150.1, R156.1
unnamed: R142.2, R144.1, U12.12 (ADDR0)
unnamed: R143.2, R145.1, U12.13 (ADDR1)
unnamed: R148.2, U12.18 (VBUS_VS_DISCH)
unnamed: R150.2, U12.16 (VBUS_EN_SNK)
unnamed: R157.2, U12.9 (DISCH)
unnamed: R161.2, R163.2, U14.2 (UV1)
unnamed: R163.1, R164.1, U14.3 (OV1)
unnamed: R165.2, R166.1, U14.4 (UV2)
unnamed: R166.2, R167.1, U14.5 (OV2)
PD_VDD: C152.1, D34.5 (G), D35.1, Q9.5 (D), Q10.5, Q10.6, R157.1, R165.1, U14.16 (V2)
STUSB4500_AB_SIDE: R146.1, U12.17 (A_B_SIDE)
STUSB4500_ALERT: R155.1, U12.19 (~ALERT)
STUSB4500_ATTACH: R152.1, U12.11 (ATTACH)
STUSB4500_GPIO: R151.1, U12.15 (GPIO)
STUSB4500_SCL: R153.1, U12.7 (SCL); also elsewhere on the board
STUSB4500_SDA: R154.1, U12.8 (SDA); also elsewhere on the board
USB_PD_DISABLE: U12.6 (RESET)
VDD: C153.1, Q10.7, Q10.8, Q11.7, Q11.8, U14.15 (VOUT); also elsewhere on the board

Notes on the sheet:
9...20 VDC
9-20V, lower priority
USB-C PD
Auxiliary Power Control
Internal regulators.
AUX Power input
9-20V, higher priority

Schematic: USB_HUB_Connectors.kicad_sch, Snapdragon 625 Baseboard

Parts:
C94, C102, C103, C118, C120, C121, C122, C123, C124, C125, C126, C127, C128, C129, C131, C134, C140, C141, C147, C148, C149, C150, C151: C_100n_0402; 0402-cap; MPN GRM155R61H104KE14D
C119: C_4u7_0402; 0402-cap; MPN GRM155R61A475MEAAD
C130, C136: C_1u_0402; 0402-cap; MPN C1005X6S1A105K050BC
C132, C137, C160: C_10u_0402; 0402-cap; MPN CC0402MRX5R5BB106
C133, C135: C_15p_0402; 0402-cap; MPN MC0402N150J500CT
C139, C161, C170: C_100u_0805; 0805-cap; MPN GRM21BR60J107ME15L
D24: KP-1608EC; LED_0603; MPN KP-1608EC
D25, D26, D27, D28, D31, D32: PUSB3F96X_PASS; PUSB3F96X; MPN PUSB3F96X
FB2: BLM18EG221SN1D; 0603; MPN BLM18EG221SN1D
IC4: AP22652W6-7; SOT-23-6; MPN AP22652W6-7
J10, J11: E8124-015-01; USB-C_Female_E8124-015-01; MPN E8124-015-01
R112, R122, R124, R130, R133, R134, R135, R136, R137, R174: R_0R_0402; 0402-res; MPN ERJ2GE0R00X
R113: R_12k_1%_0603; 0603-res; MPN MCWR06X1202FTL
R114, R115, R116, R117, R118: R_20k_0402; 0402-res; MPN CRCW040220K0FKED
R119, R120: R_200k_0402; 0402-res; MPN RC0402FR-07200KL
R121: R_1M0_0402; 0402-res; MPN CRG0402F1M0
R123, R125, R131, R132, R138, R139, R140, R141: R_56k_0402; 0402-res; MPN CRCW040256K0FKED
R171: R_10k_0402; 0402-res; MPN CRCW040210K0FKEDHP
R172: R_470R_0402; 0402-res; MPN CRCW0402470RFKED
R173: R_12k4_0402; 0402-res; MPN ERJ2RKF1242X
TP13, TP14, TP15, TP16, TP17, TP18, TP19, TP20, TP23, TP24: TP_SMD_1_5MM; TP-R-1.5
U15: USB57442G; QFN40P700X700X100-57N; MPN USB5744
Y2: ABM8G-25.000MHZ-B4Y-T; KX-7; MPN ABM8G-25.000MHZ-B4Y-T

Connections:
1V2_SYS: C120.2, C121.2, C123.2, C125.2, C127.2, C129.2, C131.2, C134.2, C136.1, C137.1, U15.5 (VDD12), U15.12 (VDD12), U15.15 (VDD12), U15.21 (VDD12), U15.28 (VDD12), U15.33 (VDD12), U15.43 (VDD12), U15.49 (VDD12); also elsewhere on the board
3V3_SYS: C118.1, C119.1, C122.1, C124.1, C126.1, C128.1, C130.2, C132.2, R118.1, U15.16 (VDD33), U15.31 (VDD33), U15.37 (VBUS_DET/GPIO16), U15.44 (VDD33), U15.55 (VDD33); also elsewhere on the board
5V0_SYS: C160.1, IC4.1 (IN), R171.1, R172.1, R174.1; also elsewhere on the board
/USB_HUB_Connectors/5V0_USB: C103.1, C139.1, C151.2, C170.2, FB2.2, J10.A4, J10.A9, J10.B4, J10.B9, J11.A4, J11.A9, J11.B4, J11.B9, R123.1, R131.1, R138.1, R140.1, R174.2, TP20.1
/USB_HUB_Connectors/HUB_XTALI: C133.2, R121.1, U15.54 (XTALI/CLK_IN), Y2.1
/USB_HUB_Connectors/HUB_XTALO: C135.2, R121.2, U15.53 (XTALO), Y2.3
/USB_HUB_Connectors/SPI_CE: R119.2, TP14.1, U15.41 (SPI_CE_N/CFG_NON_REM/GPIO7)
/USB_HUB_Connectors/SPI_CLK: TP16.1, U15.38 (SPI_CLK/SMCLK/GPIO4)
/USB_HUB_Connectors/SPI_DI: R120.2, TP15.1, U15.40 (SPI_DI/CFG_BC_EN/GPIO9)
/USB_HUB_Connectors/SPI_DO: TP17.1, U15.39 (SPI_DO/SMDAT/GPIO5)
/USB_HUB_Connectors/USB_C1_CC1: J10.A5, R123.2, R125.1
/USB_HUB_Connectors/USB_C1_CC2: J10.B5, R131.2, R132.1
/USB_HUB_Connectors/USB_C1_D1_N: D27.4 (CH3), D27.7 (CH3), J10.A7, U15.9 (USB2DN_DM2/PRT_DIS_M2)
/USB_HUB_Connectors/USB_C1_D1_P: D27.5 (CH4), D27.6 (CH4), J10.A6, U15.8 (USB2DN_DP2/PRT_DIS_P2)
/USB_HUB_Connectors/USB_C1_D2_N: D28.4 (CH3), D28.7 (CH3), J10.B7, U15.2 (USB2DN_DM1/PRT_DIS_M1)
/USB_HUB_Connectors/USB_C1_D2_P: D28.5 (CH4), D28.6 (CH4), J10.B6, U15.1 (USB2DN_DP1/PRT_DIS_P1)
/USB_HUB_Connectors/USB_C1_SS_C_RX1_N: D28.1 (CH1), D28.10 (CH1), J10.B10, R133.2
/USB_HUB_Connectors/USB_C1_SS_C_RX1_P: D28.2 (CH2), D28.9 (CH2), J10.B11, R130.2
/USB_HUB_Connectors/USB_C1_SS_C_RX2_N: D27.2 (CH2), D27.9 (CH2), J10.A10, R124.2
/USB_HUB_Connectors/USB_C1_SS_C_RX2_P: D27.1 (CH1), D27.10 (CH1), J10.A11, R122.2
/USB_HUB_Connectors/USB_C1_SS_C_TX1_N: C102.1, D25.4 (CH3), D25.7 (CH3), J10.A3
/USB_HUB_Connectors/USB_C1_SS_C_TX1_P: C94.1, D25.5 (CH4), D25.6 (CH4), J10.A2
/USB_HUB_Connectors/USB_C1_SS_C_TX2_N: C140.1, D25.2 (CH2), D25.9 (CH2), J10.B3
/USB_HUB_Connectors/USB_C1_SS_C_TX2_P: C141.1, D25.1 (CH1), D25.10 (CH1), J10.B2
/USB_HUB_Connectors/USB_C1_SS_RX1_N: R133.1, U15.14 (USB3DN_RXDM2)
/USB_HUB_Connectors/USB_C1_SS_RX1_P: R130.1, U15.13 (USB3DN_RXDP2)
/USB_HUB_Connectors/USB_C1_SS_RX2_N: R124.1, U15.7 (USB3DN_RXDM1)
/USB_HUB_Connectors/USB_C1_SS_RX2_P: R122.1, U15.6 (USB3DN_RXDP1)
/USB_HUB_Connectors/USB_C1_SS_TX1_N: C102.2, U15.11 (USB3DN_TXDM2)
/USB_HUB_Connectors/USB_C1_SS_TX1_P: C94.2, U15.10 (USB3DN_TXDP2)
/USB_HUB_Connectors/USB_C1_SS_TX2_N: C140.2, U15.4 (USB3DN_TXDM1)
/USB_HUB_Connectors/USB_C1_SS_TX2_P: C141.2, U15.3 (USB3DN_TXDP1)
/USB_HUB_Connectors/USB_C2_CC1: J11.A5, R138.2, R139.1
/USB_HUB_Connectors/USB_C2_CC2: J11.B5, R140.2, R141.1
/USB_HUB_Connectors/USB_C2_D1_N: D31.1 (CH1), D31.10 (CH1), J11.A7, U15.18 (USB2DN_DM3/PRT_DIS_M3)
/USB_HUB_Connectors/USB_C2_D1_P: D31.2 (CH2), D31.9 (CH2), J11.A6, U15.17 (USB2DN_DP3/PRT_DIS_P3)
/USB_HUB_Connectors/USB_C2_D2_N: D26.2 (CH2), D26.9 (CH2), J11.B7, U15.25 (USB2DN_DM4/PRT_DIS_M4)
/USB_HUB_Connectors/USB_C2_D2_P: D26.1 (CH1), D26.10 (CH1), J11.B6, U15.24 (USB2DN_DP4/PRT_DIS_P4)
/USB_HUB_Connectors/USB_C2_SS_C_RX1_N: D31.4 (CH3), D31.7 (CH3), J11.B10, R137.2
/USB_HUB_Connectors/USB_C2_SS_C_RX1_P: D31.5 (CH4), D31.6 (CH4), J11.B11, R136.2
/USB_HUB_Connectors/USB_C2_SS_C_RX2_N: D32.2 (CH2), D32.9 (CH2), J11.A10, R135.2
/USB_HUB_Connectors/USB_C2_SS_C_RX2_P: D32.1 (CH1), D32.10 (CH1), J11.A11, R134.2
/USB_HUB_Connectors/USB_C2_SS_C_TX1_N: C149.1, D26.4 (CH3), D26.7 (CH3), J11.A3
/USB_HUB_Connectors/USB_C2_SS_C_TX1_P: C147.1, D26.5 (CH4), D26.6 (CH4), J11.A2
/USB_HUB_Connectors/USB_C2_SS_C_TX2_N: C150.1, D32.4 (CH3), D32.7 (CH3), J11.B3
/USB_HUB_Connectors/USB_C2_SS_C_TX2_P: C148.1, D32.5 (CH4), D32.6 (CH4), J11.B2
/USB_HUB_Connectors/USB_C2_SS_RX1_N: R137.1, U15.23 (USB3DN_RXDM3)
/USB_HUB_Connectors/USB_C2_SS_RX1_P: R136.1, U15.22 (USB3DN_RXDP3)
/USB_HUB_Connectors/USB_C2_SS_RX2_N: R135.1, U15.30 (USB3DN_RXDM4)
/USB_HUB_Connectors/USB_C2_SS_RX2_P: R134.1, U15.29 (USB3DN_RXDP4)
/USB_HUB_Connectors/USB_C2_SS_TX1_N: C149.2, U15.20 (USB3DN_TXDM3)
/USB_HUB_Connectors/USB_C2_SS_TX1_P: C147.2, U15.19 (USB3DN_TXDP3)
/USB_HUB_Connectors/USB_C2_SS_TX2_N: C150.2, U15.27 (USB3DN_TXDM4)
/USB_HUB_Connectors/USB_C2_SS_TX2_P: C148.2, U15.26 (USB3DN_TXDP4)
GND: C103.2, C118.2, C119.2, C120.1, C121.1, C122.2, C123.1, C124.2, C125.1, C126.2, C127.1, C128.2, C129.1, C130.1, C131.1, C132.1, C133.1, C134.1, C135.1, C136.2, C137.2, C139.2, C151.1, C160.2, C161.2, C170.1, D25.3 (GND), D25.8 (GND), D26.3 (GND), D26.8 (GND), D27.3 (GND), D27.8 (GND), D28.3 (GND), D28.8 (GND), D31.3 (GND), D31.8 (GND), D32.3 (GND), D32.8 (GND), IC4.2 (GND), J10.A1, J10.A12, J10.B1, J10.B12, J10.SH, J11.A1, J11.A12, J11.B1, J11.B12, J11.SH, R112.1, R113.1, R114.1, R115.1, R116.1, R117.1, R119.1, R120.1, R125.2, R132.2, R139.2, R141.2, R173.2, U15.57 (VSS), Y2.2, Y2.4; also elsewhere on the board
unnamed: C161.1, FB2.1, IC4.6 (OUT)
unnamed: D24.1, R172.2
unnamed: D24.2, IC4.4 (~FAULT)
unnamed: IC4.3 (EN), R171.2
unnamed: IC4.5 (ILIM), R173.1
unnamed: J10.A8, TP18.1
unnamed: J10.B8, TP19.1
unnamed: J11.A8, TP23.1
unnamed: J11.B8, TP24.1
unnamed: R112.2, TP13.1, U15.52 (ATEST)
unnamed: R113.2, U15.56 (RBIAS)
unnamed: R114.2, U15.36 (PRT_CTL1)
unnamed: R115.2, U15.35 (PRT_CTL2)
unnamed: R116.2, U15.34 (PRT_CTL3)
unnamed: R117.2, U15.32 (PRT_CTL4/GANG_PWR)
unnamed: R118.2, U15.42 (RESET_N)
SoM_USB3_RX_N: U15.48 (USB3UP_TXDM); also elsewhere on the board
SoM_USB3_RX_P: U15.47 (USB3UP_TXDP); also elsewhere on the board
SoM_USB3_TX_N: U15.51 (USB3UP_RXDM); also elsewhere on the board
SoM_USB3_TX_P: U15.50 (USB3UP_RXDP); also elsewhere on the board
USB_HUB_N: U15.46 (USB2UP_DM); also elsewhere on the board
USB_HUB_P: U15.45 (USB2UP_DP); also elsewhere on the board

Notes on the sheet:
ESD Protection
USB-C Connectors
USB HUB
USB-C connector 2
USB-C connector 1
USB Load Switch

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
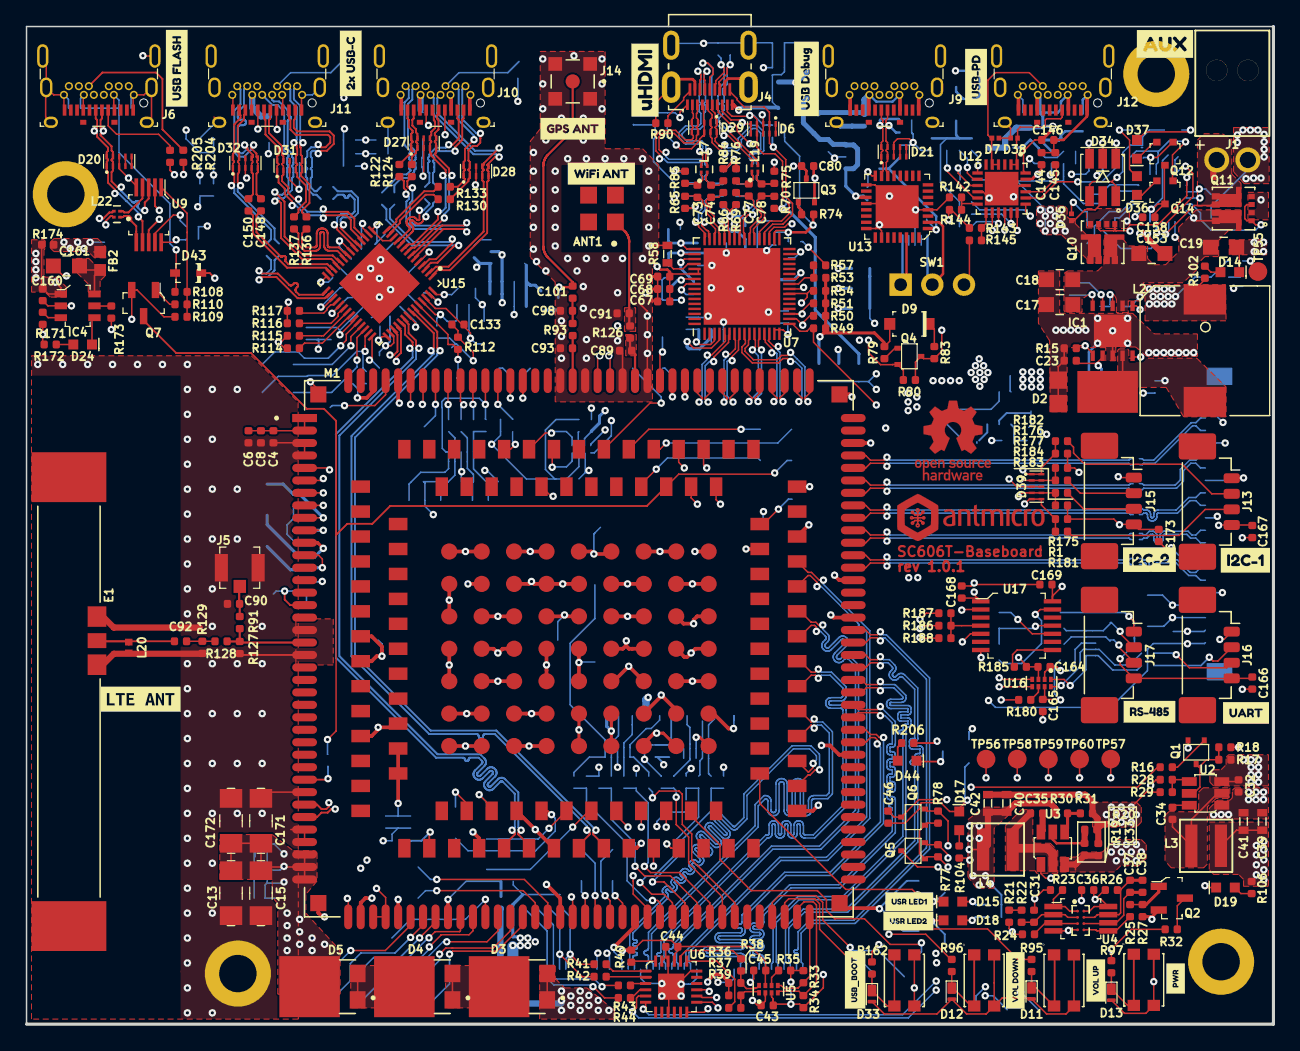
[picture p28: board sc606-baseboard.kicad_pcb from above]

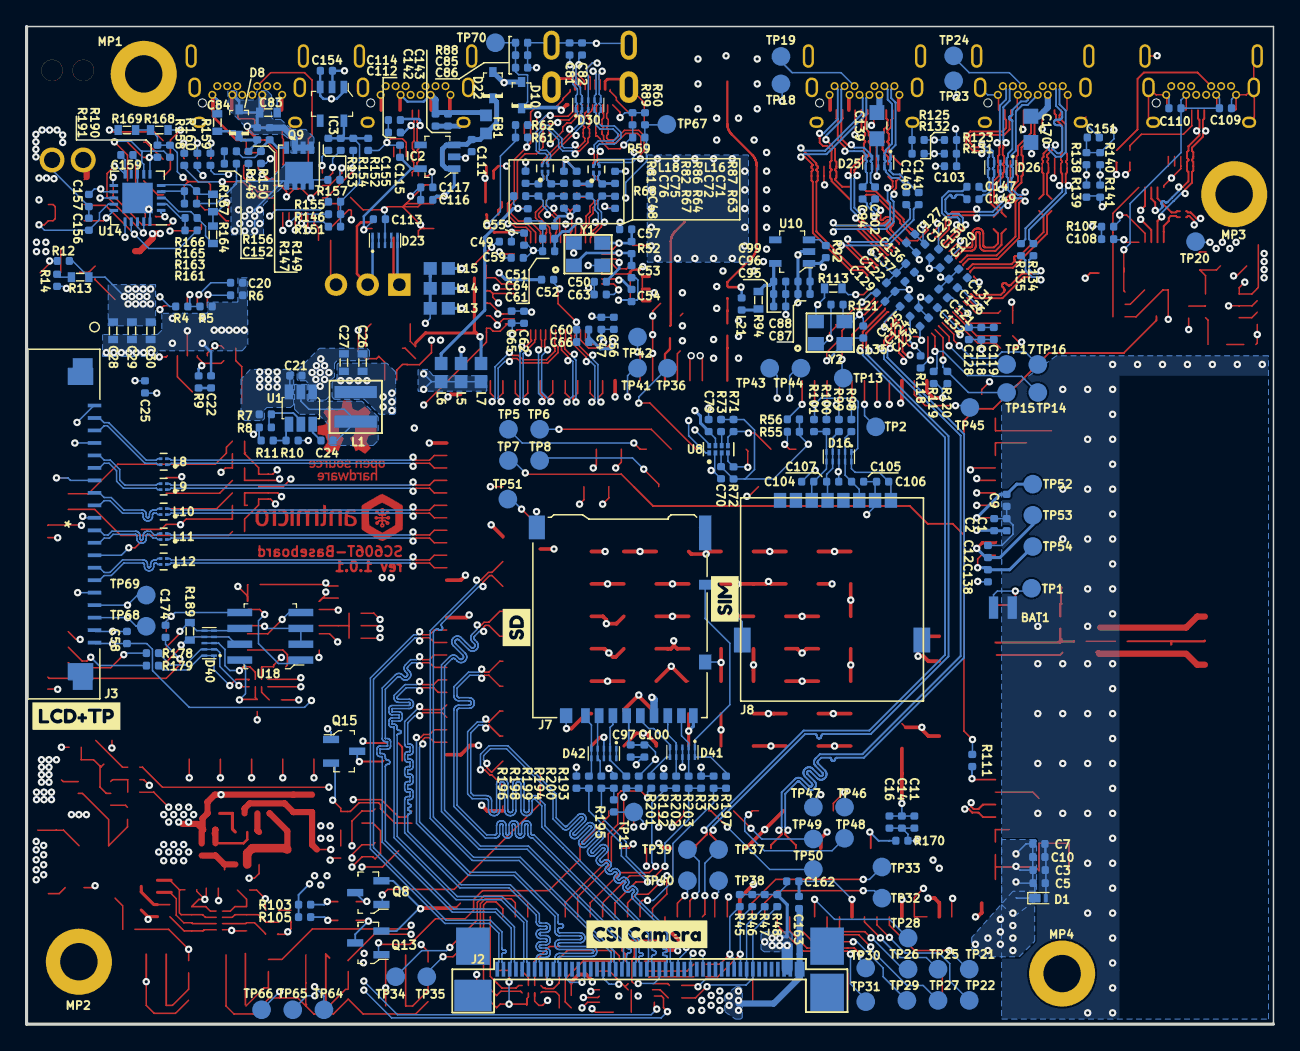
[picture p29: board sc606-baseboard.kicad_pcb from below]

Board: 6 copper layers, 100.0 x 80.0 mm, 604 parts (328 on the bottom side), 437 nets.

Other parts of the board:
D3, D4, D5: V8PM45-M3_H; TO-277A
kibuzzard-620F6B6A, kibuzzard-620F6BA8, kibuzzard-620F6C9E, kibuzzard-620F6CD0, kibuzzard-620F6D4D, kibuzzard-620F6D7B, kibuzzard-620F6D8B, kibuzzard-620F6D37, kibuzzard-620F6DAB, kibuzzard-620F6E02, kibuzzard-620F6E12, kibuzzard-620F6E26, kibuzzard-620F6E33, kibuzzard-620F6EEA, kibuzzard-620F7ADA, kibuzzard-620F7AEB, kibuzzard-620F7AFE, kibuzzard-620F7B0C, kibuzzard-620F7B15, kibuzzard-620F7B41, kibuzzard-620F79D2, kibuzzard-6200CC83, kibuzzard-6200CCB6: G***; label

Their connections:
5V0_SYS: D3.1, D3.2; also elsewhere on the board
unnamed: D3.3, D4.1, D4.2
unnamed: D4.3, D5.1, D5.2
V_SOM: D5.3; also elsewhere on the board

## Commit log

2022-05-10 Creating empty kicad project
    [sc606-baseboard.kicad_pcb, sc606-baseboard.sch]
2022-05-10 Add sub-sheets to the design
    [som.sch]
2022-05-10 update of block diagram, creation of sub-sheets
    [cameras_module.sch, display_module.sch, peripherals.sch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]
2022-05-10 Creating schematic of SoM power supply elements
    [som.sch]
2022-05-10 Add scheme for SIM card
    [cameras_module.sch, display_module.sch, peripherals.sch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]
2022-05-10 Scheme for 5V Main DC/DC converter created
    [power_supply.sch, som.sch]
2022-05-10 Added scheme for 5V to 3V3 buck
    [power_supply.sch]
2022-05-10 Added 5V to 4V SoM power supply and 5V to 3V3 camera power supply
    [power_supply.sch, som.sch]
2022-05-10 Creating schemas for camera FFC, connecting related pins to SoM, schema of I2C MUX and voltage transceiver; Adding RESET to power supplies; connecting to SoM 1v8 power output
    [cameras_module.sch, power_supply.sch, som.sch]
2022-05-10 Creating schema for SD card connection
    [cameras_module.sch, peripherals.sch, som.sch]
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2022-05-10 Added TP Interface. Connector must yet be added
    [peripherals.sch, som.sch]
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2022-05-10 Added keypads and no flag connections to unused pins
    [cameras_module.sch, display_module.sch, peripherals.sch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]
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2022-05-10 Finished connection to HDMI interface. Adjustments after Update of LT9611 symbol
    [cameras_module.sch, display_module.sch, peripherals.sch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]
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2022-05-10 Added corrections to schemas after review
    [cameras_module.sch, display_module.sch, peripherals.sch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]
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2022-05-10 Added USB switch along with USB flash connector
    [USB.sch, peripherals.sch, som.sch]
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2022-05-10 Added USC-C connector and first option of debug UART
    [USB.sch, sc606-baseboard.sch, som.sch]
2022-05-10 Chip changed for Debug UART. Changed connector from USB-A to USB-C
    [USB.sch, cameras_module.sch, display_module.sch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]
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2022-05-10 Added footprint of 2x USB-A stacked. Added connections to USB HUB.
    [USB.sch, USB_HUB_Connectors.sch, USB_flash_debug.sch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]
2022-05-10 Started placing main components on PCB. Change of RT battery model and USB flash connector
    [USB_HUB_Connectors.sch, USB_flash_debug.sch, cameras_module.sch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]
2022-05-10 Adding missing 3D models of components
    [sc606-baseboard.kicad_pcb]
2022-05-10 Removed mounting pad for GNSS, changed main antenna model, added wifi ufl connector
    [peripherals.sch]
2022-05-10 Added USB A and C double stack connector
    [USB_HUB_Connectors.sch, peripherals.sch, sc606-baseboard.kicad_pcb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]
2022-05-10 Added connections of both USB A & C connectors
    [USB_HUB_Connectors.sch]
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2022-05-10 Added buck converters for 3v3 sys, 3v3 cam, 1v2 lontium. Added auto power-on
    [sc606-baseboard.kicad_pcb]
2022-05-10 FFC and general display camera connectors distributed on board
    [USB_HUB_Connectors.sch, USB_flash_debug.sch, cameras_module.sch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]
2022-05-10 Added USB BOOT, placed USR LEDs and buttons, connected Test Points
    [peripherals.sch, sc606-baseboard.kicad_pcb, som.sch]
2022-05-10 Prepared layout of USB flash and debug components
    [USB_flash_debug.sch, sc606-baseboard.kicad_pcb]
2022-05-10 Started rearrangement of components. USB connectors changed to 2xUSB-C
    [USB_HUB_Connectors.sch, display_module.sch, peripherals.sch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]
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2022-05-10 USB Debug changed to micro USB. Started modifications on shortening board by 1cm
    [USB_HUB_Connectors.sch, USB_flash_debug.sch, peripherals.sch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]
2022-05-10 Finished placement after shortening board by 1cm
    [USB_HUB_Connectors.sch, USB_flash_debug.sch, display_module.sch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]
2022-05-10 Changed USB flash and debug to USB-C. Prepared place for USB PD. Minor modifications of components position
    [USB-PD.sch, USB_HUB_Connectors.sch, USB_flash_debug.sch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]
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2022-05-10 Changed barrel jack model, added power path controller
    [USB-PD.sch, sc606-baseboard.kicad_pcb]
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2022-05-10 Modified position of buttons, SD, SIM and USB connectors. Modified LT9611 footprint
    [sc606-baseboard.kicad_pcb]
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2022-05-10 Connected differential signals from camera modules and LCD display. Without checking track lengths
    [USB-PD.sch, USB_HUB_Connectors.sch, sc606-baseboard.kicad_pcb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]
2022-05-10 Routed CAM, LCD, USB Debug differential pairs with tuning
    [power_supply.sch, sc606-baseboard.kicad_pcb]
2022-05-10 Routed USB flash and both USB connectors differential signals with tuning
    [USB-PD.sch, USB_HUB_Connectors.sch, USB_flash_debug.sch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]
2022-05-10 Finished routing differential pairs. Half of them already tuned
    [differential_pairs_calculations.ods, sc606-baseboard.kicad_pcb]
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2022-05-10 Connected all signals for USB Flash and USB-C connectors
    [USB_HUB_Connectors.sch, sc606-baseboard.kicad_pcb]
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2022-05-10 Correction in connecting GND pads using Vias, not tracks. Connecting Lontium to power supply
    [sc606-baseboard.kicad_pcb]
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2022-05-10 Corrected DRC errors
    [sc606-baseboard.kicad_pcb]
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2022-05-10 Cleaned and added testpoints to spoer supply sch
    [power_supply.sch]
2022-05-10 Solved DRC problems with HDMI and CSI
    [power_supply.sch, sc606-baseboard.kicad_pcb]
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2022-05-10 Tuned and corrected USB lines
    [sc606-baseboard.kicad_pcb]
2022-05-10 Corrected power supplies. Change of TP to 1,5mm
    [USB_HUB_Connectors.sch, cameras_module.sch, peripherals.sch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]
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2022-05-10 Cleaned/fixed USB flash debug sch
    [USB_flash_debug.sch]
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2022-05-10 Corrected serial interface schemas
    [sc606-baseboard.kicad_pcb, serial_and_cameras_interfaces.sch, som.sch]
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2022-05-10 Removed DRC errors
    [sc606-baseboard.kicad_pcb]
2022-05-10 Fixed DRC and other minor errors
    [power_supply.sch, sc606-baseboard.kicad_pcb]
2022-05-10 Corrected errors from feedback. Added board name, version, Antmicro and OSHW logo, connector labels, button and LED descriptions
    [USB-PD.sch, peripherals.sch, power_supply.sch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]
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2022-05-10 Changed name of board from Kibuzzard to Text
    [sc606-baseboard.kicad_pcb]
2022-05-10 Debug connector moved away from chip. Corrected wifi antenna ground plane. Added arcs on GNSS and WiFi tracks
    [USB_HUB_Connectors.sch, sc606-baseboard.kicad_pcb]
2022-05-10 Corrected warnings from EC
    [sc606-baseboard-B_Adhes.gbr, sc606-baseboard-B_CrtYd.gbr, sc606-baseboard-B_Cu.gbr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]
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2022-05-10 Fix STUSB4500 VDD connection, fix DRC error
    [USB-PD.sch, sc606-baseboard.kicad_pcb]
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2022-05-10 Corrected footprint of Q10 and Q11. Used 'kmake loclib'
    [USB-PD.sch, USB_HUB_Connectors.sch, peripherals.sch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]
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2022-05-10 Replaced USB-C port footprint. Fixed traces after changes respectively to DRC.
    [sc606-baseboard.kicad_pcb]
2022-05-10 Added alternated footprint for U4. Rev bumped to 1.0.1
    [USB-PD.sch, USB_HUB_Connectors.sch, USB_flash_debug.sch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]
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2022-05-12 Connected STUSB4500 I2C to SoM. Exchanged ESD protection for SD card
    [peripherals.sch, sc606-baseboard.kicad_pcb, serial_and_cameras_interfaces.sch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]
2022-05-25 Removed Q8, R111. SoM_USB_FLASH_ID changed from SoM's USB_ID to GPIO_1. Connected flash CC to SoM through 0R. Connected USB_VBUS to USB flash 5V via diode. SoM USB_ID connected to GPIO_1 through 0R
    [USB_flash_debug.sch, sc606-baseboard.kicad_pcb, som.sch]
2022-05-25 Added N-FETs to control USR_LEDs. Reconnected them to 3V3 power supply. Added LED indicating SoM turns on
    [USB-PD.sch, peripherals.sch, sc606-baseboard.kicad_pcb]
2022-07-15 Converted to KiCad 6. Corrected BUSes. Changed voltage supply for SOM. Checked DRC
    [USB-PD.kicad_sch, USB_HUB_Connectors.kicad_sch, USB_flash_debug.kicad_sch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]
2022-07-15 Cleared old files. Added 0R after DCDC converters
    [USB-PD.sch, USB_HUB_Connectors.sch, USB_flash_debug.sch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]
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

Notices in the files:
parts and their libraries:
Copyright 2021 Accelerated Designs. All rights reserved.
